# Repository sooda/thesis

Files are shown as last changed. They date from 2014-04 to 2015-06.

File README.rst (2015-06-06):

Multi-view stereo reconstruction for computer graphics content capture
======================================================================

Hello, this is my master's thesis work titled as above, and contains both the thesis text itself and some source code and electrical schematics developed during the work in Aalto University in 2014-2015.
For the occasional gibberish, consult a Finnish dictionary.
The technical "multi-view stereo reconstruction" is sometimes called "3D scanning": digitizing real-life object geometry from multiple photographs.
The practical work in this thesis was about building a rig for that purpose.
No reconstruction programs were written, unfortunately.
Try e.g. VisualSFM_ and MeshLab_ for that.

.. _VisualSFM: http://ccwu.me/vsfm/
.. _MeshLab: http://meshlab.sourceforge.net/

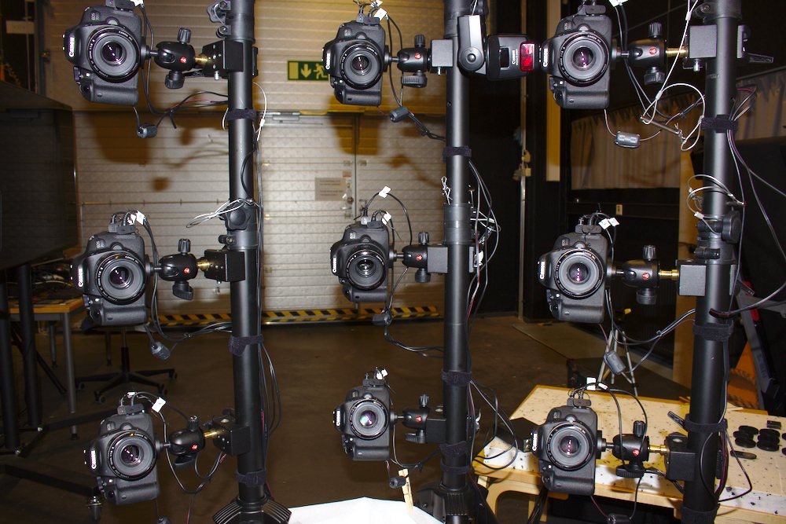
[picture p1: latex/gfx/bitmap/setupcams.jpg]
camera array


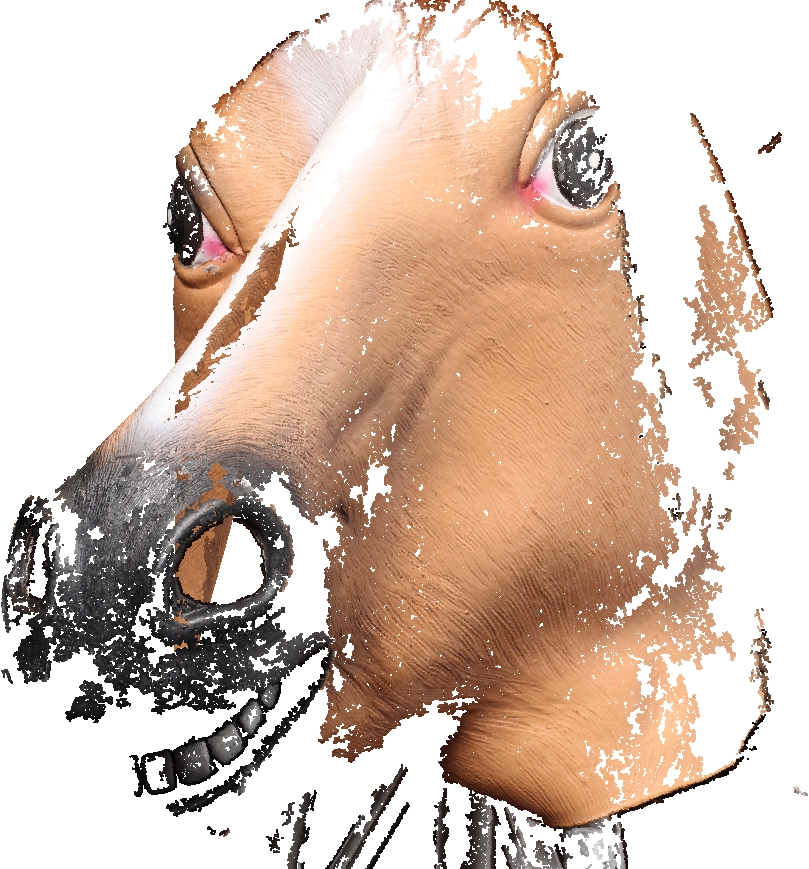
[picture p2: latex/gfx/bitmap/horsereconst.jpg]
horse mask rendering


Code
----

The thesis talks also about the background math, but the only code here is for controlling DSLRs remotely using gPhoto2_ in C++ and some shell scripts.
The tools were only tested using nine Canon EOS 700D cameras; no guarantees are given for others, but not much major changes are expected to be required.
I forgot to run valgrind on the final tool, so expect no warranty in memory leaks or any other errors.

.. _gPhoto2: http://gphoto.org/

The code here represents a prototype only, but it works for what was required, it's just not very polished.
I wrote a C++ wrapper for gphoto that is unimaginatively called *gpwrap*.
A preview tool (*gphotogrid*) downloads a live stream from each camera in parallel and allows the user to configure their parameters (aperture and such), with no significant performance optimizations or anything, as it's just a proof of concept.
The wrapper and the grid have been tested to work in recent versions of Linux and Mac OS X using the EOS 700Ds, but YMMV.
A more polished tool called `CaptureQuick`_ is developed on top of it by Daniel Thul; if you are going to use the wrapper for developing your own programs, or want the grid tool, look there too.
CaptureQuick still uses the wrapper written by me with only minor modifications (as of June 2015).
Expect it to grow further.

.. _CaptureQuick: https://github.com/dthul/capture-quick

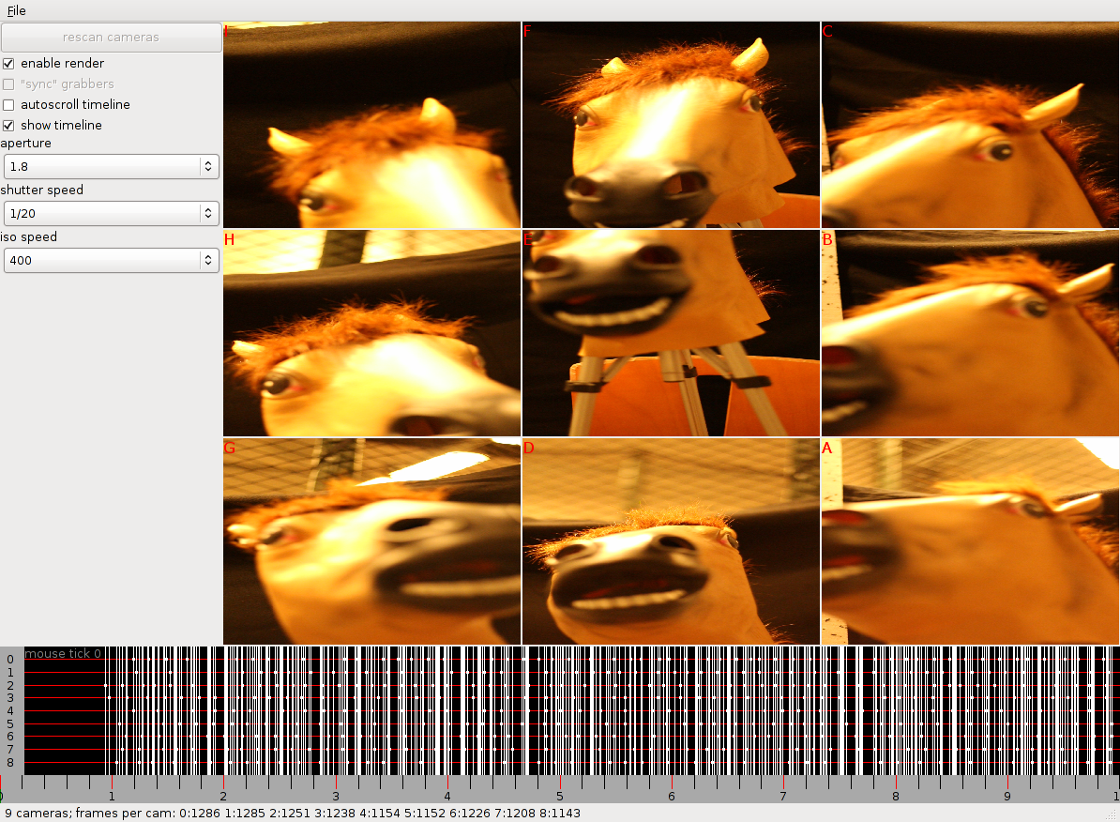
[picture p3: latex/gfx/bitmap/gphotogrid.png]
gphotogrid


Electronics
-----------

I built a simple remote tool for controlling the shutters of the nine cameras via a single usb-serial connection, in `arbitrary order`_ (typically simultaneously, though).
The control output goes directly to the 700Ds' shutter release inputs (a 2.5mm stereo jack).
The box has also a button for human interaction, and it's based on Nucleo-F401RE_, a simple STM32 board.
The schematics and the PCB are in EAGLE_ 7.0.0 format.
I named the thing *camsremote*.
No warranty.

.. _arbitrary order: https://www.youtube.com/watch?v=bDDnQzyOaFg
.. _Nucleo-F401RE: http://www.st.com/nucleoF401RE-pr
.. _EAGLE: http://www.cadsoftusa.com/eagle-pcb-design-software/

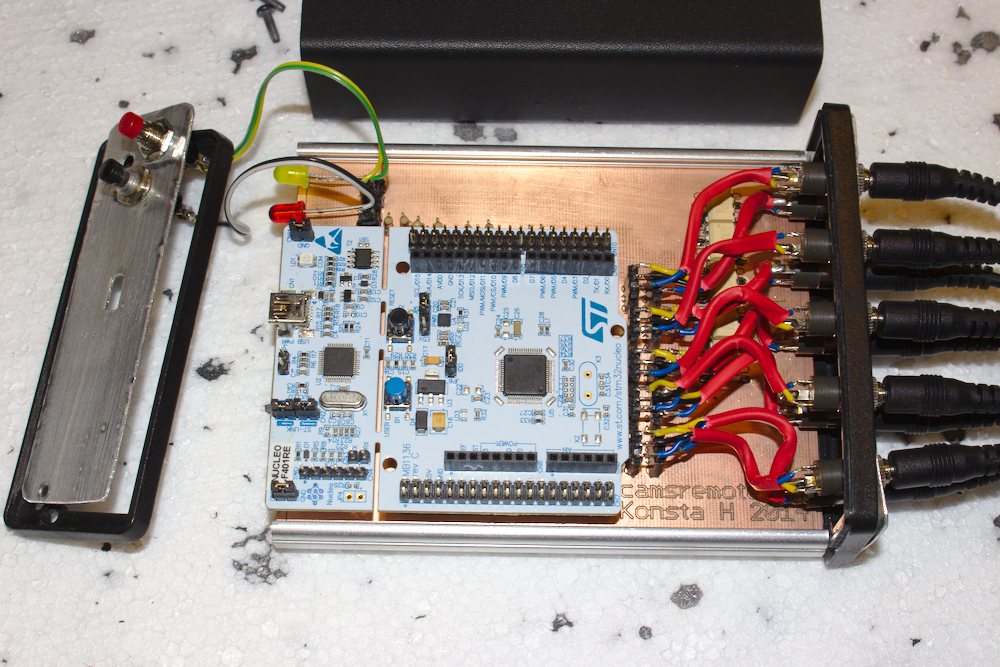
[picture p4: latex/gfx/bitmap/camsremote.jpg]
remote trigger tool


Abstract
--------

Rendering of photorealistic models is becoming increasingly feasible and important in computer graphics.
Due to the high amount of work in creating such models by hand, required by the need of high level of detail in geometry, colors, and animation, it is desirable to automate the model creation.
This task is realised by recovering content from photographs that describe the modeled subject from multiple viewpoints.
In this thesis, elementary theory on image acquisition and photograph-based reconstruction of geometry and colors is studied and recent research and software for graphics content reconstruction are reviewed.
Based on the studied background, a rig is built as a grid of nine off-the-shelf digital cameras, a custom remote shutter trigger, and supporting software.
The purpose of the rig is to capture high-quality photographs and video in a reliable and practical manner, to be processed in multi-view reconstruction programs.

The camera rig was configured to shoot small static subjects for experiments.
The resulting photos and video were then processed directly for the subject's geometry and color, with little or no image enhancements done.
Two typical reconstruction software pipelines were described and tested.
The rig was found to perform well for several subjects with little subject-specific tuning;
issues in the setup were analyzed and further improvements suggested based on the captured test models.
Image quality of the cameras was found to be excellent for the task, and most problems arose from uneven lighting and practical issues.
The developed rig was found to produce sub-millimeter scale accuracy in geometry and texture of subjects such as human faces.
Future work was suggested for lighting, video synchronization and study of state-of-the-art image processing and reconstruction algorithms.

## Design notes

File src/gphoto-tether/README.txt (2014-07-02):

Camera control scripts
======================

Some gphoto2 shell script fun. In alphabetical order:

camhook.sh:
	example for hooking captured files
camnames.sh:
	print a port-camname-mapping, or port of a single cam
cams.sh:
	list ports of all connected cameras
capture-by-camid.sh:
	capture tethered to <capname>/<camid>/<shotid>
capture-by-shotid.sh:
	capture tethered to <capname>/<shotid>/<camid>
config.sh:
	set common configuration parameters
	TODO: configuration tool for this?
	"./config.sh workaround": set only capture target to memory card,
	releases uilock if shutter is half-pressed to focus
configrepeatshot.sh:
	as above, for continuous cycle testing
forall.sh:
	run gphoto2 with given args for all connected cameras serially
forallp.sh:
	same as above, but in in parallel
interesting-settings.txt:
	settings for readconfig.sh, see below
multihax-order.py:
	interleave pictures taken from all cameras consecutively
multihax-run.sh:
	run the above in reverse cam order
	(if cams' shutter releases are connected so, needed a while ago)
post-download-by-camid.sh:
	download all previously shot files stored in the cameras to
	directories by camera name, in parallel; -DR is safe after this
rawprocess.sh:
	ufraw-batch converter to 2000x2000, run in a dir full of cr2's
readconfig.sh:
	read and copy settings from one camera to all others and dump
	the read data to a file for inspection, producing
	currentconfig.txt and calibsettings.sh
release-uilock.sh:
	run gphoto2 -L for all cams, this releases the locked buttons and
	blank screen that get stuck when fiddling with settings for some reason
shutters.sh:
	read shutter counters

delete all files recursively WITHOUT ASKING: ./forallp.sh -DR
  (appears to see only DCIM and MISC folders, ignores e.g. magic lantern)

list all files: ./forall.sh -L

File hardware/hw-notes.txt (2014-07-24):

hardware list:
	- 9x Canon EOS 700D
	- 9x Canon EF 50mm f/1.8 II lenses, no need to remove from the bodies
	- 9x Transcend 16GB memory cards, keep inside the cams
	- 9x Canon ACK-E8, power adapters because nobody wants to recharge batteries (that wire mess though...)
	- 3x D-link DUB-H4 usb hubs, remote powered but the power supplies don't seem to be needed for just the cams
	- 1x custom trigger box, connect with a mini usb
	- 9x wires for the cameras; usb to a hub, and 2,5mm stereo plug cable for the trigger
	- 4x Millenium LST-310 stand
	- 9x Manfrotto 494 ball head
	- 9x Manfrotto 035 Super Clamp, with Manfrotto 036-38 studs for attaching the ball heads to the stands
	- Lots of velcro straps

storage:
	- cases for cameras and other sensitive items
	- bags for the stands: one bag fits two
	- TODO: power cables, clamps, ballheads to stand bags or cases?

building:
	1. fix the stands where needed
	2. screw the cameras, ball heads and clamps together and to the stands
	3. connect the wires (power, usb, trigger) to the cameras; run them along the stands
	4. connect the power adapters to extension cords (can be replaced with batteries if using only for a few shots)
	5. connect the other ends of the trigger cables to the trigger box; connect a usb cable to the box
	6. use the velcro straps to fasten the dangling wires so that they stay away from the photos
	7. divide the hubs evenly for the cams, one hub per three or so; try to find different master hubs from a computer so that they would share the load well
	8. aim the cameras to the target, setup lighting and start shooting

unpacking:
	- just repeat the build steps in reverse order

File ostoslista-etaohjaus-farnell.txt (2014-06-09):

yht ~70 € (+ postit, kaikki euroopan varastoista).

10 * 3712552 (PRO SIGNAL - AV02019 - LEAD, 2.5MM STEREO PLG-PLG, 3M)
http://fi.farnell.com/pro-signal/av02019/lead-2-5mm-stereo-plg-plg-3m/dp/3712552

10 * 1200141 (LUMBERG - KLB 13 - SOCKET, 2.5MM JACK, CHASSIS)
http://fi.farnell.com/lumberg/klb-13/socket-2-5mm-jack-chassis/dp/1200141

2 * 2213347 (TWIN INDUSTRIES - TW-E41-1020 - BREADBOARD, SOLDERLESS, 830 TIE POINTS)
http://fi.farnell.com/twin-industries/tw-e41-1020/breadboard-solderless-830-tie-points/dp/2213347

1 * 2394223 (STMICROELECTRONICS - NUCLEO-F401RE - NUCLEO BOARD, STM32F401RET6 MCU)
http://fi.farnell.com/stmicroelectronics/nucleo-f401re/nucleo-board-stm32f401ret6-mcu/dp/2394223

1 * 1201477 (CIF - AJP16 - RPB PAD PROTOBOARD 100X160)
http://fi.farnell.com/cif/ajp16/rpb-pad-protoboard-100x160/dp/1201477

50 * 9339299 (MULTICOMP - MCF 0.25W 220R - RESISTOR, CARBON FILM, 220R, 0.25W, 5%)
http://fi.farnell.com/multicomp/mcf-0-25w-220r/resistor-carbon-film-220r-0-25w/dp/9339299

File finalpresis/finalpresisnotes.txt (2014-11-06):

1
first slide
- hi this is about 3d scanning

1
preintro
- cg evolves
- increasingly deeper demand for hq content
- parts of those two technologies combined

1
contents
- blah blah

2
motivation
- computer hw becoming faster and faster
- lod massive, development not going to stop
- generating content manually impossible
- static geometry is difficult enough
- and then there is computer animation
- -> just capture a subject in real life
- and reproduce that

2
imaging
- cameras are complicated.
- whole imaging process is complex
- especially to capture only surface color..
- instead of what it looks like in a naive environment
- diffuse (uniform) lighting etc
- cg, material models, imitate light reflection (pic)
- trying to produce color data for those models
- static imaging is difficult? how about video then?

4
video
- all right
- what is video anyway? frames in sequence
- assume photographed subject moving, otherwise no point
- capture N fps, integrating light fixed time
- and so we get many problems too
- motion blur: fast subject smeared as integrated
- rolling shutter: imaging sensor read slowly
- line skipping: aliasing etc: not every line used
- last but not least sync as group maybe impossible

5
simplified methods
- a camera is a projective object
- formulate properly -> divide to steps
- assume linear camera etc
- assume sth on scene
- detect distinct corners/features
- match features
- reconstruct depth for matches
- reconstruct surface

6
depth from disparity
- calculating depth not that complicated
- take two matching points, both projected linearly
- know camera baseline, poses, triangulate
- but wait, there is more
- how match in the first place?
- noise, outliers etc
- full pipeline does much more

7
stereo system
- step one. have many cameras.
- calibrate the cameras
- known geometry/autodetect matches
- system of eqs, similar projections
- depth/disparity > need poses for triangulation
- N views given -> match, triangulate, filter

8
practical reconstruction system
- now, what i built
- given knowledge, build *practical* 3d scanner
- interest in face, maybe animation
- looked in camera types, programs -> conclusions

9
rig implementation
- entry-level dslr
- controllable, cheap, hquality; cant sync video
- wired remote for still sync and shoot
- support magic lantern 3rd party fw addon
- supports, wiring
- cam ctrl utilities etc

10
remote trigger tool
- cams support wired remote
- built tool for concurrent shooting
- small cheap micro, usb conn
- commercial ones wireless, expensive, unknown
- did this for open design and testing

11
software
- sw consists of cam support, reconstruction then
- not much camera ctl libraries there
- just remote shoot, cam cfg in my work
- gphoto2, open source, image download etc

12
previewer
- graphical grid, simultaneous liveview
- individually with viewfinder

12
control
- some of params on the right
- gphoto also cli tool
- wrote small tool for concurrent fast download
- also python for remote box

13
experiments
- sync capabilities and scans
- performing full end-to-end pipeline in sw

14
source data
- 3 of 9 pics for full head scan

14
output geometry
- plain reconstructed geometry rendered
- point cloud, tex mesh
- poor quality in facial hair

15
textures
- color: different map types
- one preserves the original photographs
- othereasily modifiable image

15
hand
- this is my hand scanned
- occluded areas, not seen by all

15
legos
- missing texture is obviously not recoverable

16
rubber mask
- uniform colors bad, otherwise nice

16
level of detail
- cropped part of one photo, its reconstruction
- pore-level pixels
- note geometric detail near the eyes
- some wrinkles only in color, not geometry

16
issues
- video sync is problematic
- once started, cannot sync frames
- require no shadows, reflections
- needs manual processing to be useful
- the cameras sometimes misbehave a little

17
future work
- survey current state-art algos, high lod
- of course, use it for future study

18
conclusion
- that's it.
- my work: survey background, build 3d scanner
- quality nice and improvable from the current state
- i don't know what the future is going to offer

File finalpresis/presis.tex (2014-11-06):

\documentclass[first=purple,second=dgreen,logo=blueexc]{aaltoslides}

\usepackage[latin9]{inputenc}
\usepackage[T1]{fontenc}
\usepackage{graphicx}
\usepackage{amsfonts,amssymb,amsbsy,amsmath}
\usepackage{tikz}
\usepackage{url}
\usepackage{lastpage}
\usepackage{subfig}
\usepackage{fancyvrb}

\title{Multi-view stereo reconstruction for computer graphics content capture}

\author{Konsta Hölttä}
\institute{Master's thesis presentation\\
konsta.holtta@aalto.fi}

\aaltofootertext{MVS content capture}{Nov 7, 2014}{\arabic{page}/\pageref{LastPage}\ }

\date{Nov 7, 2014} % \today}

\graphicspath{ {gfx/} }

\newcommand{\kuva}[2]{\begin{figure}[h]
		
\end{figure}}

\newcommand{\simplefig}[4]{%
	\begin{figure}[#1]\begin{center}
		#2
		%\caption{#4}
		%\label{#3}
	\end{center}\end{figure}
}
% \simplegfx{pos-specifier}{width}{filename-and-labelname}{caption}
\newcommand{\simplegfx}[4]{%
	\simplefig{#1}{}{fig:#3}{#4}
}

\begin{document}

%%%%%%%%%%%%%%%%%%%%%%%%%%%%%%%%%%%%%%%%%%%%%%%%%%%%%%%%%%%%%%%%%%%%%%%%%%%%%%%%%%%%%%%%%%%%%

\aaltotitleframe

%%%%%%%%%%%%%%%%%%%%%%%%%%%%%%%%%%%%%%%%%%%%%%%%%%%%%%%%%%%%%%%%%%%%%%%%%%%%%%%%%%%%%%%%%%%%%

\begin{frame}{Multi-view stereo reconstruction for computer graphics content capture}
	\center 
	\begin{itemize}
		\item Interest in realistic content in computer graphics
		\item Computer graphics synthesizes images from geometric data
		\item Computer vision analyzes geometry from images
		\item This work: Scanning real life objects using several digital cameras simultaneously
	\end{itemize}
\end{frame}

%%%%%%%%%%%%%%%%%%%%%%%%%%%%%%%%%%%%%%%%%%%%%%%%%%%%%%%%%%%%%%%%%%%%%%%%%%%%%%%%%%%%%%%%%%%%%

\begin{frame}{Contents}
	\begin{columns}[c]
	\column{0.5\textwidth}
	\begin{itemize}
		\item Intro, motivation
		\item Imaging fundamentals
		\item 3D reconstruction
		\item Scanning rig implementation
		\item Results
		\item Conclusion
	\end{itemize}
	\column{0.5\textwidth}
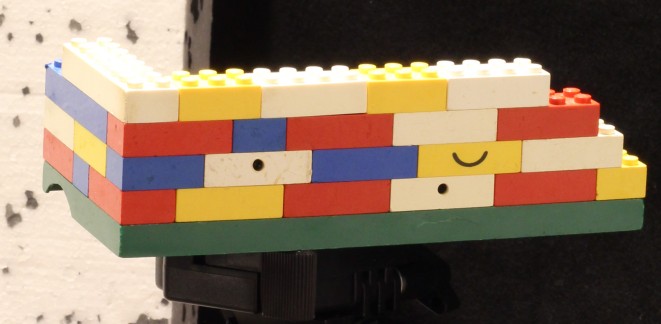
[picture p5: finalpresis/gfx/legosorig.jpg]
	\center 
	\end{columns}
\end{frame}

%%%%%%%%%%%%%%%%%%%%%%%%%%%%%%%%%%%%%%%%%%%%%%%%%%%%%%%%%%%%%%%%%%%%%%%%%%%%%%%%%%%%%%%%%%%%%

\begin{frame}{Motivation}
	\kuva{0.8}{ira-eyes}
	{ \centering { \footnotesize Digital Ira (NVIDIA), CGI} \par }
	\begin{itemize}
		\item The processing power of GPUs big and increases
		\item Able to process massive level of detail
		\item Creating content manually tedious, difficult to get right
		\item Digital cameras are really good today
		\item $\Rightarrow$ Scan the geometry and color using digital cameras
	\end{itemize}
\end{frame}

%%%%%%%%%%%%%%%%%%%%%%%%%%%%%%%%%%%%%%%%%%%%%%%%%%%%%%%%%%%%%%%%%%%%%%%%%%%%%%%%%%%%%%%%%%%%%

\begin{frame}{Imaging}
	\center 
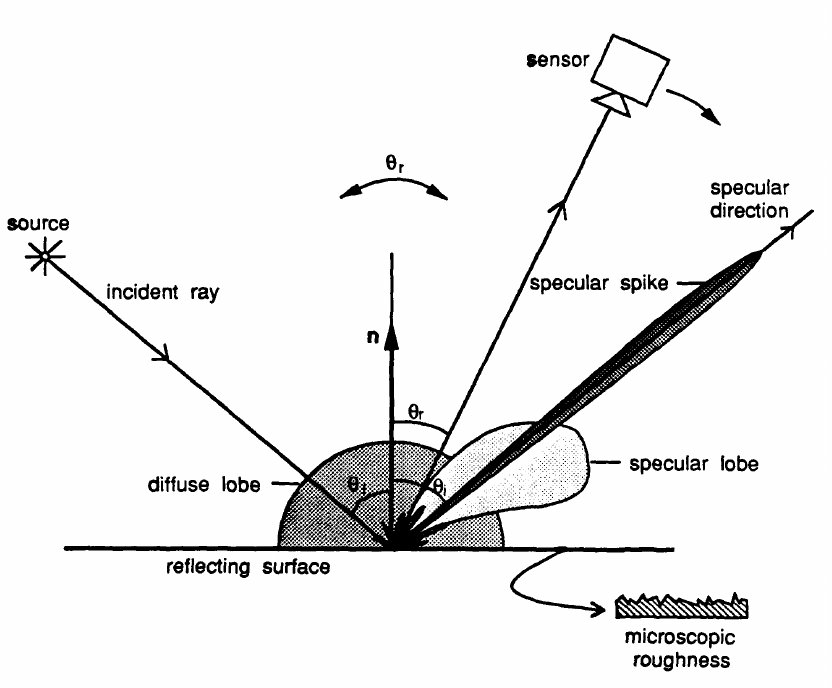
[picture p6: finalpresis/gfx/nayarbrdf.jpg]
	
	\begin{itemize}
		\item Lens systems, geometric distortion, color distortion, depth of field, image resolution, frame rate, motion blur, compression quality, ...
		\item Complete imaging pipeline is complex
		\item Light travels from subject to sensor, to digital file
		\item Assumed uniform lighting; still, non-shiny subject
		\item Video = consecutive image frames
	\end{itemize}
\end{frame}

%%%%%%%%%%%%%%%%%%%%%%%%%%%%%%%%%%%%%%%%%%%%%%%%%%%%%%%%%%%%%%%%%%%%%%%%%%%%%%%%%%%%%%%%%%%%%

\begin{frame}{Video}
	\begin{columns}[c]
	\column{0.5\textwidth}
	\begin{itemize}
		\item Frame after frame
		\item Moving subject
		\item Non-flickering lighting
		\item Motion blur
		\item Rolling shutter
		\item Line skipping
		\item Synchronization
	\end{itemize}
	\column{0.5\textwidth}
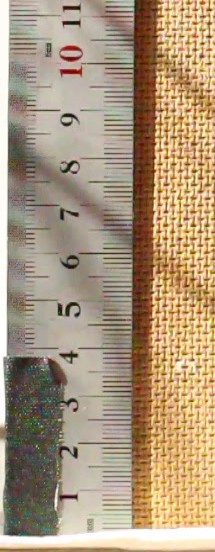
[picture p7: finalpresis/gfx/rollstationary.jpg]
	
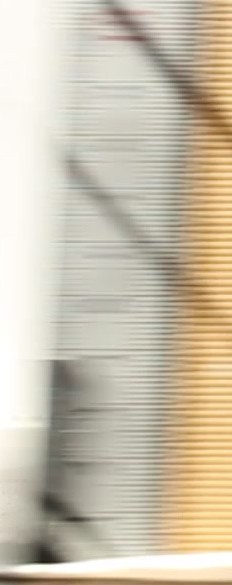
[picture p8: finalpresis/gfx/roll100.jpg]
	
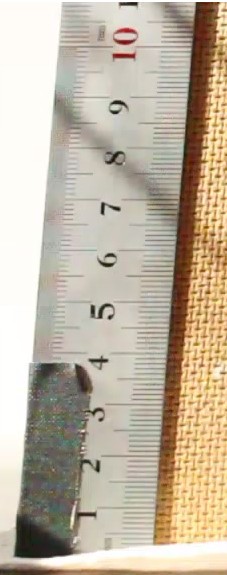
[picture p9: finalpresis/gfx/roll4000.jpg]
	
	\end{columns}
\end{frame}

%%%%%%%%%%%%%%%%%%%%%%%%%%%%%%%%%%%%%%%%%%%%%%%%%%%%%%%%%%%%%%%%%%%%%%%%%%%%%%%%%%%%%%%%%%%%%

\begin{frame}{Simplified methods}
	\center 
	\begin{itemize}
		\item Linear camera model, simple optical distortion models, orthogonal problems as separate steps
		\item Assumptions, corner detection, correspondence matching, triangulation, surface reconstruction, ...
	\end{itemize}
\end{frame}

%%%%%%%%%%%%%%%%%%%%%%%%%%%%%%%%%%%%%%%%%%%%%%%%%%%%%%%%%%%%%%%%%%%%%%%%%%%%%%%%%%%%%%%%%%%%%

\begin{frame}{2D to 3D: depth from disparity}
	\begin{columns}[c]
	\column{0.5\textwidth}
	\begin{itemize}
		\item Just simple triangulation, in principle
		\item Two views, two positions in images $\Rightarrow$ 3D position with depth
		\item In practice, many more sophisticated dense algos
		\item Complete pipeline needs to consider everything
	\end{itemize}
	\column{0.5\textwidth}
	
	\end{columns}
\end{frame}

%%%%%%%%%%%%%%%%%%%%%%%%%%%%%%%%%%%%%%%%%%%%%%%%%%%%%%%%%%%%%%%%%%%%%%%%%%%%%%%%%%%%%%%%%%%%%

\begin{frame}{(Multi-)Stereo system}
	\center 
	\begin{itemize}
		\item Manual or self-calibration for cameras
		\item Reconstruct 3D geometry $\Leftrightarrow$ apply projection in inverse
		\item Need camera poses
		\item Reconstruct 3D view
		\item Determine scene from multiple viewpoints
	\end{itemize}
\end{frame}

%%%%%%%%%%%%%%%%%%%%%%%%%%%%%%%%%%%%%%%%%%%%%%%%%%%%%%%%%%%%%%%%%%%%%%%%%%%%%%%%%%%%%%%%%%%%%

\begin{frame}{Practical reconstruction system}
	\hfill
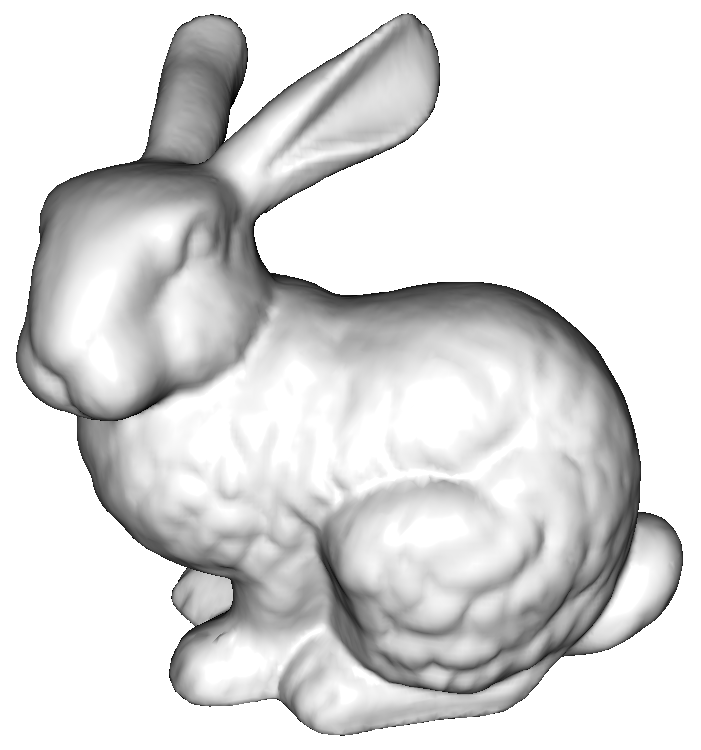
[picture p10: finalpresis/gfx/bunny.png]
	
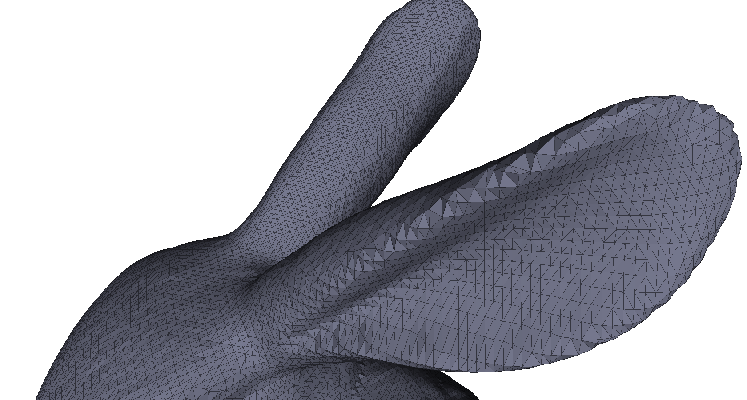
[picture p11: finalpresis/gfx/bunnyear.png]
	
	\begin{itemize}
		\item Background theory $\Rightarrow$ construct a reconstruction rig
		\item Acquire a geometric model of a subject
		\item Flexible and general purpose, easy to use
		\item Human head special interest
		\item Heavy study on available hardware and software
	\end{itemize}
\end{frame}

%%%%%%%%%%%%%%%%%%%%%%%%%%%%%%%%%%%%%%%%%%%%%%%%%%%%%%%%%%%%%%%%%%%%%%%%%%%%%%%%%%%%%%%%%%%%%

\begin{frame}{Rig implementation}
	\begin{columns}[c]
	\column{0.5\textwidth}
	\begin{itemize}
		\item 9x Canon EOS 700D DSLR, 50 mm lens
		\item Wired remote trigger tool
		\item Magic Lantern
		\item auxiliary HW, support SW
		\item Not restricted to any specific reconstruction SW
	\end{itemize}
	\column{0.5\textwidth}
	
	\end{columns}
\end{frame}

%%%%%%%%%%%%%%%%%%%%%%%%%%%%%%%%%%%%%%%%%%%%%%%%%%%%%%%%%%%%%%%%%%%%%%%%%%%%%%%%%%%%%%%%%%%%%

\begin{frame}{Remote trigger tool}
	%
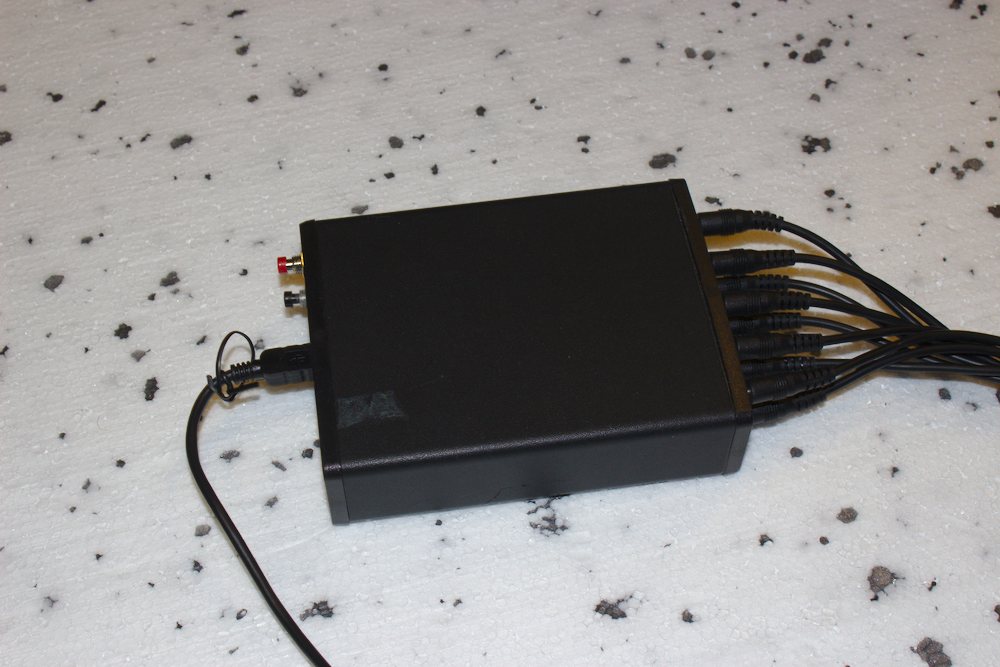
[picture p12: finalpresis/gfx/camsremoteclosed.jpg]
	
	\begin{itemize}
		\item Simultaneous or arbitrary focus/shutter release
		\item Custom built on a microcontroller using standard wired remote connections and a USB port
		\item Commercial tools mostly wireless, expensive
	\end{itemize}
\end{frame}

%%%%%%%%%%%%%%%%%%%%%%%%%%%%%%%%%%%%%%%%%%%%%%%%%%%%%%%%%%%%%%%%%%%%%%%%%%%%%%%%%%%%%%%%%%%%%

\begin{frame}{Software}
	\begin{itemize}
		\item Few options available
		\item Just camera controls, based on \emph{gphoto2}
		\item Generic open source library for cameras in C
		\item Preview tool, image download, camera configuration, remote shutter
		\item 3D reconstruction development out of scope
	\end{itemize}
\end{frame}

%%%%%%%%%%%%%%%%%%%%%%%%%%%%%%%%%%%%%%%%%%%%%%%%%%%%%%%%%%%%%%%%%%%%%%%%%%%%%%%%%%%%%%%%%%%%%

\begin{frame}{Previewer}
	\center 
	\begin{itemize}
		\item A great aid in aiming the rig as a whole
		\item Individual orientations with the viewfinders though
	\end{itemize}
\end{frame}

%%%%%%%%%%%%%%%%%%%%%%%%%%%%%%%%%%%%%%%%%%%%%%%%%%%%%%%%%%%%%%%%%%%%%%%%%%%%%%%%%%%%%%%%%%%%%

\begin{frame}[fragile]{Control}
	\begin{columns}[c]
	\column{0.5\textwidth}
	\begin{itemize}
		\item Camera exposes parameters via USB
		\item Shutter speed, aperture, ...
		\item Mostly implemented in gphoto2 CLI
		\item Image download as soon as captured
		\item USB connection to remote trigger box (Python)
	\end{itemize}
	\column{0.5\textwidth}
	\begin{Verbatim}[fontsize=\scriptsize]
./forallp.sh \
	--set-config imageformat="RAW" \
	--set-config imageformatsd="RAW" \
	--set-config shutterspeed="1/100" \
	--set-config iso="100" \
	--set-config colorspace="sRGB" \
	--set-config picturestyle="Standard" \
	--set-config focusmode="One Shot" \
	--set-config aperture="11" \
	--set-config meteringmode="Evaluative" \
	--set-config drivemode="Single" \
	--set-config capturetarget="Memory card"
	\end{Verbatim}
	\end{columns}
\end{frame}

%%%%%%%%%%%%%%%%%%%%%%%%%%%%%%%%%%%%%%%%%%%%%%%%%%%%%%%%%%%%%%%%%%%%%%%%%%%%%%%%%%%%%%%%%%%%%

\begin{frame}{Experiments}
	\begin{columns}[c]
	\column{0.5\textwidth}
	\begin{itemize}
		\item Synch tests
		\item Sample scans
		\item A few reconstruction programs tested
		\item Numerous libraries and commercial tools reviewed
		% list some of the tools?
	\end{itemize}
	\column{0.5\textwidth}
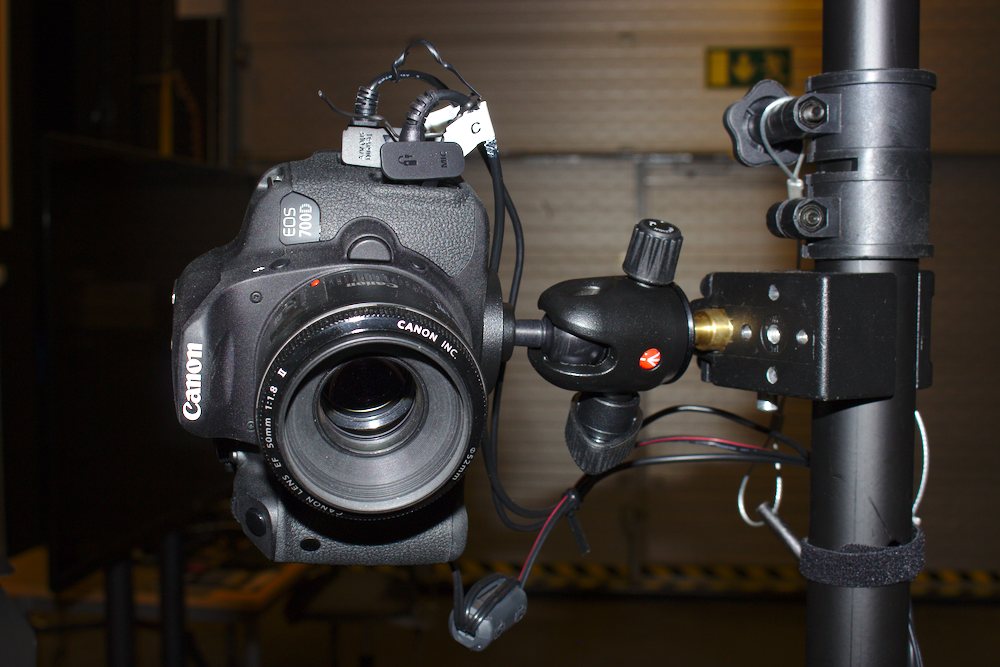
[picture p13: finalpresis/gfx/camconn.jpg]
	
	\end{columns}
\end{frame}

%%%%%%%%%%%%%%%%%%%%%%%%%%%%%%%%%%%%%%%%%%%%%%%%%%%%%%%%%%%%%%%%%%%%%%%%%%%%%%%%%%%%%%%%%%%%%

\begin{frame}{Source data}
\center
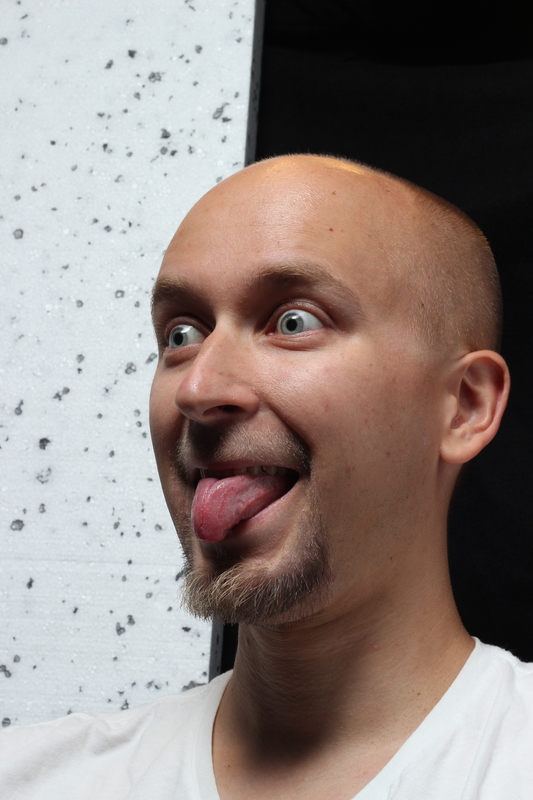
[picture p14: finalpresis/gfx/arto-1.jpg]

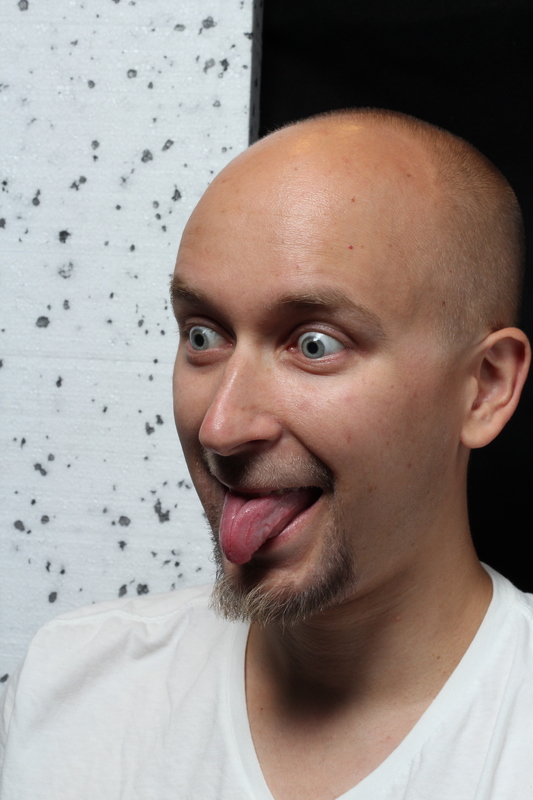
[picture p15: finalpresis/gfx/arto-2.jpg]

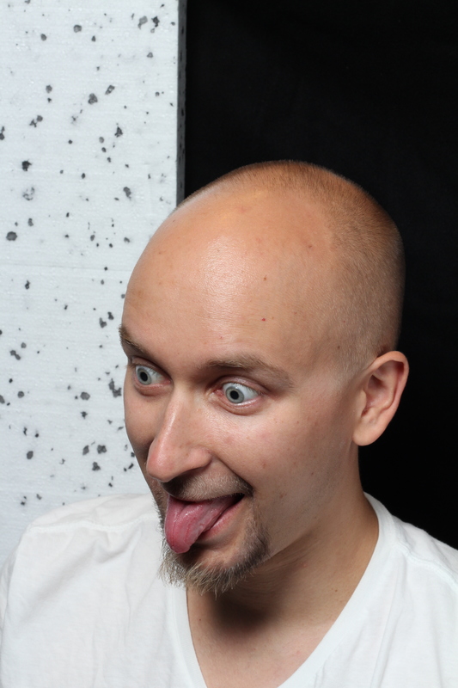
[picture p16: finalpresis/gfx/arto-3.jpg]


18 Mpix per cam
\end{frame}

%%%%%%%%%%%%%%%%%%%%%%%%%%%%%%%%%%%%%%%%%%%%%%%%%%%%%%%%%%%%%%%%%%%%%%%%%%%%%%%%%%%%%%%%%%%%%

\begin{frame}{Output geometry}
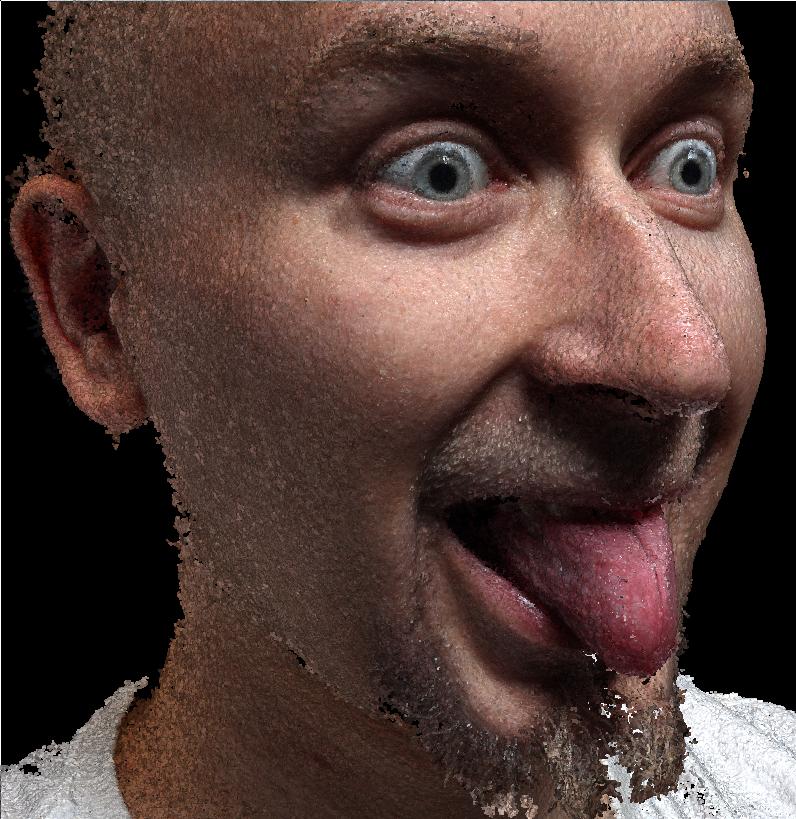
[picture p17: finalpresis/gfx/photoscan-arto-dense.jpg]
%
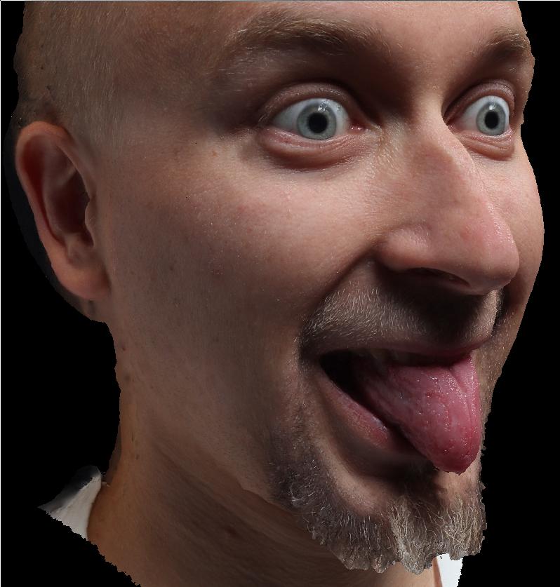
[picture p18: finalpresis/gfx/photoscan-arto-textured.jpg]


1-5M points
\end{frame}

%%%%%%%%%%%%%%%%%%%%%%%%%%%%%%%%%%%%%%%%%%%%%%%%%%%%%%%%%%%%%%%%%%%%%%%%%%%%%%%%%%%%%%%%%%%%%

\begin{frame}{Textures}
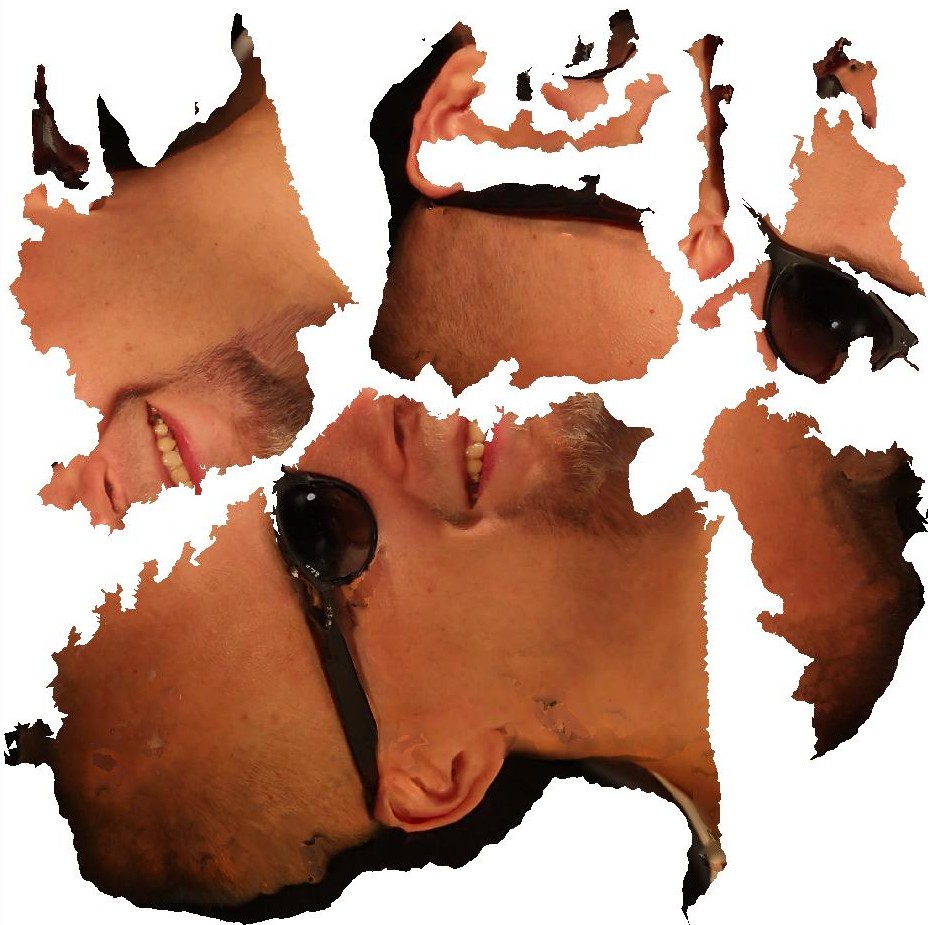
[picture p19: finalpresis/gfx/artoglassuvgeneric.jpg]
%
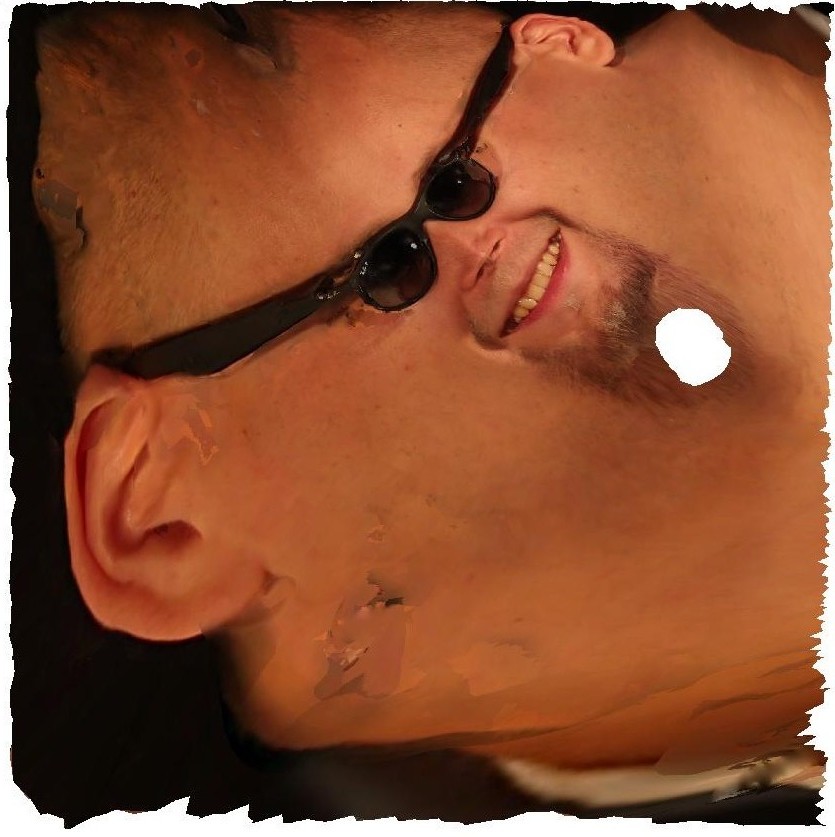
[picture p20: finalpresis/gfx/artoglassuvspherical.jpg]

\end{frame}

%%%%%%%%%%%%%%%%%%%%%%%%%%%%%%%%%%%%%%%%%%%%%%%%%%%%%%%%%%%%%%%%%%%%%%%%%%%%%%%%%%%%%%%%%%%%%

\begin{frame}{Hand}
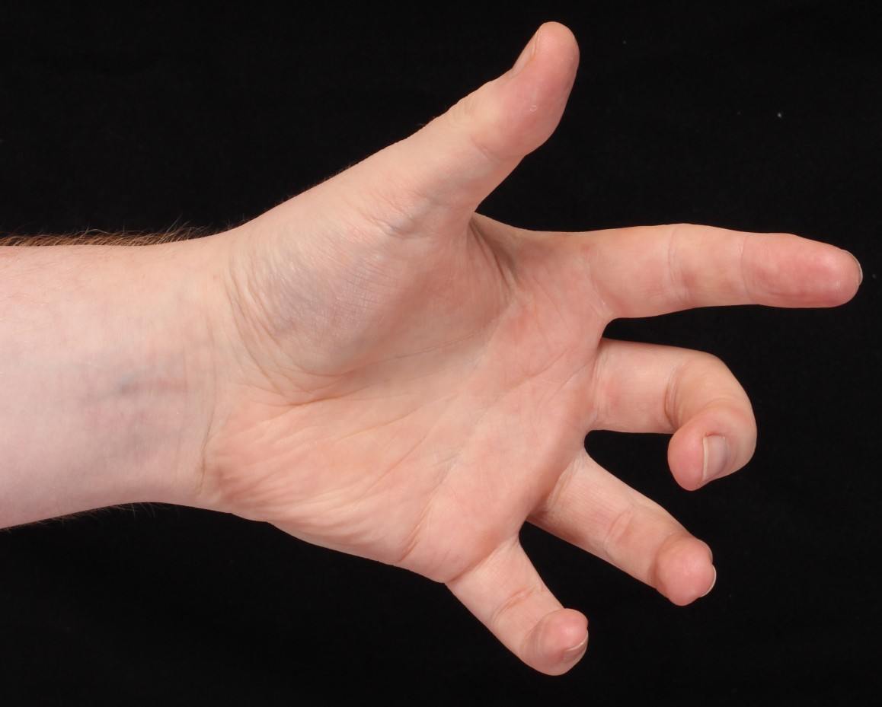
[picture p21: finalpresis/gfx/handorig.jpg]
%
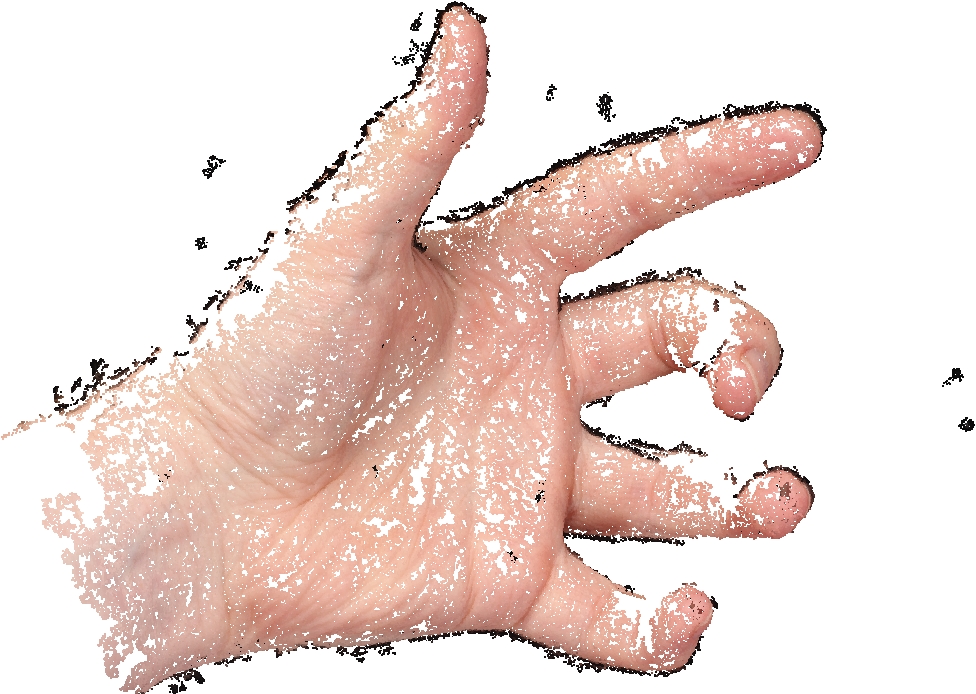
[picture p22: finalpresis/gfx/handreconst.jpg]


Occlusion issues
\end{frame}

%%%%%%%%%%%%%%%%%%%%%%%%%%%%%%%%%%%%%%%%%%%%%%%%%%%%%%%%%%%%%%%%%%%%%%%%%%%%%%%%%%%%%%%%%%%%%

\begin{frame}{Legos}
\center
\\
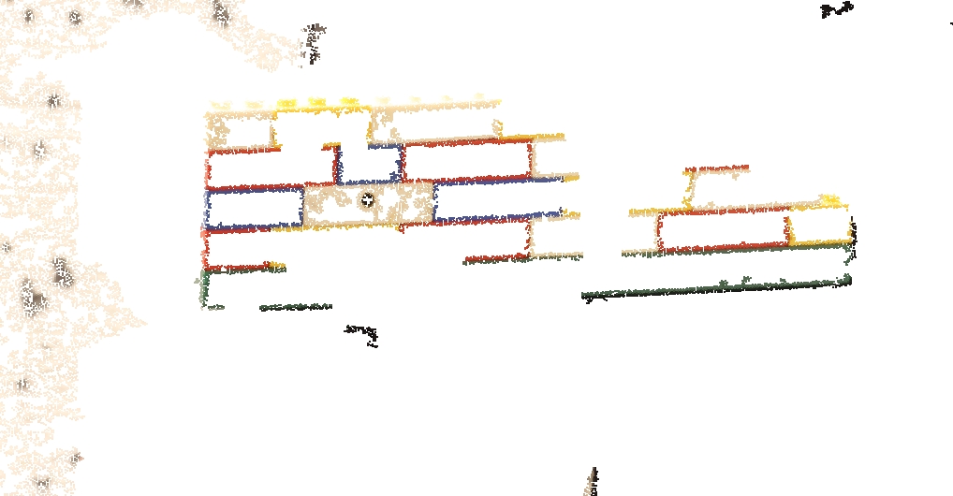
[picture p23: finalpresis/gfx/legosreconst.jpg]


No texture
\end{frame}

%%%%%%%%%%%%%%%%%%%%%%%%%%%%%%%%%%%%%%%%%%%%%%%%%%%%%%%%%%%%%%%%%%%%%%%%%%%%%%%%%%%%%%%%%%%%%

\begin{frame}{Rubber horse mask}
\center
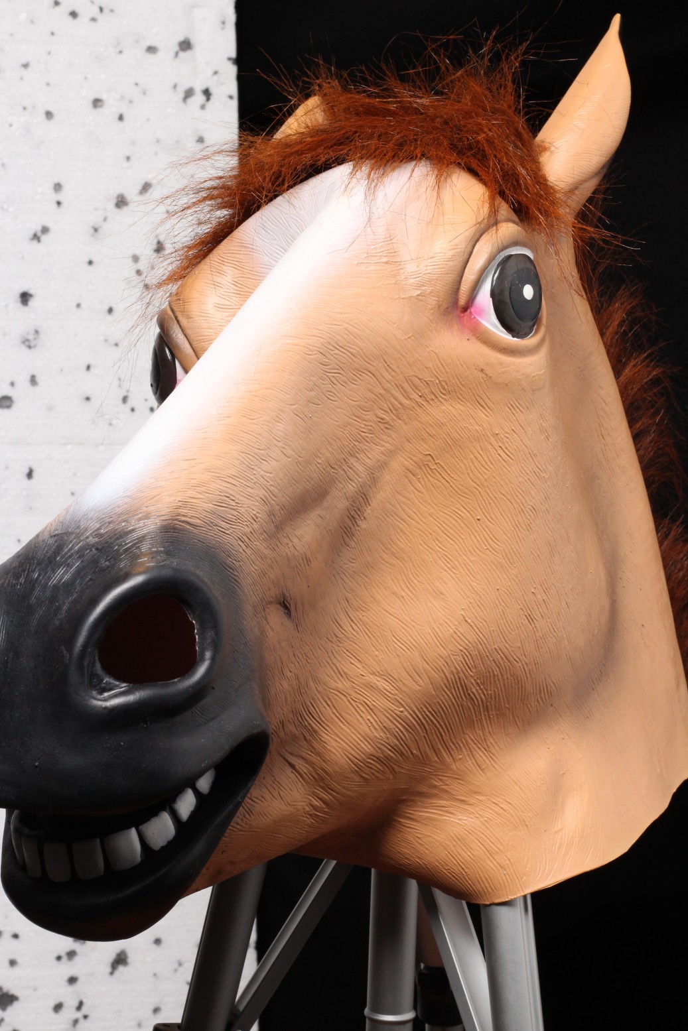
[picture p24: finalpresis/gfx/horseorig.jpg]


\center

Uniform color areas
\end{frame}

%%%%%%%%%%%%%%%%%%%%%%%%%%%%%%%%%%%%%%%%%%%%%%%%%%%%%%%%%%%%%%%%%%%%%%%%%%%%%%%%%%%%%%%%%%%%%

\begin{frame}{Level of detail}
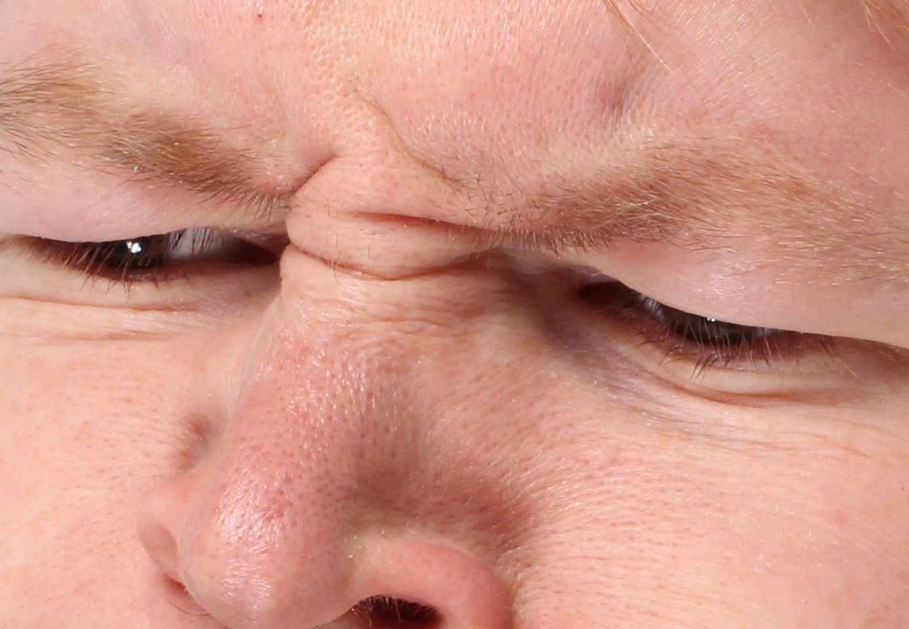
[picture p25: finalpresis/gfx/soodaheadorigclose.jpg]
\center \\

\end{frame}

%%%%%%%%%%%%%%%%%%%%%%%%%%%%%%%%%%%%%%%%%%%%%%%%%%%%%%%%%%%%%%%%%%%%%%%%%%%%%%%%%%%%%%%%%%%%%

\begin{frame}{Issues}
	\begin{columns}[c]
	\column{0.5\textwidth}
	\begin{itemize}
		\item Video synchronization
		\item Light requirements
		\item Post processing
		\item Camera quirks
	\end{itemize}
	\column{0.5\textwidth}
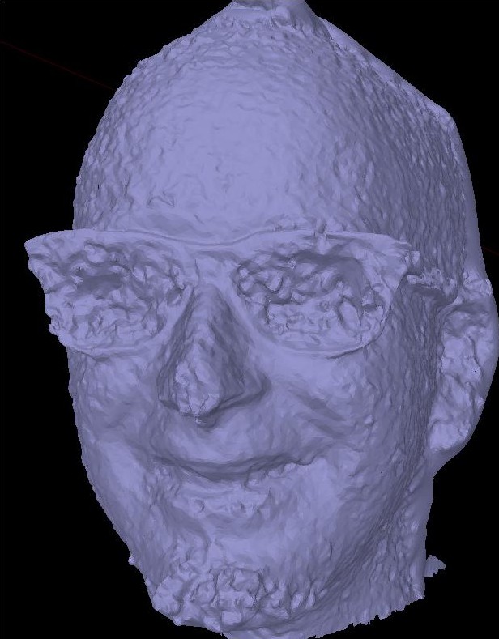
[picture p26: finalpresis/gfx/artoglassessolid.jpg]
	
	\end{columns}
\end{frame}

%%%%%%%%%%%%%%%%%%%%%%%%%%%%%%%%%%%%%%%%%%%%%%%%%%%%%%%%%%%%%%%%%%%%%%%%%%%%%%%%%%%%%%%%%%%%%

\begin{frame}{Future work}
	\begin{columns}[c]
	\column{0.5\textwidth}
	\begin{itemize}
		\item Actually use the rig
		\item Reproduce state-of-the-art
		\item Mesoscopic face geometry
		\item Research new ways
	\end{itemize}
	\column{0.5\textwidth}
	
	\end{columns}
\end{frame}

%%%%%%%%%%%%%%%%%%%%%%%%%%%%%%%%%%%%%%%%%%%%%%%%%%%%%%%%%%%%%%%%%%%%%%%%%%%%%%%%%%%%%%%%%%%%%

\begin{frame}{Conclusion}
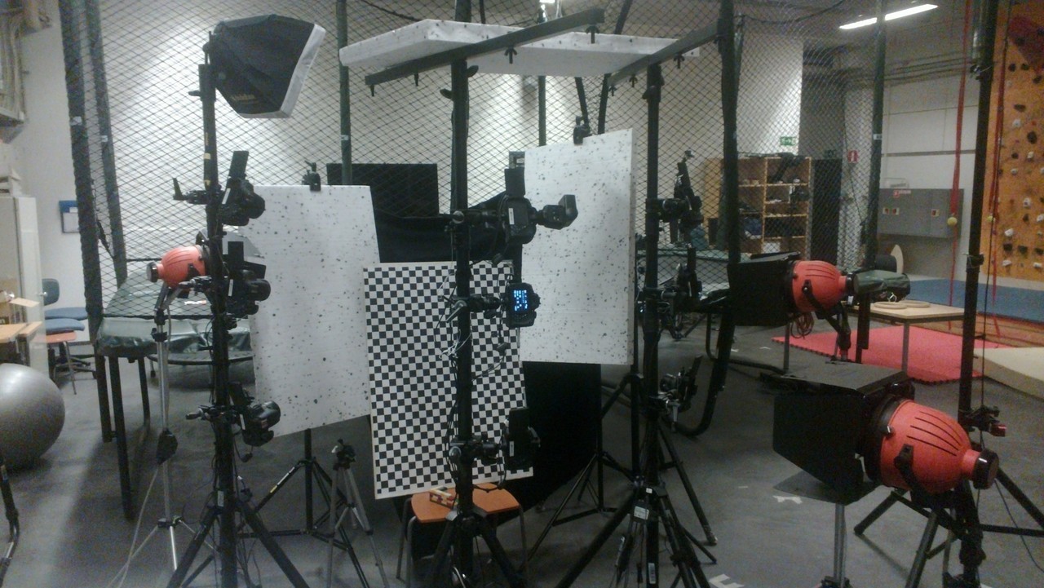
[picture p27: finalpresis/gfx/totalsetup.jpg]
	\center 
	\begin{itemize}
		\item Background and feasibility study $\Rightarrow$ built reconstruction rig
		\item Sub-millimeter-scale content
		\item Data needs post-processing
		\item Future work: actually use it
	\end{itemize}
\end{frame}

%%%%%%%%%%%%%%%%%%%%%%%%%%%%%%%%%%%%%%%%%%%%%%%%%%%%%%%%%%%%%%%%%%%%%%%%%%%%%%%%%%%%%%%%%%%%%

\end{document}

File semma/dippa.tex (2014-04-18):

\documentclass[english,12pt,a4paper,pdftex]{article}
%\documentclass[english,12pt,a4paper,dvips]{article}

\usepackage[elec,utf8]{aaltothesis}

% pdflatex, gfx in jpg/pdf
\usepackage{graphicx}
%\usepackage{url}
\usepackage[pdfpagemode=None,colorlinks=true,urlcolor=red,%
linkcolor=blue,citecolor=black,pdfstartview=FitH]{hyperref}
\usepackage[comma,sort&compress,numbers]{natbib}

\usepackage{amsfonts,amssymb,amsbsy,amsmath}
\usepackage{tikz}

%\input{gfx/bayer}
% \simplefig{pos-specifier}{contents}{labelname}{caption}
\newcommand{\simplefig}[4]{%
	\begin{figure}[#1]\begin{center}
		#2
		\caption{#4}
		\label{#3}
	\end{center}\end{figure}
}
% \simplegfx{pos-specifier}{width}{filename-and-labelname}{caption}
\newcommand{\simplegfx}[4]{%
	\simplefig{#1}{}{fig:#3}{#4}
}

\setlength{\hoffset}{-1in}
\setlength{\oddsidemargin}{35mm}
\setlength{\evensidemargin}{25mm}
\setlength{\textwidth}{15cm}

\setlength{\voffset}{-1in}
\setlength{\headsep}{7mm}
\setlength{\headheight}{1em}
\setlength{\topmargin}{25mm-\headheight-\headsep}
\setlength{\textheight}{23cm}

\begin{document}

\department{Department of Automation and systems technology}%
{Automaatio- ja systeemitekniikan laitos}
\professorship{automagic}{automagia}
\code{AS-1337}

\univdegree{MSc}

\author{Konsta Hölttä}

% a rig for multi-view stereo reconstruction of facial movement
\thesistitle{Non-static Object Capture Using Multi-view Stereo Video}{Dippa}

\place{Espoo}
\date{18.4.2014}

\supervisor{Prof.\ Ville Kyrki}{Prof.\ Ville Kyrki}
\instructor{Prof.\ Jaakko Lehtinen}{Prof. Jaakko Lehtinen}

\uselogo{aaltoPurple}{!}

\makecoverpage
%\newpage

\thesistableofcontents

%\include{tex/syms-opers-abbrs}

\cleardoublepage
\storeinipagenumber
\pagenumbering{arabic}
\setcounter{page}{1}

% Two cam Stereo
% Multi-view Stereo
\include{tex/introduction}
%\include{tex/background}
\include{tex/imaging}
%\include{tex/camera-calibration}
\include{tex/stereo-vision}
\include{tex/object-tracking}
\include{tex/software-tools}
\include{tex/applications}
\include{tex/summary}

\phantomsection
\addcontentsline{toc}{section}{References}
\bibliographystyle{unsrt}
\bibliography{dippa}

\appendix
\clearpage
% liitteet
%\phantomsection
%\addtocontents{toc}{\protect\contentsline{section}{Appendices}{}{appendix}}

%\include{tex/appendix}

\end{document}

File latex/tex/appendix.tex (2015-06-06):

\section{List of hardware} \label{app:hardwareused}

The hardware listed below is a comprehensive minimal list that is required for the system.
Additionally, light sources should be used as necessary.

\begin{itemize}
	\item 9 x Canon EOS 700D DSLR camera body
	\item 9 x Canon EF 50mm f/1.8 II lens
	\item 9 x Canon ACK-E8 Power adapter
	\item 9 x Transcend SDHC class 10 UHS-I 16GB memory card
	\item 9 x Manfrotto 494 ball head
	\item 9 x Manfrotto 035 Super Clamp, with Manfrotto 036-38 studs
	\item 3 x D-link DUB-H4 USB hub
	\item 4 x Millenium LST-310, a three-legged lighting stand
	\item Custom built remote trigger board using ST Nucleo-F401RE, see Section \ref{app:remotetrigger}
	\item Canon RC-6 wireless remote control for testing
	\item Auxiliary extension cords
	\item 2 x bags for the stands
	\item 2 x hard equipment cases with cut holes for all fragile parts of the rig
\end{itemize}

%\clearpage

\section{Remote trigger} \label{app:remotetrigger}

The designed remote trigger consists of a Nucleo-F401RE microcontroller platform by ST microelectronics \cite{stnucleo}, and supporting hardware for connecting the cameras.
The microcontroller was programmed using the Mbed library \cite{mbednucleo}.
Each camera connects to the trigger via a 2.5mm stereo plug, as the cameras have a standard 2.5mm jack for remote trigger.
To drive the cameras individually, the remote wires are connected with opto-isolators (TLP621-2).

The ground signals of the isolators in the built circuit are connected together by mistake, so the cameras are not completely isolated; only their signal wires are.
However, common grounding is generally not an issue.
Furthermore, the USB connections of all cameras also connect to each other and to the trigger box via the computer they are connected to, which cannot be easily circumvented.
The git repository contains the project files in a format for the Cadsoft EAGLE pcb design software \cite{eaglepcb}.
The diagrams for schematic and PCB layout are given here for illustration only.

\subsection{Schematic} \label{app:fullschematic}

\simplefig{p}{%
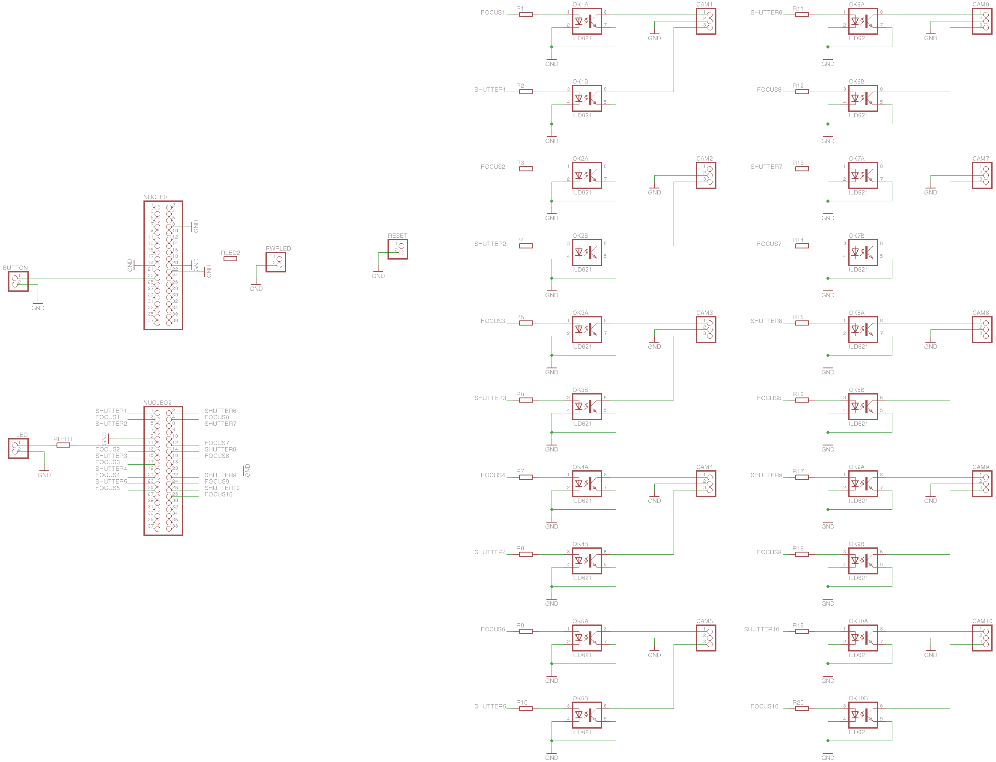
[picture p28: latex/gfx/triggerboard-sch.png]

}{fig:triggerboard-sch-big}
{Remote trigger schematic}

See Figure \ref{fig:triggerboard-sch-big} for a complete schematic.
The two pin headers are those of the Nucleo board, and the order of the opto-isolators and connectors matches with the physical order of the connectors on the PCB.
Additionally, the LEDs and buttons were routed to the side of the board to be accessible when installed in the enclosure.

\subsection{Printed circuit board layout}

\simplefig{p}{%

}{fig:triggerboard-brd-big}
{Remote trigger circuit board (PCB) layout}

The circuit board dimensions are 5 x 3.9 inches (approximately 127 x 99 mm) designed to fit in the given enclosure.
All electrical connections can be realized with just one layer;
another layer was used as a ground plane, but the ground signals are routed also along with the signals.
The circuit is also simple enough to implement on a prototyping board with jumper wires.
Figure \ref{fig:triggerboard-brd-big} shows the board layout without a ground plane drawn.

\subsection{Complete device}

% just enough width to fit both in a single page
\simplefig{p}{%

}{fig:camsremote-closed}
{The remote tool enclosure with the lid closed and wires connected}
\simplefig{p}{%

}{fig:camsremote-full}
{Components installed to the board and fitted in the enclosure}

The PCB was engraved with a milling machine produced by LPKF Laser \& Electronics AG.
A recycled enclosure was used with custom drilled end caps for the 2.5 mm jacks for the camera connections in one end, and Nucleo board's micro-USB, LEDs and buttons on other end.
For replicating the device identically, a similar box with inside dimensions of at least 127 by 99 mm for the PCB and 35 mm of height can be used.
Of the two buttons, the red one is the user button, and black one is the reset button.
The red LED shows that the power is on, and the yellow LED is on when the focus command has been received.

The completed device is shown in Figure \ref{fig:camsremote-closed}, and Figure \ref{fig:camsremote-full} shows the same with the case opened, exposing the circuit board, soldered parts and the connectors mounted on the end.

%\clearpage

\subsection{Parts list}

\begin{itemize}
	\item ST Microelectronics Nucleo-F401RE microcontroller platform
	\item Mini USB cable
	\item 10 x stereo 2.5 mm jack
	\item 10 x stereo 2.5 mm plug-plug 3 meter cable
	\item 10 x TLP621-2 opto-isolator; interchangeable with any with identical pinout
	\item 20 x 220 ohm resistor
	\item With an enclosure, two LEDs with current limiting resistors and two pushbuttons should be used
\end{itemize}

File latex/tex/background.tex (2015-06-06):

\section{Image acquisition} \label{sec:image-acquisition}

% TODO: image of a scene, a camera with optics and sensor, and a computer, all connected

% in addition too hollsten's number of points, note also the actual accuracy of the model?
This section describes the background theory for basic image acquisition steps in a camera and for main concerns that affect reconstruction quality.
The major steps in an image acquisition pipeline inside a single camera are depicted in Figure \ref{fig:camerapipeline} and are studied in this section at the necessary level of detail for the application.
Quality of the outcome in a reconstruction pipeline depends on many factors of the used stereo imaging rig, such as camera positioning, lens imperfections, lens focusing, sensor noise, image compression, and algorithmic accuracy \cite{hollsten2013imagequality,kyto2011method,rieke2009evaluation}.

% NOTE: not 1.0 to fit paragraphs
\simplegfx{b}{0.95\textwidth}{camerapipeline}{
	Image processing pipeline in a typical modern camera consists of several optical and digital steps with additional post-processing.
	Image from \cite[p.~74]{szeliski10vision}.
}

\subsection{Computer images} \label{sec:computer-images}

In the digital world, with nearly no exceptions, images are stored and represented as \emph{arrays of numbers}, i.e., in discrete form as opposed to the continuous data in the real world.
The way of encoding images as discrete two-dimensional arrays is used throughout this thesis.
A rectangular \emph{raster image} consists of a regular grid of picture elements, or \emph{pixels}.
Each number describes the intensity value for the particular pixel, as depicted in Figure \ref{fig:tinyflowergrid}.
\cite[ch.~2.2]{trucco1998introductory}

Color images are described as several \emph{color channels}: the intensities for different colors are given separately.
The most common model is the \emph{RGB} or \emph{red-green-blue} model, where the primary colors are the same as in human eye; each pixel color is given as a triplet of these three colors.
The intensity range may be arbitrary, but is typically a floating-point value or a small integer with zero indicating black and the maximum value indicating full color intensity.
\cite{pitas2000digital}

\simplegfx{t}{\textwidth}{tinyflowergrid}{
	A small raster color image of a flower, with individual pixels depicted as squares.
	The size of this image is 23 by 34 pixels.
	Each pixel has a specific color shown as a red-green-blue triplet; thus, the image is completely defined by $23 \times 34 \times 3 = 2346$ numbers.
}

\subsection{Imaging} \label{sec:imaging} % {{{

From the perspective of this thesis, images are taken with digital cameras that project a three-dimensional view from a single viewpoint to an image plane and store the resulting data in digital form.
This section describes the process of capturing a still photograph.
A digital camera has the same optical working principles as an analog film camera;
the main differences are in image storage as a discrete image, as opposed to a photosensitive film.

Reconstruction algorithms assume a \emph{pinhole camera} model on the camera optics, and the images must be captured such that the model is accurate.
However, as will be described in this section, cameras in reality seldom match the simplified model thoroughly, and care must be taken when configuring the cameras and post-processing the images later.

% }}} imaging

\subsubsection{Pinhole camera} \label{sec:pinhole} % {{{

%near objects look bigger than distant objects

% What's a pinhole camera, what projection means.

\simplegfx{t}{0.6\textwidth}{pinhole-camera}{
	Pinhole camera principle.
	The box represents a camera.
	Image projected through the small hole is formed to the plane on the back of the box, rotated 180 degrees, as rays of light travel from the subject through the hole.
}

A physical camera is in its simplest form modeled as a \emph{pinhole camera}; an ideal device that \emph{projects} an image on its film through an infinitesimal aperture, rotated 180 degrees around the \emph{optical axis}, i.e., the line that runs through the pinhole and is perpendicular to the image plane \cite{greenleaf1950photographic,kingslake1989history}.
Illustration of the process is given in Figure \ref{fig:pinhole-camera}; for example, light rays from the top right of the subject travel through the pinhole to the bottom left on the film.

The term \emph{projection} means the reduction of three-dimensional objects onto a flat surface, seen from a single view such as the human eye or a camera lens.
The \emph{perspective projection} effect makes objects further away from the observer look smaller in the projected image.
A cube projected on a plane is shown in Figure \ref{fig:perspproj}.

In the scope of this thesis, the only actual camera type considered is one with a \emph{rectilinear lens}, i.e., an optic system that preserves straight lines, as a perspective projection does in a pinhole camera \cite{greenleaf1950photographic}.
More exotic lenses that have a completely different projection are not considered, such as ``fisheye'' lenses, although their projections can be corrected in software.

\simplegfx{t}{0.7\textwidth}{perspproj}{
	Perspective projection: a cube seen from a camera at origin $\vec O$.
	The 3D point $\vec P$ projects on to $\vec p$ on the green plane.
	In a camera, the rays of light travel through a common point to the film that is behind the origin; a virtual projection film between the origin and the object is often used for simplicity.
	Parallel lines in 3D connect in \emph{vanishing points}, two drawn in the left and right.
}

% http://en.wikipedia.org/wiki/Perspective_projection rays of light etc.

% Cartesian coordinates.

Mathematically, a point in a three-dimensional world can be encoded in any coordinate system;
in this work, a standard 3D cartesian coordinate system is used.
In cartesian coordinates, a point is described as a location relative to a selected origin reference, as a triplet of distances along three perpendicular X, Y and Z axes.
In a traditional right-handed system, X increases right, Y upwards and Z towards the viewer.

% }}} pinhole

\subsubsection{Optics} % {{{

In practice, no actual camera works ideally; a pinhole-resembling camera with a tiny hole could be built, but it would have poor light gathering power and low resolution limited by diffraction effects \cite[p.~29]{greenleaf1950photographic}.
Light sensitivity is increased by using a larger hole, and the light rays are directed using carefully manufactured lens systems.
Refraction properties of light rays and manufacturing defects introduce additional distortions that must be taken into account.

Construction of optical systems is well studied \cite{kingslake1989history,greenleaf1950photographic}.
Actual camera ``lenses'' (\emph{camera objectives}) consist of not only a single glass element (optical lens) but many, especially in the case of zoom lenses.
As an example, a mechanically simple fixed focal length Canon lens diagram is shown in Figure \ref{fig:canonef50mm}.
There are several lenses, aligned so that their centers lie on the the optical axis parallel to it.
Most objectives can be reduced to a \emph{thin lens} model (depicted in Figure \ref{fig:thinlens}), an ideal optical model of a single infinitesimally thin glass element \cite[p.~21]{greenleaf1950photographic} \cite[p.~61]{szeliski10vision}.

\simplefig{t}{%
%

}{fig:canonef50mm}{
	A fixed focal length Canon EF 50mm f/1.8 II camera objective.
	Left: the device, not attached to a camera.
	Right: block diagram of the lens construction, showing the six optical elements.
	Diagram by Canon Camera Museum \cite{canonmuseum50mm}.
}

\simplefig{t}{}{fig:thinlens}{
	thin lens sample: $a=6$, $b=3$, $f=2$.
	Actual subjects would be usually much further away; image depicts a macro setup for clarity.
	A subject at a distance $a$ is \emph{focused} on a film at a distance $b$ on the other side, as light rays (red) travel via the lens.
}

\paragraph{Focusing}
A point on a subject is said to be \emph{in focus} when the light rays originating from it converge at the same point on the camera's film.
When the camera objective is adjusted for the object to be in focus, its parameters are changed slightly and a different thin lens is formed.
\emph{Focal length} is a fundamental property of a lens and determines its amount of magnification \cite[p.~61]{szeliski10vision} \cite[p.~13]{greenleaf1950photographic}.
Illustrated in Figure \ref{fig:thinlens}, the thin lens model and its focal length $f$ encode a relation between an object at a distance $a$ and its \emph{focused} image at a distance $b$ on the other side, as shown in Equation \ref{eq:thinlens}.
A camera system typically has a \emph{magnification} of much less than one, i.e., the image on its film is rendered smaller than the imaged subject, as $a \gg b$.
For objects at distances approaching infinity ($a = \infty$), $b$ becomes equal to $f$, and the thin lens resembles a pinhole with film distance $f$.
\begin{equation} \label{eq:thinlens}
	\frac{1}{a} + \frac{1}{b} = \frac{1}{f}
\end{equation}

% Aperture, its effects (light, dof...)

\paragraph{Aperture}
The size of the hole where light effectively goes through is called \emph{aperture}; the hole itself is called \emph{aperture stop} and it is located inside the the objective in between its lenses.
The diameter of a thin lens corresponds to the aperture diameter and to the stop's \emph{entrance pupil}, the aperture stop seen from the front of the objective.
Size of the aperture also directly determines the amount of light entering the image plane, and thus the relative exposure time for a required amount of light energy: doubling the aperture area halves the required exposure time.
\cite[ch.~13]{greenleaf1950photographic}

% TODO: dof graph: varying distance, N lines for different f/#
As in any practical case, the aperture is not infinitesimally small, and there will be some area of the scene that is imaged as sharp and others in front and behind of this area will be blurred.
This effect is called \emph{depth of field (DOF)} and is illustrated in Figure \ref{fig:irldof}.
In artistic photos, a \emph{shallow} depth of field can be preferred, having the subject in focus to separate it from the background by blurring.
In 3D reconstruction, exactly the opposite is preferred: deep focus, i.e., objects at every depth from the camera should be sharp.
The aperture size is presented as relative to the focal length and is commonly called the \emph{F number, $N$} \cite[p.~23]{greenleaf1950photographic}, specified via the aperture diameter $d$:
\begin{equation} \label{eq:fnumber}
	N = \frac{f}{d}
\end{equation}

\simplefig{t}{%


}{fig:irldof}{
	Deep and shallow depth of field in close-up photography using a 50 mm lens.
	Left: f/16 aperture, 15 second exposure, showing only slight blur in the nearest keys.
	Right: f/1.8, 0.2 s exposure, with only a small sharp area.
	The image blurs and the distinctively brighter small lamps on the keys show as increasingly larger bright spots as the circle of confusion increases.
}
Clearly, doubling the area of the aperture equals to an increase of the diameter $d$ by a factor of $\sqrt 2 \approx 1.4$.
The aperture size is typically denoted literally as $f/N$, such as $f/1$ or $f/1.4$.
This makes the light energy reaching the film universal among all focal lengths.
Full multiples of $\sqrt 2$ are called \emph{stops}, and the perceived f number changes as a function of subject distance \cite[p.~23]{greenleaf1950photographic}, which is left out here for simplicity.

\paragraph{Circle of confusion}
As the blur happens gradually, the ``level of sharpness'' at each point is often defined via a \emph{circle of confusion} (CoC) \cite[p.~25]{greenleaf1950photographic}.
The distance from the lens along the optical axis where perfect focus is attained is called the \emph{focal plane}.
Every point nearer or further away shows up on the film as a circle (for circular apertures), instead of a point; when this circle is significantly larger than the resolving power of the observer, the image of this point is perceived as blurred as the image is the integral of all of these circles.

Depth of field is defined as difference between the shortest and farthest object distances that still generate an acceptable CoC, found geometrically.
When $f$ is the focal length, $N$ the aperture f number, $s$ the distance to the subject, and $c$ the maximum acceptable CoC, the depth of field $D$ is (Greenleaf \cite[p.~25]{greenleaf1950photographic}):
\begin{equation} \label{eq:dof}
	D = \frac{2 s f^2 N c (s - f)} {f^4 - N^2 c^2 (s - f)^2}
\end{equation}

\simplegfx{t}{\textwidth}{dofcoc}{
	Depth of field and circle of confusion with a thin lens, seen from the side (not drawn to scale).
	Subjects at distance $s$ project perfectly at the film.
	Distances between $Z$ and $Z'$ project to a circle smaller or equal to $c$.
	It is easily seen that for subjects at longer distances, the depth of field increases.
}

In Figure \ref{fig:dofcoc} that depicts the formation of the circle of confusion, $Z'$ and $Z$ are the maximum and minimum acceptable distances near the subject, and $Z' - Z = D$.
Sufficient depth of field is important in near-field 3D scans, which translates to a small aperture, and consequently, relatively bright lights in order to maintain a short exposure time.
The subject should fill whole image frame to use the pixel density effectively.
Increasing the distance to the subject would increase depth of field, but enlarging the subject in the frame again would need a higher focal length, which decreases depth of field.

Acceptable size of the CoC depends on the resolving power of the viewer; when a photograph is looked at, the print size and distance of the viewer determines the circle \cite[p.~26]{greenleaf1950photographic}.
A standard-considered formula in photography determines the maximum acceptable CoC by dividing the image size by 1500, originating from human vision performance \cite[p.~88,~92]{kingslake1992optics}.
As an example, for the standard ``full-frame'' 35 mm film size with an image size of 36 x 24 mm (approx.\ 43 mm diagonal), the CoC yields $c = 43 \text{ mm} / 1500 \approx 0.03 \text{ mm}$.
For a normal 50 mm lens with the subject at a distance of 1 m, a small aperture of f/11 and using a circle of confusion of 0.03 mm, Equation \ref{eq:dof} gives depth of field of $D \approx 25 \text{cm}$.

In a computer vision system, this purely perceptual guideline is typically ignored and the circle of confusion is determined by the sensor resolution or pixel size.
The disk should not span too many pixels, so that accurate detail would be resolvable from the digital image.
The pixel size is typically in the order of micrometers, with which a much smaller CoC is required.
The sensor of Canon EOS 1D X, for example, has a pixel size of approximately $7 \times 7$ micrometers \cite{eos1dx} which is considered large.
When properties such as type of the subject texture and the quality of the optical path to the sensor influence the resolving power, the circle of confusion is typically used as a guideline instead of a strict rule.

% diffraction

\paragraph{Diffraction}
The required amount of light is not the only factor that limits the minimum aperture size.
\emph{Diffraction} is an effect which reduces image sharpness with small apertures.
When a light ray diverges on a small aperture due to the wavelike nature of light, the different distances traveled make the rays interfere each other and produce a two-dimensional diffraction pattern, called an \emph{airy disk} \cite[ch.~4]{greenleaf1950photographic}.
The disk blurs the image in a similar fashion as an object that is out of focus, as each light ray produces its own particular disk.
Size of the airy disk is relative to the size of the aperture and the light wavelength.
Thus, the aperture size must be chosen as a compromise between the unwanted effects of DOF and diffraction.
The disk size can be approximated \cite[p.~29]{greenleaf1950photographic} by
\begin{equation} \label{eq:airydisk}
	c = 1.22 \frac{\lambda f}{d} = 1.22 \lambda N
\end{equation}
which, for example, for red light having a wavelength $\lambda$ of 700 nanometers, with an aperture of f/11, results in $\approx$ 0.01 mm (compare to above CoC of 0.03 mm).
Again, this should be compared to the image sensor's pixel size, and already an aperture of f/11 would approach the diffraction limit.

\paragraph{Geometric distortion}
While most rectilinear lenses are close to a perspective projection, practical optical systems introduce some non-linear \emph{radial} and \emph{tangential distortion} that affect the accuracy of the ideal pinhole model as light rays travel through the pieces of glass \cite{brown1966decentering,brown1971close}.
Common distortions are the purely radial so-called \emph{barrel} and \emph{pincushion} distortions, where the lens magnification is a nonlinear function of image ray distance from the center of the lens, caused by the shape of the lenses \cite{brown1966decentering,brown1971close}.
In addition to radial, tangential distortion is less significant, and it is often ignored.
Its cause is small misalignments in separate elements in a single optical system, lenses being offset from each other and not being parallel to the image plane \cite{brown1966decentering,kingslake1989history}.

\simplefig{t}{%



}{fig:distortions}{
	Simulated pincushion (left) and barrel (right) distortions by applying undistortion on an undistorted image (center) using OpenCV.
}

Because stereo vision assumes that the images are free of nonlinearities, i.e., straight lines in the world should remain straight in 2D images after the projective transformation, it is important to correct the geometric distortions beforehand \cite{szeliski10vision}.
The radially symmetric radial error model and correction proposed first by Brown \cite{brown1971close,brown1966decentering} and used directly or with slight alternations in programming libraries, e.g., OpenCV \cite{opencv}, is
\begin{align} \label{eq:radialdist} \begin{split}
	x_{corr} &= x(1 + \kappa_1 r^2 + \kappa_2 r^4 + \kappa_3 r^6)\\
	y_{corr} &= y(1 + \rho_1 r^2 + \kappa_2 r^4 + \kappa_3 r^6).
\end{split} \end{align}
where $x$ and $y$ are the original coordinates in the distorted image on the film or image sensor, $x_{corr}$ and $y_{corr}$ are the corrected ones, $\kappa_1$, $\kappa_2$, $\kappa_3$ are coefficients specific to the radial distortion and $r$ equals to the distance to optical origin, located at $(x_c,~y_c)$:
\begin{equation}
r = \sqrt{(x - x_c)^2 + (y - y_c)^2}
\end{equation}

Trucco and Verri \cite{trucco1998introductory} present only the two first coefficients, and it is not rare to use only the first $\kappa_1$; for lenses with low distortion, this is often enough.
A complete derivation of the model involves detailed trigonometric analysis of thin prism models on lens elements \cite{brown1966decentering,brown1971close}, which results simply in Equation \ref{eq:radialdist}, a simple polynomial.
For tangential-only distortion, the corresponding correction has the following form:
\begin{align} \label{eq:tangdist} \begin{split}
x_{corr} &= x + 2 \rho_1 x y + \rho_2 (r^2 + 2 x^2)\\
y_{corr} &= y + 2 \rho_2 x y + \rho_1 (r^2 + 2 y^2)
\end{split} \end{align}
where $x$, $y$, $x_{corr}$, $y_{corr}$ and $r$ are as in Equation \ref{eq:radialdist} and $\rho_1$ and $\rho_2$ are new coefficients specific to tangential distortion.

The two independent types of distortion are combined by summing them both to the original coordinate, combining Equations \ref{eq:radialdist} and \ref{eq:tangdist}:
\begin{align} \label{eq:bothdist} \begin{split}
	x_{corr} &= x (1 + \kappa_1 r^2 + \kappa_2 r^4 + \kappa_3 r^6) + 2 \rho_1 x y + \rho_2 (r^2 + 2 x^2)\\
	y_{corr} &= y (1 + \kappa_1 r^2 + \kappa_2 r^4 + \kappa_3 r^6) + 2 \rho_2 x y + \rho_1 (r^2 + 2 y^2)
\end{split} \end{align}
The effects of different parameters are depicted in Figure \ref{fig:raddist}.
The image dimensions are usually normalized such that the origin lies at the image center, and the distance $r$ from the center has a maximum value of $1$, making the distortion parameters universal for all image resolutions.
A typical image sensor is not a square but a rectangle, and clips the distortion circle accordingly, such that the maximum coordinates along the different axes are different.

\simplegfx{t}{\textwidth}{raddist}{
		Purely radial distortion correction with different values of two parameters.
	The arrows point from original coordinates $(x, y)$ to corrected ones $(x_{corr}, y_{corr})$.
	From left to right: $\kappa_1 = 0.16$, $\kappa_1 = -0.16$, $\kappa_2 = -0.08$, $\kappa_1 = -0.04, \kappa_2 = -0.04$.
	The different shapes of second and fourth order polynomials are easily visible: the higher-order terms are visible have most effect in the farthest sides of the image.
	The leftmost correction is for a barrel distortion, and the others are for pincushion distortion.
}

The Brown's model describes the distortion characteristics for a lens system on an otherwise perfect image, but typically the inverse transform is required, because a distorted image is given as noted by e.g.\ Villiers et~al.~\cite{villiers2008centi}.
For each pixel in the undistorted destination image, the pixel value is necessary to find from the distorted source, but the mapping described by the model works to the other way.
However, Villiers et~al.\ note that as plain barrel and pincushion distortion can be considered as inverse transforms to each other, the same model can actually be used for the inverse direction if the more complex tangential part is left out \cite{villiers2008centi}.

Because digital images consist of a discrete pixel array, the pixel coordinates given by the undistortion do not necessarily lie on exact pixel positions; the sampling should then interpolate between neighboring pixels, considering the image as a continuous but discretely sampled 2D function \cite{wolberg1990digital}.
Throughout this thesis, interpolation is assumed to be performed as necessary when sampling an image.

%Normal TV is usually watched at the distance of twice the screen diagonal.
%At this location, the scene looks normal when taken with a normal lens.
%A wide-angle scene then looks normal when viewed at a nearer distance. \cite{wilson2004anton}
% 14:01:55 <naavis> Kai sillä yritetään emuloida sitä, että katsojan paikalta se leffan kuvakenttä vastais sitä että valkokankaan tilalla on ikkuna.

% }}} optics

\subsubsection{Shutter} % {{{

% shutter, why needed

A static scene is imaged by exposing the photosensitive film (or digital sensor) to the light passing through the optics for a short time, keeping the camera and subject steady.
A \emph{mechanical shutter} blocks the light before and after the exposure \cite[ch.~13]{greenleaf1950photographic}.
In recent digital image sensors, the sensor itself can be made inactive to light or cleared quickly from the accumulated charge; this is called \emph{electronic shutter} \cite{caspeelectronic,kodakshutter}.

% mechanical stuff

\simplegfx{p}{0.99\textwidth}{focalplaneshutter}{
	Focal plane shutter has two moving curtains to cover the film, opening it momentarily so that each part of the film receives light for the same amount of time.
	From left to right: initially, the film (grey) is blocked.
	Once the first curtain (shown in red) moves away, the film is exposed to light.
	A second curtain (shown in blue) stops the light from entering again.
	The shutter resets by moving back to the initial position.
}

\simplegfx{p}{0.99\textwidth}{focalplanerolling}{
	Rolling shutter effect in a focal plane shutter happens when the exposure time is short relative to the curtain speed.
	The curtains have to move at the same time, exposing only a part of the film at a time.
	Fast subject movement during the exposure leads to artifacts and a rapid flash light would illuminate only a part of the film.
}

\paragraph{Shutter types}
All shutters serve the same purpose: to restrict light from entering the image plane before and after the exposure.
There are several types of constructions for shutters, depending on the application.
Some cheaper compact cameras have a small \emph{diaphragm shutter}, or \emph{leaf shutter} in the lens center near the aperture stop.
A leaf shutter moves quickly away from the light path and back, either as a single opaque piece or as several \emph{leaves}, analogously to the aperture stop whose size can be changed \cite[p.~117]{greenleaf1950photographic}.

A \emph{focal plane shutter} \cite[p.~123]{greenleaf1950photographic}, used in most system cameras, is installed in front of the film plane.
Leaf shutters would be expensive to install in each interchangeable lens, and a focal plane shutter can operate at higher speeds.
Focal plane shutter consists of two curtains that move to the same direction; one moves out of the way of the film to let light pass to it, and another moves to cover it back again when the exposure time has elapsed.
Figure \ref{fig:focalplaneshutter} illustrates the working principle of a planar shutter.
In film cameras, the focal plane shutter was originally two fabric ``curtains'';
today, they are constructed from small, interleaved metal or plastic sheets.

Some cameras have only an \emph{electronic shutter} instead of moving parts.
Electronic image sensors can only be cleared and read out at a restricted rate, and their operation is similar to a focal plane shutter.
\cite{caspeelectronic,kodakshutter}

Video film cameras that capture each frame to a separate part of film used a spinning wheel with a transparent window, called rotary disc shutter \cite{wilson2004anton}.
This rotates at a precise speed synchronized to the frame rate, exposing the film to light for a consistent duration for each frame.
The size of the window constitutes to the amount of light and motion blur.
Video is more discussed in Section \ref{sec:video}.

\paragraph{Artifacts}
If the camera or the imaged subject moves while exposing the frame, the subject gets smeared along the movement on the image, an effect known as \emph{motion blur}.
A related \emph{rolling shutter} effect is produced using a focal plane shutter with very high speeds, where the limit of curtain speed prohibits fully opened shutter.
The closing curtain starts to move before the first has stopped, exposing only a narrow band of the film at a time.
Fast mechanical shutter movement is depicted in Figure \ref{fig:focalplanerolling}.
When an object is moving to the same direction as the narrow shutter slit, i.e., vertically, it appears smeared;
when the movement is horizontal, the subject appears to bend.
An electronic flash light that outputs a very brief pulse of high-intensity light also cannot be used with high focal plane shutter speeds, as it would illuminate only a narrow slit of the sensor.
Electronic shutters also suffer from a similar effect; this is more discussed in Section \ref{sec:sensors}.
Since a leaf shutter opens radially near the aperture stop, it does not have this effect, and it can be used at higher speeds with flash lights.
Leaf shutters suffer from another artifact:
at higher speeds, the longer time spent covering the far sides of the image leads to uneven brightness.
Result of shooting a moving object with rolling shutter is depicted in Figure \ref{fig:rollingeffect}.
A ruler was attached to a rectangular plate, and moved left by hand aligned to a table, with different shutter speed and sensitivity settings.
Skew induced by rolling shutter is visible always, whereas motion blur is reduced with a faster shutter speed.

\simplefig{t}{%



}{fig:rollingeffect}{
	Motion blur and rolling shutter in a ruler, moving left.
	The ruler does not actually skew or tilt physically; it is vertical and rectangular at all times, but appears skewed.
	Left: a stationary ruler.
	Middle: 1/100 s shutter speed. % , ISO 100.
	Right: 1/4000 s shutter speed. %, ISO 6400.
	Camera aperture was set to f/8; the pictures are cropped from 720p video recorded with a Canon EOS 700D.
	(Color filter and low sampling rate artifacts are visible as color errors in the high-contrast lines of the ruler.)
}

% FIXME z left handed?

% other

\paragraph{Lag}
When taking a picture by pressing a button, the camera does not instantly start to expose the image.
Each camera has a specific \emph{shutter lag} that is the time that elapses between when the shutter button is pressed and when the actual exposure starts to happen.
Some sources include in this term also the time for the camera to perform autofocus and measure sensitivity settings which can take a significantly longer and unpredictable time.
Shutter speed has also small variations over time when the camera ages and mechanical parts wear out.

Some difference also exists among same camera model from mechanical variations and software processing.
Shutter lag of consumer devices typically varies between tens to hundreds of milliseconds \cite{hasshutterlag}.
% }}} shutter

\subsubsection{Image sensors} \label{sec:sensors} % {{{

% intro: film vs sensor, what is a camera

Historically, photographs were saved on a photosensitive film.
With digital cameras, a rectangular electrical \emph{sensor} replaces the film.
The sensor consists of a uniformly spaced grid of small sites that convert the visible optical image to electrical signals, built as an integrated circuit package.
In conjunction with the digital signal processing in the camera, the sensor produces a digital image file.

% pixels, colors

As introduced in the beginning of this section, digital images are represented as arrays of colored pixels.
In order to obtain an appropriate image, the sensor must capture the light it sees also as a discrete array.
The separate red, green and blue color bands are captured in color cameras with separate parts of the sensor, as will be explained.

\paragraph{Photosites}
A sensor consists of individual photosensitive semiconductor sites that each accumulate charge and ultimately encode a single numerical value, relative to the amount of light received \cite[ch.~3]{nakamura2005image}.
Physical pixels cover less than the full area of a sensor, as there are gaps between them;
microlenses between the sites direct the light hitting the gaps to the neighboring pixels in modern sensors, with varying color performance \cite[p.~64]{nakamura2005image} \cite{el2005cmos}.
%Because of the discrete nature of the pixel array, some cameras use an analog low-pass filter in front of the sensor to hide high-frequency information that would show up as aliasing.

A single pixel sensor acquires all light hitting it, independent of the wavelength.
The most common method to capture the three primary colors is to interleave red, green and blue colors in a single sensor by filtering the wavelength that can enter each pixel with a colored film over the sensor, with a special repeating pattern called \emph{color filter array}.
The missing values for other colors bands are interpolated from surrounding pixels.
The most popular interleaving pattern is the Bayer filter \cite[p.~76]{szeliski10vision}, illustrated in Figure \ref{fig:bayerpattern}.
Other arrangements than red, green and blue are also used; e.g., red, green, blue and emerald or cyan, yellow, green, and magenta \cite{park2003implementing}.
Alternatives have slightly better color accuracy at the expense of spatial resolution.

\simplefig{t}{\bayer{0.6}}{fig:bayerpattern}{
	A small partly drawn subset of the repeating $2 x 2$ Bayer pattern.
	Each square represents a single pixel; the colored pattern on top filters the light per each pixel on the sensor array.
}

\paragraph{Sensor technologies}
Near the raw pixel sensors is analog and digital logic for converting and reading out the data and passing it to an image processor.
Quality and type of this conversion affects some properties, most important of which are analog-digital converter noise and dynamic range, and speed at which the image is read out from the sensor.

Two major sensor types exist: CCD (Charge-coupled Device) and CMOS (Complementary Metal-Oxide Semiconductor).
The types vary by their manufacturing techniques and photosite internals \cite{nakamura2005image,taylor1998ccd,el2005cmos}.

Both CCD and CMOS have their applications, but it suffices to say that CMOS is the one used in most still cameras because of its lower price and power consumption, and higher speed.
A CMOS sensor converts light immediately to voltage, and has additional transfer circuitry at each pixel, reducing the \emph{fill factor}, the sensitive parts of the photosites \cite[p.~62]{nakamura2005image}.
In a CCD, the charge is first stored as electrons as in a capacitor, and a row is transferred serially from pixel to pixel to a separate voltage converter and amplifier.
Still, both are typically read out ultimately in a serial fashion, requiring longer reading time for larger amounts of pixels.
A CCD typically uses additional photosites permanently blocked from the light for storing the accumulated charge temporarily.
A CMOS sensor, on the other hand, cannot easily employ additional storage pixels, and is read sequentially, making the reading process resemble the rolling shutter effect.
Rolling shutter is especially noticeable in videos shot with a CMOS camera, because a mechanical shutter is not used for video and the readout process is relatively slow \cite{taylor1998ccd,caspeelectronic}.

\paragraph{Error sources}
Various steps of the image processing contribute to image noise; the major sources are shot noise and several electrical noises \cite{szeliski10vision,litwiller2001ccd}.
\emph{Shot noise} exists due to the particle-nature of light; each photon adds a constant electrical charge to the photosite it hits, and if the overall number of photons is small, statistical Poisson-distributed noise will be present \cite[p.~74]{nakamura2005image}.
This type of noise is visible in less bright areas.
Clearly, no electronically better sensor can improve the visibility of shot noise.
The only way to reduce it is by exposing the sensor to more light: for this reason, sensors with a larger surface area are preferred in applications where noise is unwanted.

The Gaussian-distributed \emph{electrical noise} has various sources in sampling, transfer and conversion.
Each pixel receives an additional random signal level that shows up as additive brightness, also noticed usually only in poorly illuminated conditions or dark areas.
Noise increases with sensor's signal gain, or \emph{exposure sensitivity}, described using the ISO system (``film speed'').
Sensor \emph{responsivity} usually refers to the raw signal the photosite sensor produces per unit of optical energy \cite[p.~78]{nakamura2005image}.
The resulting digital value depends on this and many other terms on the signal path.

A more sensitive ISO setting on a sensor requires less light for a bright-looking image, because the signal is amplified more before digitization.
This amplification also amplifies the original signal noise.
Additionally, the reduced exposure time allows the shot noise to be more visible.
Due to these reasons, the gain level should be kept as small as possible and the amount of light entering the sensor as large as possible.
This leads to requiring bright lighting in the imaged scene or a longer exposure time.
Higher ISO should be used only if shorter exposures are desired due to a moving subject.
Better sensors advertised as more responsive to light typically have larger sensors or less noise-sensitive circuitry, resulting in higher signal to noise ratio \cite{el2005cmos}.

Photosites may also accumulate leaking charge on their own even though no light is entering the site because of \emph{dark current} \cite{el2005cmos,litwiller2001ccd}.
Additionally, the analog-digital converter introduces \emph{quantization error} where an analog signal is not perfectly represented by a discrete number; with the high bit depth of modern sensors, this is practically not an issue.
A high bit depth also presents larger \emph{dynamic range}, i.e., the difference between the brightest and darkest possible representations \cite{el2005cmos,litwiller2001ccd}.

% }}} image sensors

\subsubsection{Lighting} \label{sec:bg-lighting} % {{{

In addition to multiple cameras at different locations and poses to encode a subject's geometry, uniform and soft lighting is also required for consistent color reproduction.
A large variety of different studio lights are available in the market for different lighting situations, emitting either continuous light or bright flashes.

\simplegfx{t}{0.7\textwidth}{nayarbrdf}{
	Polar plots of three reflection components as functions of the viewing angle, as suggested by Nayar \cite{nayar1991surface}, showing the brightness seen from different angles from the surface normal.
	In a reconstruction subject, the bright specular spike and lobe reflections should be minimized, and only the diffuse color is desired.
}

\paragraph{Surface color}
The \emph{perceived} color of a point on a surface is the light exiting it and reaching the viewer.
Therefore, the light sources should be uniformly white and cast no shadows.
Surfaces reflecting light can be modeled as a combination of \emph{diffuse} and \emph{specular} components that are functions of light direction, viewing direction and sometimes additionally location on the surface.
Surface reflection models are described with a \emph{bidirectional reflectance distribution function, or BRDF} \cite{nicodemus1965directional}.
Such distribution model of the surface's global or local microgeometry specifies how much light reflects in different directions \cite{nayar1991surface}.
\emph{Diffuse} means a material that reflects light uniformly to all directions, depending only on the angle between the surface normal and light location, whereas more \emph{specular} surfaces are composed of a different microstructure that reflects light in a mirror-like way; the surface brightness depends on where it is looked from.
In Figure \ref{fig:nayarbrdf}, different types of reflections seen by the camera are visualized as a function of the camera viewpoint.

% XXX pic of brightness constancy: same object from two views, patch windows

\paragraph{Color capture}
Ideally, the camera would only record the diffuse reflection that represents the surface color (\emph{albedo});
any shadows and the specular components are unwanted artifacts from the standpoint of simple color reconstruction.
\emph{Specular highlight} or \emph{specular reflection} refer to a mirror reflection of the lamp on the imaged surface.
Because most reconstruction methods fundamentally assume uniform lighting conditions, a property called \emph{brightness constancy} (i.e., the brightness and color of a surface looks the same, regardless of viewing direction or time moment), they perform poorly when a light shines off a surface differently in different views \cite[ch.~8.3]{trucco1998introductory}.
As images describe the color via the brightness that reflects off of a surface, the perceived brightness must be held constant.
The same restriction provides a basis to other algorithms, such as object tracking \cite{horn1974determining,horn1981determining}.
Examples of complex surfaces containing much specularity are glossy textures and sweaty human skin.

On the contrary, in photographs and image synthesis, shadows and reflections are natural, and images without them would look odd to the eye; capturing only albedo of surfaces -- the color reflectivity of a surface -- is particular to texture capture in reconstruction.
In practice, polarizing filters may be used in front of the lights and in the camera lenses, to filter out most of the specular lighting.
Advanced capture and rendering methods may take advantage of also the specular component \cite{ghosh2011multiview}; however, capturing material properties is easily done separately from the geometry capture \cite{aittala2013practical}.

\paragraph{Light sources}
As the surface should be illuminated as evenly as possible to minimize specular highlights and shadows, it is important to pay attention to light sources.
The often used photography terms \emph{soft} and \emph{hard lighting} refer to the size and power of light sources: bright spotlights are hard, and larger and relatively less bright lamps are soft.
Softness can be added by increasing the light's area while holding its power constant using a ``diffuser'', such as a large surface where light is reflected off or a white cloth between the lamp and the imaged subject.
\cite[p.~108]{langford2000basic}
% TODO Effects of a soft versus hard light are illustrated in Figure \ref{fig:lighthardness}.

Powerful electronic flash units use usually a gas-filled tube that is excited with high voltage to produce a short, bright burst of light for some milliseconds;
since this tube is small, a diffuser should be used for uniform lighting.
Flashes are especially suitable for human subjects, because the subject sees the bright light only for a brief moment; thus, the light does not annoy the subject as continously bright lamps would.
Short bursts of light in an otherwise dark environment are also suitable for stopping motion and synchronizing multiple cameras, as only a short time is effectively exposed to light \cite{langford2000basic}.

% }}} light sources

\subsubsection{Data capture path} % {{{

The image information travels from the subject through the optics to the image sensor's surface, via an analog/digital converter, the camera's processor(s) and finally to mass storage \cite{szeliski10vision}.
The final mass storage is typically on the camera in consumer devices, or on a computer reached by a wired connection for more sophisticated machine vision cameras \cite{hornberg2007handbook,ni2013choosing}.
Many parts in this path contribute to the quality of images and the rate at which the images can be taken, usually measured in frames per second (FPS).

% fps, performance sample

For example, for the high-end Canon DSLR camera EOS-1D X, a continuous shooting speed of 14 frames per second is advertised \cite{eos1dx}.
With its resolution of 5184 by 3456 pixels and 14-bit processing, an estimate for the bit rate from the sensor is
\begin{equation} \label{eq:eos1dspeed}
5184 \times 3456 \times 14 \times 14 \approx 3.5\text{ Gb/s}
\end{equation}
by average, or 0.4 gigabytes per second, requiring also high speed from the processor and mass storage.
Due to the cost of transferring and processing large amount of data, video is typically recorded in lower resolution for faster FPS.

% files

A ``raw'' image file can be saved with more advanced cameras, containing the plain sensor data with very little processing done.
The raw files saved by DSLR cameras are packed in a proprietary lossless format and contain also metadata about certain camera settings.
When a raw file is not used, the camera processes the image with device-specific correction filters and applies image enhancements, e.g., white balance correction and sharpening, and finally saves the image as a standard image file such as JPEG \cite[p.~412]{szeliski10vision}.
For such automatic in-camera processing, all cameras should be identical for consistent reconstruction results.

%Lossless compression maintains image quality and reduces file size depending on the complexity of the frame.
%Some manufacturers encode the brightness values through a lookup table, and it's common to use a compression scheme known from standard file compressions, or a specific lossless image compression.

Video files are almost always saved in a lossy video format by consumer devices, the H.264 format being common for modern cameras.
Compression introduces loss of detail and artifacts typical to the particular algorithm, often visible as blocks or blurring \cite{richardson2004h264}.
Reconstruction quality from frames extracted from such a compressed video may not be as high as from separately saved stills that encode more spatial information.
Machine vision cameras and some professional video cameras can record raw uncompressed video, and some others can be unofficially enhanced;
Canon DSLRs can be tricked using a third-party software modification \cite{magiclantern} to capture the raw stream to a mass storage card, but only some models support the cards necessary for the high recording speed.

% }}} image download

\subsection{Video} \label{sec:video} % {{{

% NOTE ALL-I (intra) / IPB (intra-predict-bidirpredict)

% intro, connection to reconstruction

\emph{Video} is ordered electronic pictures displayed one after another.
Humans perceive \emph{motion} when a previously seen object is seen again in a nearby location.
Current digital video technology encodes motion pictures as in films, in a sequence of still images, recorded and displayed at a constant rate.
Three-dimensional motion is generally no different: it is encoded as discrete poses in sequence.
In order to do motion capture in stereo vision, video material from two or more of cameras is used to initially capture a sequence of still photos.

To reconstruct the frames in 3D, each set of frames encoded by the cameras should be \emph{synchronized}, i.e., shot at the same time, to fulfill the reconstruction assumption of a static subject.

% }}}

\subsubsection{Sequence of frames} % {{{ or: video is frames

% how/when frames are captured
When scanning a scene continuously, a camera shoots frames using the same principles as in photos, but does it in sequence, at a speed that is called \emph{frame rate} \cite{poynton1996technical}.
For each frame, the shutter is open for a duration of \emph{exposure time} or interchangeably \emph{shutter speed}.
In \emph{interlaced video}, two frames make up a whole picture that covers all pixels.
Interlacing alternates between odd and even lines to increase update rate, and was invented for cathode ray tube displays to reduce apparent flicker \cite{poynton1996technical}.
The alternation results in tearing artifacts when imaging horizontally moving subjects (shown in Figure \ref{fig:interlace}).
Many CCD video cameras still produce interlaced stream.
Video that contains full frames only is called \emph{progressive}.

\simplegfx{t}{0.7\textwidth}{interlace}{
	A cropped area of interlaced scanning.
	From left to right: even lines only, odd lines only and full picture combined.
	Top: stationary square.
	Bottom: a moving square, showing tearing if the frames would be combined.
}

% on fps

Consumer video cameras, video-capable pocket cameras and DSLRs typically offer a few choices of frame rate.
Traditionally, the movie industry has used 24 FPS; 25 and 30 are common alternatives used in TV broadcast, some cameras being capable to twice the speed at a lower resolution.
Actual FPS is slowed down from the advertised by a factor of 1.001 because of historical reasons.
30 and 24 FPS refer to approximately 29.970 and 23.976 FPS, respectively.
\cite{musburger2010single}

Externally triggered cameras can clearly be configured to record at any arbitrary rate and exposure, as long as it is in the limits of the camera speed capabilities.
Synchronized machine vision cameras do not record video on their own, but instead monitor a clock signal and output frames at the clock rate.
The frames are then recoded to a computer using \emph{frame grabbers} for interfacing with the cameras.
\cite{hornberg2007handbook}

% dslr sucks

DSLR video modes use almost the sensor's full size but skip some of its lines when recording video, resulting in the same field of view as still images but suffering from significant aliasing patterns with certain subjects with high frequency information.
An alternative would be to crop a smaller part of the sensor for the frames.
Additionally, pixels in the video frames do not represent physical pixels anymore, posing awkwardness in camera calibration.
Line skipping is depicted in Figure \ref{fig:lineskipping2}.
The color filter array makes the problem even worse for small-detailed features of high color detail.

\simplegfx{t}{\textwidth}{lineskipping2}{
	Line skipping in a DSLR camera in video mode.
	Left shows a part of the full sensor and its bayer pattern; on the right, only every third line is captured.
}

% }}}

\subsubsection{Frame rate and shutter speed} % {{{

% no particular reason to be inline instead of pdf, just legacy
\simplefig{t}{
\begin{tikzpicture}[scale=1.5]
	\def\nframes{5}
	\def\w{1.5}
	\draw (0,0) rectangle ++(\nframes*\w+\w,-1.5);
	\draw (0,-0.5) -- ++(\nframes*\w+\w,0);
	\draw (0,-1) -- ++(\nframes*\w+\w,0);
	\foreach \x in {0,...,\nframes} {
		% time ticks
		\node at (\x*1.5, -1.7) {{\x}t};

		% exposure blocks
		\draw [fill=red] (\x*\w, 0) rectangle ++(1.0*\w, -0.5);
		\draw [fill=red] (\x*\w, -0.5) rectangle ++(0.5*\w, -0.5);
		\draw [fill=red] (\x*\w, -1) rectangle ++(0.25*\w, -0.5);
	}
	\node at (-0.3, -0.25) {1/1};
	\node at (-0.3, -0.75) {1/2};
	\node at (-0.3, -1.25) {1/4};
\end{tikzpicture}
}{fig:shutterspeed}{
	Varying shutter speed compared to constant frame rate $1 / t$.
	Red rectangles illustrate exposure time, i.e., open shutter.
	For an always open shutter, the sensor would record continuously.
	A ratio of 1/2 is a ``normal'' rate most used in film.
	1/4 would result in slightly less motion blur and less captured light intensity.
}

A higher frame rate results in more accurate representation of motion as a whole, and a faster shutter speed helps to reduce motion blur in individual frames.
For reconstruction, ideal exposure time would be infinitesimally short; practically, the amount of available light restricts the time, even though a camera would be faster.
Similarly, what happens when the shutter is closed is not recorded; ideal frame rate would be faster than any period of motion in the scene.
For motion tracking based on frame differences, a long enough time should be passed for reliable motion direction detection, though.
%Normally, if playback happens at a different rate from the recording, motion is interpolated between different frames or the last appeared frame is used.

In contrast, in motion picture industry the shutter is kept open deliberately so long that fast motion is blurred, because it is considered aesthetically pleasing to human eye \cite{wilson2004anton};
even though the motion is blurred, it appears less jerky and more temporal information about the scene movement is encoded per frame than when exposing infinitesimally short frames, at the expense of spatial resolution.
A typical shutter speed relates to frame rate such that a frame is exposed half of the time between frames \cite{wilson2004anton}.
%Good cameras allow to change the frame rate and shutter speed independently.

Film cameras and some professional video cameras use a rotary disc shutter that has an opaque 180 degree sector.
Having half the exposure time of frame rate is sometimes called ``180 degree shutter'' due to this historical reason \cite[p.~37]{wilson2004anton}.
While the light is blocked, film is mechanically advanced to the next frame.
Digital video analogously downloads data from the image sensor and clears it during this time.

% }}}

\subsubsection{Multi-camera synchronization} % {{{

%Time offset / drift / jitter / lockstep

Concurrent recording of multiple view video is more complicated than shooting still photos simultaneously.
The cameras should be synchronized together to hold their shutters open at the same time during each frame.
An assumption of stereo vision is that the images encode a static scene, i.e., geometrically same objects, which would not hold otherwise.
Lack of proper synchronization can be compensated to some degree with stroboscopic lighting or morphing between recorded frames if hard syncing is not possible \cite{bradley2009synchronization}.

Within the scope of this thesis, synchronization issues can be divided roughly in three sources of error, assuming N cameras each having its own video file with same frame rate: \emph{offset}, \emph{drift} and \emph{jitter}.
With the same frame rate, the frames can be indexed with numbers starting from 0.
Times when the frames taken relative to a global clock is noted as $t_{Ci}$, where $C$ is a camera identifier and $i$ is the increasing frame index.

\emph{Offset} is the time difference of two streams: for an ideal camera $A$ at each frame $t_{Ai}$ for $i$, and an offset camera $B$ at $t_{Bi}$, a constant error $e$ is added:
\begin{equation} \label{eq:timeoffset}
	t_{Bi} = t_{Ai} + e
\end{equation}

Drift is a property of one a camera that advertises to record at some speed and actually works at some other speed.
Similarly for cameras $A$ and $B$, a constant $d$ is added for each frame index $i$:
\begin{equation} \label{eq:timedrift}
	t_{Bi} = t_{Ai} + d i
\end{equation}

Jitter is the random offset $j(i)$ between frames of an ideal camera A and a camera B:
\begin{equation} \label{eq:timejitter}
	t_{Bi} = t_{Ai} + j(i)
\end{equation}

For an actual video camera, drift and jitter are negligible; offset originates from starting the recording at a different time and from camera's internal processing before the recording actually starts.
If the cameras take pictures only when instructed, such as machine vision cameras, a common clock generator becomes another source of error.
Many consumer cameras support a live preview feed when connected to a computer; the feeds can be useful for previewing but jitter would be too significant.
If the offset between two cameras is not an exact multiple of the frame speed, they effectively cannot have any frames that would display exactly the same scene.

Frame accurate offset sync with clapperboards works by matching the clap sound to visual cues in the video, a method well known in film production.
Cameras that record audio to the same video file do not need visual cues and can be synced together by matching the sound streams.
%This is the method used in making movies when editing a final version with multiple cameras used.
Unsynchronized shooting still leaves an offset of at most half a frame between the camera sequences; this most significant sync issue is illustrated in Figure \ref{fig:syncproblems}.

Professional video cameras can be synced to a single clock generator, so that they all operate on the same frequency (i.e., no drift) and phase (i.e., no offset), called \emph{genlocking} or \emph{generator locking}.
Similar method is used when shooting with machine vision cameras that have external trigger input \cite{poynton1996technical}.
Synchronizable camcorders are expensive, and consumer-grade hardware usually lacks all possibilities for proper sync.

\simplefig{t}{
\begin{tikzpicture}[scale=1.5]
	\def\w{1.5}
	\draw (0,0) rectangle ++(5*\w+\w,-0.5);
	\draw (0,-0.5) rectangle ++(5*\w+\w,-0.5);
	\foreach \x in {0,...,5} {
		\draw (\x*\w, 0) -- (\x*\w, -1.5);
		\node at (\x*\w, -1.6) {${\x}t$};

		\draw [fill=red] (\x*\w, 0) rectangle ++(0.4, -0.5);
		\draw [fill=green] (\x*\w+0.3, -0.5) rectangle ++(0.4, -0.5);
	}
	\draw (0.3, 0) -- (0.3, -1.5);
	\node at (0.3, -1.6) {$e$};
	\node at (-0.3, -0.25) {$A$};
	\node at (-0.3, -0.75) {$B$};
	% P, Z
\end{tikzpicture}
}{fig:syncproblems}
{Video phase difference, i.e., offset, illustrated as a timeline.
Red rectangles illustrate exposure times of camera $A$, green rectangles the same for camera $B$.
Frame period is $t$, and the cameras have a constant exposure time offset of an arbitrary $e$.}

% }}}

\subsection{Digital camera types} \label{sec:cameratypes} % {{{

% intro on camera types, wanted options left in implementation

This section quickly reviews the most common types of digital cameras available.
More in-depth survey on properties important in reconstruction are given in Section \ref{sec:cameracomparison}.
%
% camera types introduced

\paragraph{Camera category overview}
\emph{Consumer cameras} have good availability, but they are targeted for artistic photography and basic users.
They are divided roughly in two categories: \emph{compact (pocket, or point-and-shoot) cameras} and \emph{system cameras}.
The presence of a mirror divides system cameras in two: \emph{digital single-lens reflex cameras (DSLR)} and \emph{mirrorless interchangeable-lens cameras (MILC)}.
A MILC lacks a separate viewfinder and the reflex mirror, resulting in smaller size.
System cameras typically support an interchangeable lens and a number of auxiliary hardware, such as electronic flash units, remote shutter releases and power adapters to replace batteries.

\emph{Industrial cameras} for \emph{machine vision}, targeted for engineering applications with high repeatability, are more controllable and contain no unnecessary bulky parts, but are more expensive and inconvenient to set up, and may need proprietary control tools.
Their product cycle is typically longer and thus more reliable than in consumer electronics.
In industrial cameras, the different parts of the system are typically defined more accurately in terms of, e.g., lens quality, sensor and pixel size, sensor noise, processing speed and communication protocol.

\emph{Camcorders}, video cameras with recording capabilities, also vary from consumer to professional grade devices.
Camcorders are not quite considered in this work because of their lower resolution relative to still cameras; many of their benefits lie in user interfaces designed for different purposes in video.
Many still cameras support acceptable video recording.

% some properties

\paragraph{Pixels}
Camera sensor resolution is declared in millions of pixels, or megapixels (MP).
Sensor resolution and image size are related via \emph{pixel size} that is the physical size of one photosite on the sensor.
Pixel size is described as the physical length of one side of a photosite; virtually all sensors today employ square pixels.
System cameras have largest sensors and pixels, and pixel size typically decreases as the sensor size decreases, as manufacturers pursue for high resolution despite of sensor size.
The physical size of the image sensor varies according to use, and ultimately determines resolution, pixel size and light sensitivity.
Currently, typical sensor sizes for different camera categories are as follows:

\begin{itemize}
	\item System cameras use a ``full-frame'' (36 x 24 mm) or APS-C (1.5-1.6x crop of full frame: 22 x 15 mm), resolution usually over 15 MP with pixel size at about 5 micrometres
	\item Compact cameras use a small sensor; sizes vary but are approximately 1/2.3 inch (6.2 x 4.6 mm), resolution about 10 MP or more
	\item Smartphones use sizes between 1/3-1/4 inch (less than 4.8 x 3.6 mm), resolution between 3 to 8 MP
	\item Sizes used by industrial machine vision cameras vary by application, in 5 to 10 mm range having resolutions from 0.5 to over 10 MP.
\end{itemize}

%sensor vibration to remove dust -> sensor position not very fixed \cite{rieke2009}.
%no image stabilizer in sensor or lens \cite{photogrammetry.doc}
%ring flash bending the lens assembly if attached to it \cite{rieke2009}.

% lenses, shutters

\paragraph{Lens quality}
To benefit from the sensor resolution, the camera objective should have an equivalent or better \emph{resolving power}, provided as a chart of \emph{modulation transfer function} (MTF), which is a function of frequency, or number of black-and-white \emph{line pairs} per millimetre.
A lens attenuates the frequencies of the optical patterns, such that at some point, dense line pairs are not resolved from each other but show up as gray.
\cite[p.~71]{kingslake1992optics}

Machine vision cameras and system cameras use interchangeable lenses with often well specified MTFs provided by the manufacturer, while cheaper compact cameras, phones and webcams are designed for a single lens that cannot be removed and has poorer MTF that usually is not provided \cite{sick2006machine}.
Compacts also accompany a \emph{zoom lens} for versatility; zooms are more complex systems and therefore more expensive to reach an image quality comparable to others.
Calibration is also an issue with moving zoom elements that may not align to precisely the same setting.
Interchangeable lenses have a large selection of fixed focal length (``prime'') lenses with less moving parts and typically better optical quality.
The lack of zoom of a prime lens is acceptable in a controlled environment, where the distance to the subject can be adjusted as necessary.
With DSLRs that have a moving mirror and a shutter, the mechanical vibration could move the zoom lens each time a little, changing the focal length.
%Rieke-Zapp et~al.\ \cite{rieke2009evaluation} address several problems in camera calibration and imaging quality.

% storage

\paragraph{Data storage}
Storage size and speed and camera processing power in general follows camera price.
High-quality motion capture of short performances is aided by continuous burst mode that can achieve anything between 2 and over 10 frames per second, depending on camera model.
Professional-level DSLRs and many MILCs can handle over 10 continuous raw full frames per second, while entry-level DSLRs handle around five;
compact cameras are generally slower.
Machine vision cameras with resolutions comparable to DSLRs also exist, but at a significantly higher price.
Overall storage speed is determined by several factors between the sensor, the camera's processor and mass storage.
Reading the pictures to a computer can be done via USB bus or a memory card reader; the latter method is not practical, since the card must be removed from each camera and placed to a reader manually.
Industrial cameras typically have temporary memory for only one frame that is read out immediately via a bus or transfer the read frame from the sensor directly with no buffering.
For video recording, this needs relatively large amounts of auxiliary hardware to save the raw frame feed.
Additionally, either fast hard disks or large amounts of RAM for live data storage would be required.

% software support

\paragraph{Software support}
For a number of cameras requiring identical parameters and control, setting the parameters and downloading pictures manually is not acceptable.
Major consumer manufacturers provide a software development kit (SDK) for controlling their cameras remotely to some degree, and some support a common standard for file access.
For machine vision cameras, manufacturers provide their own software packages, in addition to sometimes specifying that the camera complies to a standard.
The standards specify data formats and buses, image streaming, and control methods.
Key standards \cite{hornberg2007handbook,ni2013choosing} for industrial cameras are:

\begin{itemize}
	\item Camera Link, partly proprietary serial transfer protocol with special cable and connector types
	\item GigE vision, standard interface for video data over gigabit Ethernet connection; licensed so that writing open source software directly based on the standard is not officially possible
	\item IIDC/DCAM, Instrumentation \& Industrial Digital Camera or 1394-based Digital Camera Specification, data format standard used in IEEE 1394 (Fire-Wire) cameras; an open specification
	\item USB3 Vision, a computer vision standard for the USB 3 bus
\end{itemize}

A standard-compliant industrial camera enables to use readily available software, reducing the need for in-house software and protecting from vendor lock-in.
Some of the largest manufacturers that offer standards-compliant cameras are Point Grey, Basler, Allied Vision, and Imaging Source.

% http://www.edmundoptics.com/imaging/cameras/
% store http://machinevisionstore.com/Catalog/ByCategory?category=1&group=1
% http://www.dpreview.com/products/search/cameras

%Coriander \cite{coriander} is a free user interface for controlling IIDC cameras.

% triggering
\paragraph{Remote trigger}
For a multi-camera setup, reliable remote trigger is important.
It must be possible to signal the shutter release remotely for still pictures and video recording.
Industrial cameras are designed to be remotely controllable, and system cameras have input sockets for remote trigger signals.
Others have limited offer, mainly supporting infrared remote if anything.

% camera comparison

\paragraph{Conclusion}
Summarizing for the general feasibility of the most popular camera types in the market:

\begin{itemize}
	\item System cameras with bigger sensors have high light responsivity, excellent configurability with auxiliary hardware available, such as flash units and remote shutter releases, and decent software support.
	\item Industrial machine vision cameras have both small and medium sensors, support interchangeable lenses and need significant amount of additional signal processing hardware, and custom or expensive software to control.
		Video synchronization is usually not an issue, and parameter control has more freedom at the expense of more work.
	\item Compact cameras, designed for the general public for all-purpose point-and-shooting are cheap, have non-changeable zoom lenses and are in general slower.
		Raw images and external utilities are usually lacking.
		Sensor resolution may be less than in system cameras, and high-resolution compact cameras perform worse in low light because of smaller pixel size.
	\item Others (smartphone cameras, webcams) have poorly documented features, cheaper optics and are not configurable properly in general.
\end{itemize}

% }}} camera selection

\clearpage
\section{Static 3D reconstruction} \label{sec:static3d} % {{{

Multi-view stereo reconstruction is one way to recover the structure of a static three-dimensional scene.
In this thesis, a multi-view setup with ordinary digital photo cameras is assumed;
fundamentally different methods, such as laser rangers or light field imaging, are not considered.

A complete reconstruction pipeline consists of many parts of hardware and software.
This section concentrates on the steps of the software pipeline, which is illustrated in Figure \ref{fig:reconstpipeline}.
The subject is broad and this section aims to only describe the main ideas in a nutshell.
For detailed descriptions and analysis, refer to textbooks, e.g., \cite{hartley03multiview,heyden2005multiple,szeliski10vision}.

Images taken with digital cameras are first scanned for distinct features and matched.
To uniquely detect the 3D position of a point in a scene, its image location is required in multiple views.
Initially, matching points are required also for calibrating the structure of the scene and the cameras.
Then, optical distortions are corrected.
The correction requires matching points of different views, and as the feature scan can be performed on original, distorted images, this step often follows the first or is done simultaneously.
Distortion correction can also be done as the first step if the distortion parameters are measured separately; this is not always the case for instant reconstruction.

Using the matched features, the cameras are calibrated together, resulting in information about how each camera views the scene, and how the cameras are positioned.
This calibration is required for mapping the image points uniquely back to 3D.
Once the coarse structure of the matched points and the camera system is acquired, it is further refined for best accuracy.
Using the obtained camera parameters, a dense reconstruction of subject geometry is calculated, which is often the most time-consuming calculation and the biggest goal of reconstruction.
The camera parameters are jointly used to map each pixel seen by the cameras to the 3D scene.
Finally, a surface is fitted on the resulting dense point set, and color images are projected on the surface.
A surface is more natural than the point-based output of the dense reconstruction, as the points are only a discontinuous model of the scene.

\simplegfx{b}{\textwidth}{reconstpipeline}{
	Typical steps in a full structure-from-motion type reconstruction pipeline with no prior calibration information.
}
%[1] Shape and motion from image streams under orthography: A factorization approach
%- every Nth frame free of patterns for texture extraction (zhang snavely curless 2004)
% project noise for geometry if low-featured texture, grab texture/color separately with flashes

% }}}

\subsection{Coordinate systems and transforms} \label{sec:coord} % {{{

% intro, now using pinhole

The previous image acquisition section described how to record a view of a scene with a camera.
From now on, \emph{camera} refers to a particular \emph{configuration} for the camera, or \emph{view}, which can even be a single physical camera moved to different locations.
The camera is reduced to the pinhole model; distortions caused by the optical system are assumed to be corrected.

% what is a camera now, parameters

The camera is a projective object located somewhere in the imaged scene.
Its \emph{intrinsic parameters} model the properties of the projection, but do not take into account the camera location in any global coordinate frame.
The \emph{extrinsic parameters} contain the camera location and rotation in another global coordinate frame, often structured as a matrix \cite[p.~41]{hartley03multiview}.
This section reviews basic transforms whose results are needed in the later reconstruction steps.

\simplefig{t}{%

}{fig:pinhole3d}{
	Pinhole camera geometry.
	Camera coordinate system origin and the physical pinhole at $O$, axis Z is parallel to the optical axis, U and V specify the image plane axes and the optical axis intersects the image plane at the principal point, the image center.
	The point $P = (P_x, P_y, P_z)$ projects to $p$, as well as everything else on the line joining them.
	The image plane is f units away from camera origin.
}

\paragraph{Projection}
Light rays travel through the pinhole camera's aperture to the image plane that is $f$ units behind the aperture, while the camera origin is set to the aperture \cite{hartley03multiview}.
This configuration is depicted in Figure \ref{fig:pinhole3d}.
The pinhole model (or, \emph{perspective projection}) states that the world point $(P_x, P_y, P_z)$ is projected via direct light rays to the 2D image plane at $(p_u, p_v)$:
\begin{equation}
\begin{pmatrix}
p_u \\ p_v
\end{pmatrix}
=
-\frac{f}{P_z} \begin{pmatrix}
P_x \\ P_y
\end{pmatrix}
\end{equation}
The result can be derived from similar triangles with a common vertex at the aperture.
Sometimes the sign is inverted, which results in a plane on the other side of the origin where the actual point lies, where the image is not rotated; this can be more convenient to analyse, since the image does not flip.
Physically, the projected point in a camera is behind the aperture, on the film or sensor.

% Matrices, homogeneous coordinates.
% projective element, "~" up to scale equality definition

\paragraph{Homogeneous coordinates}
In computer graphics and vision, points are usually described in \emph{homogeneous coordinates} \cite{dubrofsky2009homography,hartley03multiview,heyden2005multiple}.
An extra dimension is added to the interpretation of coordinates, and each point becomes a line that crosses the origin in a dimension one higher than the original.
Several vector operations become more convenient to manipulate: for example, 3D translation is embedded in 4D matrices with homogeneous coordinates.
The space is scale-invariant; all points $(xw, yw, zw, w)$ ($w \neq 0$) map to the same 3D point $(x, y, z)$.
This freedom of scaling makes many camera matrices defined only up to scale, as will follow.

%Homography definition (mapping of points and lines in $P^2$)

\paragraph{Camera parameters}
The imaging process essentially captures a projection to a flat two-dimensional plane of the camera's view.
When comparing points between different cameras that view the same scene, the cameras' relative positions and rotations must be known.
One of the cameras is often conveniently chosen as the origin of a global coordinate frame, so that its extrinsic parameters become unity transforms (many programming libraries may assume this, e.g., OpenCV \cite{opencv}).
%Each three-dimensional point in the world is transformed to the small sensor inside the camera, which is then digitized to a discrete two-dimensional grid of pixels, with different coordinate units.
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

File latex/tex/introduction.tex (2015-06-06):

\section{Introduction}

% no page numbers and stuff
\thispagestyle{empty}

\subsection{Background and motivation}

% introintro

The real world where we live in consists of visually three-dimensional (3D) objects.
Photographs and drawings of it, on the other hand, are flat, only two-dimensional (2D) \emph{projections}.
Specifically, a camera takes a projection of a scene by capturing the light traveling around in the scene, originated from light sources, ending up to the flat film or digital image sensor.
The result is a distorted view of the 3D dimensions and colors, depending on illumination and camera pose.

% introduce computer graphics and the need for content
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

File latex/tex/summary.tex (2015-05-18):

%Yhteenveto
% "further work remains to .."
\section{Conclusions and future work} \label{sec:conclusion}

The purpose of this thesis was to build a rig for turning real life subjects into three-dimensional digital models, using a technique called \emph{multi-view stereo reconstruction}.
Modern reconstruction rigs are increasingly necessary for both content production and reconstruction research, as computing power increases and reconstruction methods advance.
While the same methods are applicable for any number of digital cameras of any quality, the aim in this work was ease of use and high photographic quality.
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

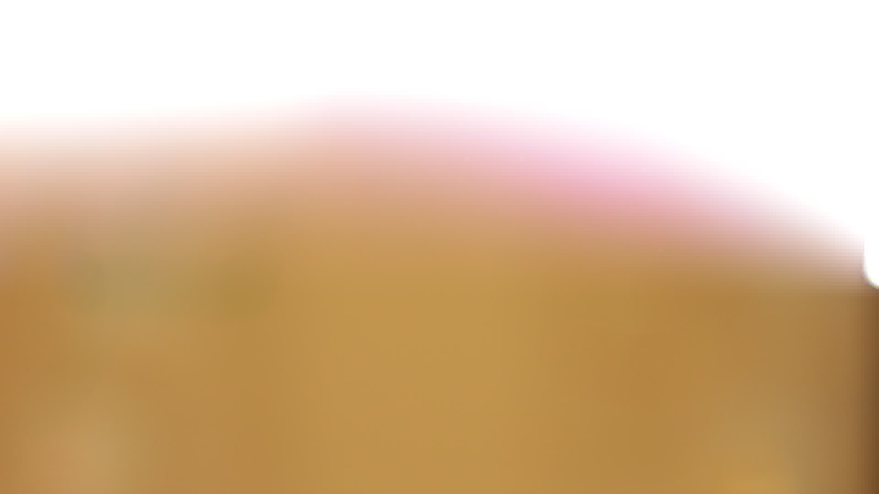
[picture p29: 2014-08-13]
latex/gfx/bitmap/flashtiming-a.jpg

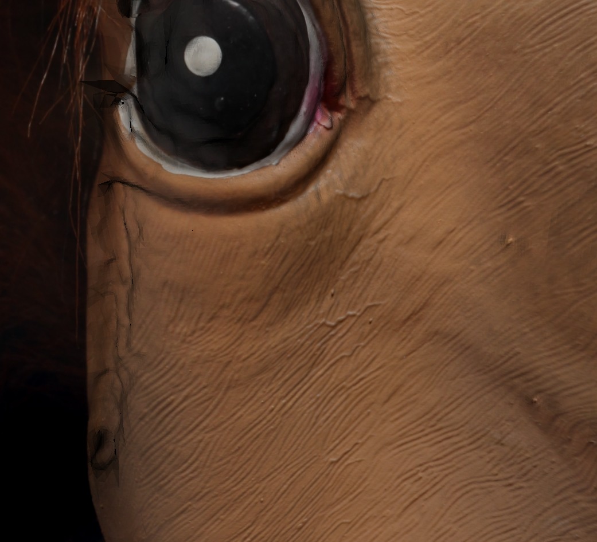
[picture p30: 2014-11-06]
finalpresis/gfx/horseclose-tex.jpg

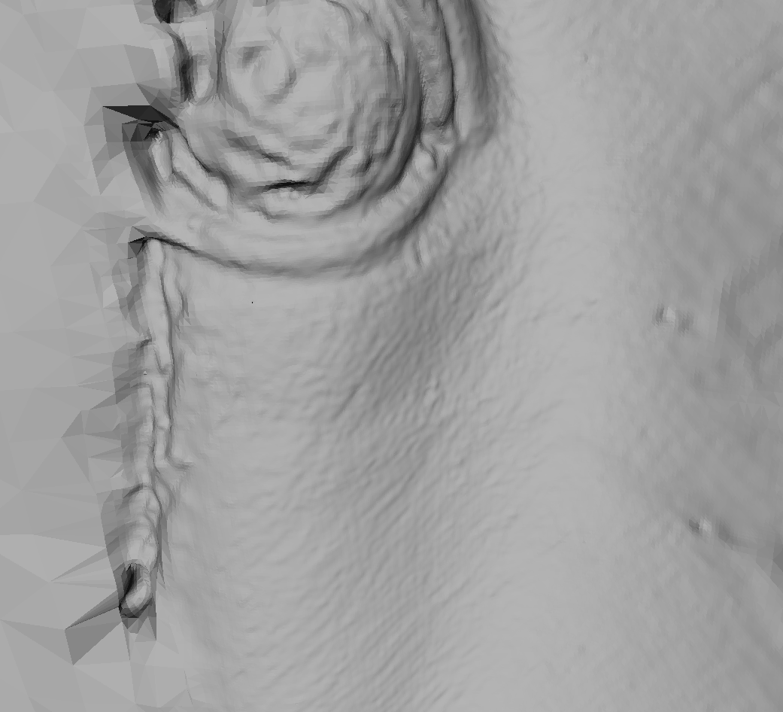
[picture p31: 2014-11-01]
finalpresis/gfx/horseclose-solid.png

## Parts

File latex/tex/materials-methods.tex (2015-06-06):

\section{3D scanning rig implementation} \label{sec:implementation}

Now that the background has been introduced, the practical part of this thesis follows.
Specifications for a 3D scanning rig are given and different off-the-shelf camera types are compared more in depth.
Suitable cameras for the task are then selected and described, along with the decisions on mechanical support construction.
Control software for the rig is developed, and a survey is given on the readily available offering of reconstruction software.

\subsection{Functional specification} % {{{

Constraints on the rig were specified in loose terms, leaving detailed work on the background study.
Furthermore, not all features of a general-purpose reconstruction rig can be addressed by the mathematical background only.
Desirable properties of the system were given as:

\begin{itemize}
	\item Ease of use and practicality: the user should not need to know the implementation details (hardware internals or algorithms) or to have programming skills to calibrate the system and acquire a 3D scan; scanning should be as simple as pressing a button
	\item Flexibility: for research purposes, the rig should be applicable to different types of subjects
	\item Mobility: the system should not pose requirements on the environment it is set up in
	\item Detail: high image resolution should be used for achieving data for state-of-the-art algorithms
	\item 3D and 4D: possibility for both static surface reconstruction and variations in geometry over time are preferred
	\item Open design: by documenting the rig well and selecting readily available generic components, a similar system could be built if there was such a need, and the already built system could be easily extended
	\item Reasonable price: the total budget of all hardware and software combined should not exceed 10~000 EUR.
\end{itemize}

Flexibility for arbitrary subjects is achieved by using adjustable connections for each camera, such that their poses can be changed individually.
Distance to the photographed target should not be too short in order to not disturb human subjects, but on the other hand, a large setup may be difficult to build and would consume space unnecessarily.
When capturing video, the frames should be synchronized among cameras as described in Section \ref{sec:video}, which might not be perfectly possible with consumer hardware.
A mobile rig should be light enough to carry, set up, and reconfigure for new subjects, but it should be rigid enough to give proper quality pictures and hold its calibrated configuration during use.
Cameras are chosen among pocket cameras, system cameras, and industrial machine vision systems currently in the market.

% }}}

\subsection{Camera comparison} \label{sec:cameracomparison} % {{{

Section \ref{sec:cameratypes} presented the typical properties of different camera categories in general, and compared them to technical requirements.
In this section, focus is more on the feasibility of the properties on reconstruction, and on selecting a collection of feasible cameras fitting in the budget.

\paragraph{General requirements}
Small close-up subjects in the range of a metre or less introduce concerns in shallow depth of field, forcing the lens aperture small using a large image sensor, and consequently, requiring bright lights or slow shutter speeds.
For automatic capture using multiple cameras simultaneously, reliability in configurations and controls is important.
Due to the large number of cameras required, practical features are also necessary to take into account, such as availability of external power supply instead of batteries.
For static photography, an external shutter release tool is required for the cameras for simultaneous shooting.
Furthermore, it must be possible to download the imagery from the cameras directly to a computer.

With a fixed budget, maximizing the scanned surface coverage of the subject requires to strongly consider the camera price, as long as the minimum required features are covered: with more cameras, a larger subset of the subject surface can be photographed, resulting in a more complete model.
Cheaper compact cameras typically lack in lens robustness, raw image formats, remote configuration and manual modes.
More expensive models have comparable features, and their prices rise into the same range as with DSLRs that are more understood in the field.
In the other end of the spectrum, machine vision cameras have the best flexibility but may require customized, vendor-specific tools and are expensive.
All the properties should be looked as a whole; e.g., large pixel count does not necessarily imply better pictures if the MTF of the optical system is poor.

\paragraph{Previous work}
DSLRs have been popular in commercial static capture setups \cite{ir-ltd,ten24,capturelab,agisoftforum,winder2008technical} probably due to their price compared to specialized hardware, and software availability.
Commercial video capture setups may use specialized machine vision devices and hardware-accompanying or customized software for image capture and reconstruction \cite{al2013new}.
Also standard commercial video cameras have been used \cite{bradley2010high}, but their resolution is limited compared to still cameras.
As an example, Borshukov et~al.\ used professional Sony/Panavision HDW-F900 video cameras for the movie The Matrix Reloaded \cite{borshukov05universal} producing uncompressed video, with a list price exceeding \$80000 \cite{sonyhdwf900r}.
Machine vision cameras have also been used where synchronization was especially important \cite{carceroni2002multi,bickel2007multi}; such cameras have also limited resolution.

\paragraph{Specialized hardware}
Self-contained consumer devices contain the image processing pipeline from sensor to mass storage by themselves.
In contrast, machine vision devices need several high performance computers for reliable multi-camera capture because of the lack of local storage and image processing pipelines.
A machine vision camera contains typically only the imaging sensor and a processor for a control interface, and outputs easily 1 Gbit/s worth of raw data or more.
A common desktop computer and one additional hard disk per camera would be necessary if the capture is long enough and would not fit in a computer's RAM, increasing the system cost and complexity.
Best mechanical hard disks currently have sequential write speed up to 1-1.4 Gbit/s as measured by Tom's Hardware \cite{tomshw-hddwrite};
newer solid-state drives (SSD) generally are two to four times faster \cite{tomshw-ssdwrite}.
For covering all the bandwidth, expansion cards would be needed per camera, count depending on the camera protocol.
Most PC motherboards can accommodate only a few cards, requiring several PCs.

Transfer speeds given by specifications and theoretical maximum frame rates for typical 12-bit raw full-HD frames are listed in Table \ref{tab:busspeeds} ordered by speed; achievable rates would be less depending on bus protocol overhead \cite{hornberg2007handbook,ni2013choosing}.
Benchmarked \cite{tomshw-sdwrite,tomshw-cfwrite} write speeds for Compact Flash (CF) and Secure Digital (SD) cards used in consumer cameras are also given for comparison.
The write speed of the cameras themselves must also be taken into account.

\begin{table}[t]
	\centering
	\begin{tabular}{l l l}
		Bus type & max.~theoretical speed & full-HD FPS\\
		\hline \\
		Camera Link \cite{ni2013choosing} & 5.44 Gb/s & 218 Hz\\
		USB 3.0 \cite{ni2013choosing} & 3.2 Gb/s & 128 Hz\\
		CF card \cite{tomshw-cfwrite} & 1030 Mb/s & 41 Hz\\
		GigE \cite{ni2013choosing} & 1.0 Gb/s & 40 Hz\\
		IEEE 1394 \cite{ni2013choosing} & 800 Mb/s & 32 Hz\\
		SD card \cite{tomshw-sdwrite} & 490 Mb/s & 19 Hz\\
		USB 2.0 \cite{ni2013choosing} & 480 Mb/s & 19 Hz\\
	\end{tabular}
	\caption{Bus speeds and corresponding naive maximum frame rates per second for 1920 x 1080 pixels x 12 bits; actual speeds would be lower}
	\label{tab:busspeeds}
\end{table}

\paragraph{Preferred properties}
A camera is required to have several properties, and the system as a whole must be taken as a global optimization problem, since some properties conflict each other.
In detail, the technical camera features that should be considered are described in Section \ref{sec:image-acquisition} and features that vary among different cameras are listed below.
Main properties affecting image quality directly are as follows:

\begin{itemize}
	\item CMOS/CCD sensor..
		CMOS suffers from rolling shutter in video mode, while global-shutter CCD is more expensive and rare in larger formats but also more responsive to light.

	\item Sensor resolution and physical size.
		Higher resolution covers more detail, until the optical limits of the system are reached.
		A larger sensor has larger pixels, and is thus more responsive to light and results in lower noise and lower required exposure time.
		On the other hand, at an equivalent subject distance, a deeper DOF is achieved with a smaller sensor.

	\item Low noise.
		Sensor noise degrades image quality in general, adds error to subpixel position estimation and complicates correspondence search, etc.

	\item Dynamic range, i.e., bit depth of the processing pipeline.
		Whereas JPEG pictures in some cameras have only 8 bits per color channel, the typically higher bit depth of the sensor is available in raw image formats.

	\item Lens quality.
		High sensor resolution is only useful if the lens is sharp enough, and color aberrations degrade image quality in general.
		Fixed focal length lenses have less moving parts and hold their calibration better.
		The performance of good lenses is usually given as an MTF, modulation transfer function, describing the contrast.
\end{itemize}

On practical matters affecting image quality:

\begin{itemize}
	\item Optical stabilization works by moving a glass element inside the lens or the sensor itself, effectively moving the image on the sensor, having also a negative effect on calibration.
		Such feature would be turned off as harmful and unnecessary, since the cameras would be mounted rigidly.

	\item Dust reduction.
		If enabled for some consumer cameras, it is typically implemented as high-frequency vibration of the sensor on camera startup.
		Moving the sensor might result in small calibration problems.

	\item Shutter lag.
		Lag measured between ordering the camera to take the picture to the actual moment where exposure starts should be consistent, and preferably small.

	\item Video frame rate, resolution, and compression.
		Consumer cameras that support a raw format only use raw for still pictures and compress the video.
		Raw video is seen often unnecessary in the consumer market and poses high requirements on memory space and processing speed.
		For image processing, each frame should be compressed as little as possible.
		Some system cameras support writing only full keyframes instead of predicted frames, resulting in higher quality and file size.

\end{itemize}

On practical matters affecting usability:

\begin{itemize}
	\item Lens features.
		While photography lenses typically support electronic and even automatic focusing, machine vision lenses typically have mechanically adjustable focus and aperture.
		Of photography devices, compact cameras feature an integrated zoom lens, while system cameras feature interchangeable lenses.

	\item Continuous shooting rate, i.e., the speed at which full-size pictures can be taken.
		Controlled by many factors, on consumer cameras, image processing speed and memory card write speed have most effect, and on MV cameras, the bus speed typically limits the rate, and sensor speed is selected based on the bus speed.

	\item Configurability.
		Aperture, shutter speed and others should be manually controllable remotely, and repeatable without automatic features.

	\item Remote trigger.
		Practically all DSLRs support wired or wireless remote shutter releases; some machine vision cameras have optionally an external logic-level trigger input in addition to one that is set by the protocol in the data bus.

	\item For consumer cameras, USB read speed supported by the camera.
		Retrieving saved image or video data takes less time on faster interfaces.

	\item External flashes.
		Practically all system cameras can be wired to an external flash unit; only some compact cameras support this.

	\item External power supply.
		Not needing to charge batteries adds value to the ease of use.

	\item Weight and size.
		A smaller and lighter camera requires less bulky support structures.

	\item Price.
		With a fixed budget, cheaper cameras can cover a larger area of the subject at a time.

	\item Availability.
		For an easily replicable system, it should be straightforward to acquire the hardware.
\end{itemize}

% }}}

\subsection{Selected cameras} % {{{

A number of compacts, system cameras, and machine vision cameras were reviewed.
In this section, the selected key parts are described in detail.
Precise information on all hardware used can be found in Appendix \ref{app:hardwareused}.

In general, machine vision cameras were considered overly expensive, although they perform best in synchronized video and output the frames in lossless raw format.
Compact cameras do not have significant advantages over DSLRs, when comparing models where both have comparable required features, such as external shutter release options and options for external flash units.
The biggest advantage of DSLRs over compacts is the proven compatibility with other parts of the system (hence the name \emph{system camera}) and mature support for remote controls.

A DSLR is a good choice for still photos because of moderate price compared to image quality, and availability of usable software and best range of accessories.
Video recording is notably worse than with machine vision cameras that can produce raw data, synchronized output, and (typically) higher resolution.
Because of a price difference of almost an order of magnitude for cameras having a comparable resolution, it was decided to leave high-performance video tracking as a minor feature, and concentrate on static subjects.
Canon was chosen over other brands because of firmware customizability \cite{magiclantern}, previously acquired personal knowledge of the manufacturer, well specified and mature remote control abilities compared to alternatives (see Section \ref{sec:cameracontrollib}), and previously proven work using the same brand \cite{ir-ltd,ten24,capturelab,agisoftforum,ghosh2011multiview}.

\subsubsection{Canon EOS 700D DSLR}

\simplefig{t}{%

}{fig:eos700d}
{Canon EOS 700D DSLR camera body}

Canon EOS 700D body, also known as the Rebel T5i, introduced in 2013, is the newest of Canon's consumer range DSLRs at the time of writing, with a price at about 600-700 EUR.
More expensive models would not add considerable value to the rig, as their advantages are mostly in durability for practical photography.
Key features are shown in Table \ref{tab:eos700dfeatures} and the front and back view of the camera are depicted in Figure \ref{fig:eos700d}.
The built rig consists of nine cameras arranged as a $3 \times 3$ grid.

\begin{table}[t]
	\centering
	\begin{tabular}{l l}
		Sensor type & CMOS\\
		Sensor size & APS-C 22.3 x 14.9 mm\\
		Pixel size & 4.3 x 4.3 $\text{\si\micro m}$\\
		Image resolution & 5184 x 3456 pixels (17.9 million) \\
		Processor & Canon Digital Imaging Core (DIGIC) 5\\
		Bits per pixel & 14\\
		Burst shooting speed & 5 FPS\\
		Video mode & 1080p in 30 FPS or 720p in 60 FPS\\
		Max write speed & $\approx$ 40 MB/s
	\end{tabular}
	\caption{Canon EOS 700D key features}
	\label{tab:eos700dfeatures}
\end{table}

\paragraph{Properties}
Relatively large pixel count combined to a good lens captures high-resolution detail.
The sensor's pixel size is not unnecessarily small but not as large as in full frame DSLR cameras.
% raw images useful for manual image enhancement
The 5 FPS continuous speed for full-size images can be used for testing high resolution motion, but the video abilities are also reasonable.
Ghosh et~al.\ \cite{ghosh2011multiview} use DSLRs operating in burst mode for special illumination capture, which presents one augmentation for the rig in future work.
The quality can be tweaked with firmware modifications and raw video recording is also possible, at a reduced resolution limited by storage speed \cite{magiclantern}.
The sensor is labeled ``Hybrid CMOS'', a new Canon's technology that embeds phase-detection autofocus pixels in the sensor for fast continuous autofocusing in video mode.
A number of pixels are missing color sparsely around the middle of the sensor and are interpolated; they only introduce artifacts in raw video.

The recent Canon EOS M MILC shares many features and internal elements with EOS 700D and was strongly considered, but it is missing support for remote shooting from USB or wired remote release.

Resolution of the sensor has stayed same since the EOS 550D, introduced in 2010.
At the same time, also cheaper new models are available, such as the EOS 1200D; at a reduced price, less processing power is provided, resulting in slower operation but otherwise the cameras share mostly same features.

\paragraph{Storage}
The camera uses Secure Digital (SD) memory cards for mass storage, supporting the UHS-I standard (Ultra High Speed) \cite{sdcardspeed}.
Maximum write speed has been found experimentally to be approximately 40 MB/s \cite{magiclanternforum}.
A class 10 UHS-I memory card was selected; manufacturer claims 45 MB/s write speed.

\paragraph{Conveniences}
The camera also features a tilting LCD screen that has provided to be useful when looking the camera from the front.
Additionally, AC power adapters were chosen to operate the cameras without the need for charging batteries.
The adapters plug in the camera's battery holder, providing continuous power at the expense of an additional cable per camera.
For wireless remote shutter, the camera natively supports an infrared remote controller that must be pointed towards the camera from the front.

% flashguns

\subsubsection{Canon EF 50mm f/1.8 II}

Canon's EF 50mm f/1.8 II lens (priced at about 110 EUR), shown in Figure \ref{fig:canonef50mmlens} is well known for its excellent image quality at a low price.
The lens was introduced in 1990.
The 50 mm focal length with the crop factor of 1.6 of the camera body provides a good shooting distance for the purposes of this work.
Like most lenses at this focal length, the lens is nearly distortion free.
Despite the poor plastic build quality, its optical characteristics are well known to be of very high quality for the price.
The lens changes between autofocus and manual focus modes with a mechanical switch, and the focus ring in manual focus mode is loose enough that it might need to be locked with tape if left on for a long time shooting to hold its position for a calibrated setup.

At a distance of one metre $d = 1$ m, the sensor size of $s_x \times s_y$ = $22.3 \times 14.9$ mm and $f = 50$ mm focal length, the area that fits in the frame is $a_x \times a_y$
\begin{align} \label{eq:areasize} \begin{split}
	a_x &= s_x \times \frac{d}{f} = 22.3 \text{mm} \times \frac{1 \text{m}}{50 \text{mm}} = 446 \text{mm}\\
	a_y &= s_y \times \frac{d}{f} = 14.9 \text{mm} \times \frac{1 \text{m}}{50 \text{mm}} = 298 \text{mm}
\end{split} \end{align}
which is easily seen from similar triangles with a common corner.
From Equation \ref{eq:dof}, the depth of field (using the d/1500 rule) at this setting is about 16 cm for a f-number of f/11, or 20 cm for f/14, at circle of confusion of 0.019 mm, a reasonable depth for the given area size.
This circle of confusion would span $0.019 \text{mm} / 22.3 \text{mm} \times 5184 \text{px} \approx 4.4$ pixels.

\simplefig{t}{%
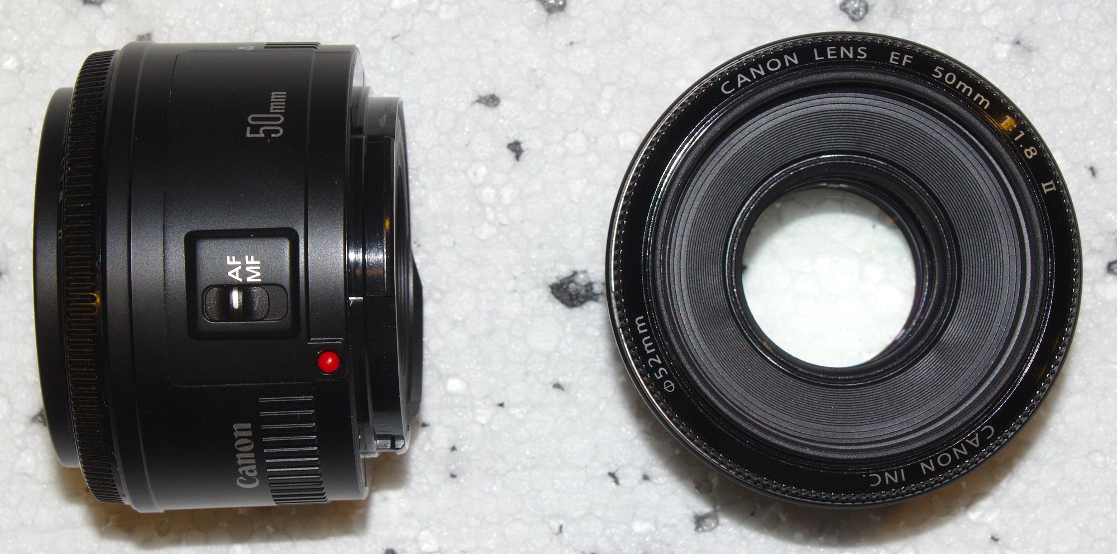
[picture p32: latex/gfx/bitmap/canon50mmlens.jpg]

}{fig:canonef50mmlens}
{Canon EF 50mm f/1.8 II, a fixed focal length lens with manual focus and autofocus}

\subsubsection{Magic Lantern}

An important consideration was the ability to use the third-party Magic Lantern (ML) firmware add-on \cite{magiclantern};
it was originally developed for improved user interfaces in video recording, but has been extended for numerous other features.
It was installed on each camera in the rig.
Firstly, it provides experimental support for raw video recording, easier remote triggering for video, and other hacks;
additionally, being open source, it can be modified for any custom purposes, such as multi-camera synchronization aids, if necessary.
It is a separate native program for the ARM-based DIGIC processor, and runs in the camera alongside the original firmware, loaded from the memory card, using the same operating system and configuration menus \cite{magiclantern}.
A screenshot of a menu grid displaying some of the additional functions is shown in Figure \ref{fig:ml-menu}.

The add-on is installed on a memory card, and it does not make permanent changes to the camera's original firmware.
Still, being third-party software based on reverse-engineering efforts, there is a small risk of unexpected instability.
Magic Lantern has an active user forum \cite{magiclanternforum}, a wiki, and an automatic software build system for releasing nightly testing versions.
As an open source project developed in a distributed fashion, it suffers from inconsistent documentation and coding style, and is occasionally best examined by reading source code, written in the C programming language.
No ``stable'' release is offered for EOS 700D yet, but the unofficial testing version has been long in use.

\simplegfx{t}{0.9\textwidth}{ml-menu}{
	Magic Lantern grid menu in movie mode, showing a subset of its features.
}

% }}}

\subsection{Hardware construction} % {{{

The cameras need additional support structures for mounting.
A trivial solution would be a tripod for each camera, which would not allow stacking the cameras vertically, though.
Two main methods were considered and are described below.

\subsubsection{Mechanical options}

With flexibility and mobility as requirements, the system should be built of removable parts that need no modifications to the environment, such as attachments to walls.
The separate parts should be small enough for transportation, but large enough for rigidity and build simplicity.
Each camera should be able to turn at least in landscape and portrait mode to fully utilize the picture frame for portrait subjects, such as human faces.

Two different major designs were considered: a hinged frame consisting of industrial aluminium profile system, or individual tripod stands available in most photography stores meant for supporting audiovisual equipment.
For connecting the cameras, a custom profile could make use of also custom built parts; also, photography stores sell screws and clamps meant for connecting cameras, lights and other hardware.

Aluminium profiles such as those by MiniTec, Item or Bosch Rexroth consist of rectangular tube with a T-shaped slot running along each side for screws.
%The profile systems are commonly used in assembly lines and other automation installations in factories, but also in smaller assemblies
Mechanical dimensions vary by manufacturer but most supply a large catalog of connection brackets, hinges, screws etc.\ that allow much flexibility in the frame design.
A hobbyist-purposed manufacturer OpenBuilds targets open source projects, such as 3D printers and CNC routers.
The cost of such profile is around 10-20 EUR/m, with varying prices for connection pieces; availability varies by supplier.

Ready-made light or speaker stands come in a variety of sizes and share a common design with an extendable center rod and three legs.
Typical light stands have a universal mount in top end of the rod for fastening a lamp.
Speaker stands typically share a similar standard; in general, they are also heavier and thicker to support a larger mass.
Most photography and audio/video studio stores offer a variety of light and speaker stands.

A custom aluminium profile system would have its benefits in rigidity and positional flexibility, because it could be built in any shape.
On the other hand, one rigid shape would be more difficult to modify when any change were needed.
Standard light or speaker stands are attractive because of their availability in normal stores.
They also can be moved around, which also means more work in configuring the camera poses again.
A stand consisting of mostly round rods lacks flat surfaces and slots that could be used for fastening parts together.
For that purpose, special clamps and ball heads are sold separately.
Machine vision cameras do not generally use the same tripod screws aimed for consumer market, but are screwed on the frame with custom bases.

\subsubsection{Selected design}

The method of choice was to use ready-made, heavy duty lighting stands.
Millenium LST-310 (a brand by the Thomann music equipment store \cite{thomann}) is a sturdy three-legged lighting stand with a pole that can be extended several meters high.
Additionally, it has a rotating horizontal bar at the top.
Similar tripods were used in other projects in the same laboratory and they were found useful and rigid.
The relatively heavy weight (approximately 10 kg per stand) makes the support structures steady.
Four of these stands were bought, which should allow a moderate coverage around a subject in pairs of cameras.

For flexibility, each camera should be able to rotate in at least to horizontal or vertical pose, with arbitrary aiming position.
Manfrotto 494 ball heads \cite{manfrotto494} were used for this purpose, connected to the tripod rod with Manfrotto 035 Super Clamps \cite{manfrotto035}.
Figure \ref{fig:camconnection} shows a complete connection from a stand pole to a camera.

The total structure of all nine cameras divided in three supports (Figure \ref{fig:totalsetup}) takes up relatively little space, and is flexible to set up around any human-size subject or smaller.
The stands can be carried in bags and the more fragile parts are fitted in two cases shown in Figure \ref{fig:cases}.

Wires and power adapters are fastened to the stand legs in long-term use to reduce wires running on the floor.

\simplefig{t}{%
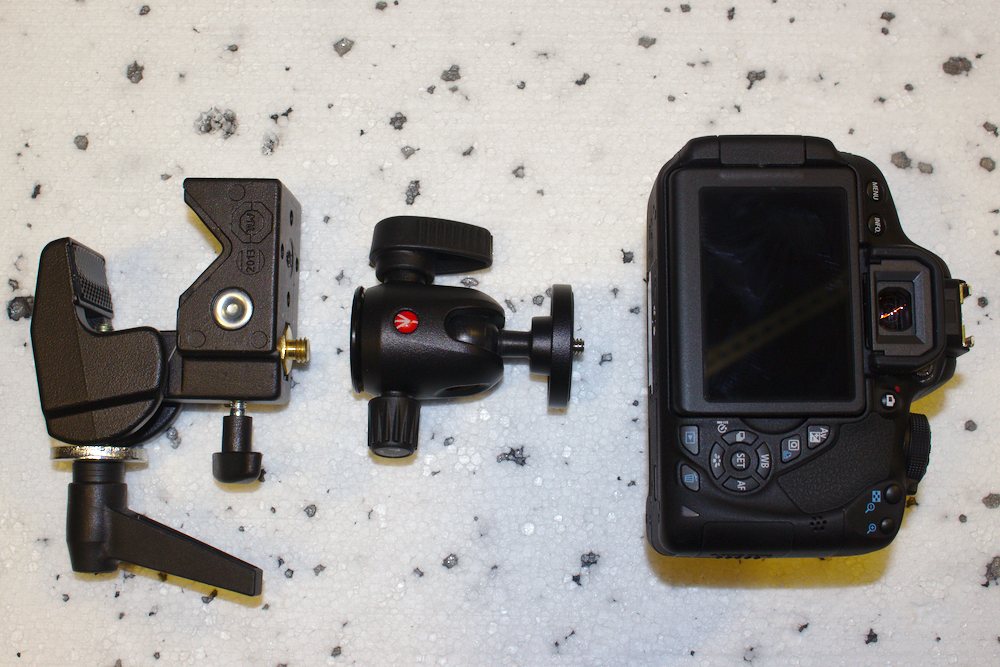
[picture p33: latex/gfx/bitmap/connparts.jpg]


}{fig:camconnection}{
	Left: the Super Clamp, ball head, and a camera separately.
	Right: one camera connected to the pole and its wires.
}

\simplegfx{t}{\textwidth}{totalsetup}{
	Complete setup with cameras and spot lights for video recording.
	In typical scans, the cameras would be slightly closer to each other.
}

\simplegfx{t}{\textwidth}{cases}{
	The fragile parts of the system fit in two equipment cases padded with soft foam rubber.
}

\subsubsection{Lighting}

An even lighting is necessary to capture the subject properly, as described in Section \ref{sec:bg-lighting}.
Unwanted lighting artifacts include harsh shadows and sharp reflections.
Most shadows affect the scanned colors in an unwanted way, since the subject is to be relighted in a digital environment where shadows are formed artificially by calculating the brightness in every illuminated pixel separately.
Sharp reflections make reconstruction harder, since the position of the reflection depends on the viewing direction, making the appearance of the surface different in different views.

In still photographs, flash units ``bounced'' from white objects are a practical way to achieve a good lighting.
Typical flash units are either bounced away from white umbrellas sold for this particular purpose, or shot through a large and semitransparent cloth.
For video recording, either a continuous light source or a high-frequency stroboscope synchronized to the video frame rate would be needed.
Since the selected cameras do not support frame synchronization, a continuous light is necessary.

In the scope of this work, no lights were purchased, as readily available flash units and spot lights in the workplace could be used temporarily to evaluate the amount of light needed.
Two standard flash guns attached to the cameras were used for still photograph samples, and three studio spot lights were tested for video recording.
Detailed description on the lights is given in Section \ref{sec:samplesubjects}.

% }}}

\subsection{Universally synchronized multi-trigger hub} % {{{

To fully automate the system, it is desirable to trigger the cameras remotely from a computer that also downloads the photos.
Additionally, for a rig with possibly non-static subjects but an intended result of a still subject, the cameras have to be synchronized to record the subject at the same instant in time.
This section describes the remote shutter mechanism and a custom tool that was built for the task.
The cameras are enabled to shoot in arbitrary order, while the most common order would be to shoot all cameras synchronously.
An alternative method in synchronization could have been one third-party wireless remote trigger per camera;
however, they are expensive, may be not as consistent as a wired solution, and would require modifications to work connected to a computer.
Similarly, custom and undocumented solutions previously used for hard synchronization for machine vision cameras cameras, e.g., by Bickel et~al.\ \cite{bickel2007multi} include ready-made USB I/O boards such as those provided by Data Translation \cite{datatranslation}.

\subsubsection{Remote shutter synchronization} % {{{
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

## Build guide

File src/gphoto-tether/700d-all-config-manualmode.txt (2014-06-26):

/main/actions/uilock
Label: UI Lock
Type: TOGGLE
Current: 2
/main/actions/syncdatetime
Label: Synchronize camera date and time with PC
Type: TOGGLE
Current: 0
/main/actions/autofocusdrive
Label: Drive Canon DSLR Autofocus
Type: TOGGLE
Current: 0
/main/actions/manualfocusdrive
Label: Drive Canon DSLR Manual focus
Type: RADIO
Current: None
Choice: 0 Near 1
Choice: 1 Near 2
Choice: 2 Near 3
Choice: 3 None
Choice: 4 Far 1
Choice: 5 Far 2
Choice: 6 Far 3
/main/actions/eoszoom
Label: Canon EOS Zoom
Type: TEXT
Current: 0
/main/actions/eoszoomposition
Label: Canon EOS Zoom Position
Type: TEXT
Current: 0,0
/main/actions/eosviewfinder
Label: Canon EOS Viewfinder
Type: TOGGLE
Current: 2
/main/actions/eosremoterelease
Label: Canon EOS Remote Release
Type: RADIO
Current: None
Choice: 0 None
Choice: 1 Press Half
Choice: 2 Press Full
Choice: 3 Release Half
Choice: 4 Release Full
Choice: 5 Immediate
Choice: 6 Press 1
Choice: 7 Press 2
Choice: 8 Press 3
Choice: 9 Release 1
Choice: 10 Release 2
Choice: 11 Release 3
/main/settings/datetime
Label: Camera Date and Time
Type: DATE
Current: 1403798178
Printable: Thu 26 Jun 2014 18:56:18 EEST
/main/settings/reviewtime
Label: Quick Review Time
Type: RADIO
Current: 2 seconds
Choice: 0 None
Choice: 1 2 seconds
Choice: 2 4 seconds
Choice: 3 8 seconds
Choice: 4 Hold
/main/settings/output
Label: Camera Output
Type: RADIO
Current: Off
Choice: 0 Off
Choice: 1 TFT
Choice: 2 PC
Choice: 3 TFT + PC
Choice: 4 Setting 4
Choice: 5 Setting 5
Choice: 6 Setting 6
Choice: 7 Setting 7
/main/settings/movierecordtarget
Label: Recording Destination
Type: RADIO
Current: Disabled
Choice: 0 Disabled
/main/settings/evfmode
Label: EVF Mode
Type: RADIO
Current: 1
Choice: 0 1
Choice: 1 0
/main/settings/ownername
Label: Owner Name
Type: TEXT
Current: 
/main/settings/artist
Label: Artist
Type: TEXT
Current: D
/main/settings/copyright
Label: Copyright
Type: TEXT
Current: 
/main/settings/customfuncex
Label: Custom Functions Ex
Type: TEXT
Current: 10,c189,d105,3,
/main/settings/autopoweroff
Label: Auto Power Off
Type: TEXT
Current: 240
/main/settings/capturetarget
Label: Capture Target
Type: RADIO
Current: Internal RAM
Choice: 0 Internal RAM
Choice: 1 Memory card
/main/settings/capture
Label: Capture
Type: TOGGLE
Current: 0
/main/status/serialnumber
Label: Serial Number
Type: TEXT
Current: 2aceea40e61e44478c7460ec35881e61
/main/status/manufacturer
Label: Camera Manufacturer
Type: TEXT
Current: Canon Inc.
/main/status/cameramodel
Label: Camera Model
Type: TEXT
Current: Canon EOS 700D
/main/status/deviceversion
Label: Device Version
Type: TEXT
Current: 3-1.1.1
/main/status/vendorextension
Label: Vendor Extension
Type: TEXT
Current: None
/main/status/model
Label: Camera Model
Type: TEXT
Current: 2147484454
/main/status/ptpversion
Label: PTP Version
Type: TEXT
Current: 256
/main/status/batterylevel
Label: Battery Level
Type: TEXT
Current: 100%
/main/status/lensname
Label: Lens Name
Type: TEXT
Current: EF50mm f/1.8 II
/main/status/eosserialnumber
Label: Serial Number
Type: TEXT
Current: 083031014965
/main/status/shuttercounter
Label: Shutter Counter
Type: TEXT
Current: 499
/main/status/availableshots
Label: Available Shots
Type: TEXT
Current: 238310
/main/imgsettings/imageformat
Label: Image Format
Type: RADIO
Current: Smaller JPEG (S2)
Choice: 0 Large Fine JPEG
Choice: 1 Large Normal JPEG
Choice: 2 Medium Fine JPEG
Choice: 3 Medium Normal JPEG
Choice: 4 Small Fine JPEG  (S1 Fine)
Choice: 5 Small Normal JPEG (S1 Normal)
Choice: 6 Smaller JPEG (S2)
Choice: 7 Tiny JPEG (S3)
Choice: 8 RAW + Large Fine JPEG
Choice: 9 RAW
/main/imgsettings/imageformatsd
Label: Image Format SD
Type: RADIO
Current: Smaller JPEG (S2)
Choice: 0 Large Fine JPEG
Choice: 1 Large Normal JPEG
Choice: 2 Medium Fine JPEG
Choice: 3 Medium Normal JPEG
Choice: 4 Small Fine JPEG  (S1 Fine)
Choice: 5 Small Normal JPEG (S1 Normal)
Choice: 6 Smaller JPEG (S2)
Choice: 7 Tiny JPEG (S3)
Choice: 8 RAW + Large Fine JPEG
Choice: 9 RAW
/main/imgsettings/iso
Label: ISO Speed
Type: RADIO
Current: 1600
Choice: 0 Auto
Choice: 1 100
Choice: 2 200
Choice: 3 400
Choice: 4 800
Choice: 5 1600
Choice: 6 3200
Choice: 7 6400
Choice: 8 12800
/main/imgsettings/whitebalance
Label: WhiteBalance
Type: RADIO
Current: Auto
Choice: 0 Auto
Choice: 1 Daylight
Choice: 2 Shadow
Choice: 3 Cloudy
Choice: 4 Tungsten
Choice: 5 Fluorescent
Choice: 6 Flash
Choice: 7 Manual
/main/imgsettings/colortemperature
Label: Color Temperature
Type: TEXT
Current: 5200
/main/imgsettings/whitebalanceadjusta
Label: WhiteBalance Adjust A
Type: RADIO
Current: 0
Choice: 0 -9
Choice: 1 -8
Choice: 2 -7
Choice: 3 -6
Choice: 4 -5
Choice: 5 -4
Choice: 6 -3
Choice: 7 -2
Choice: 8 -1
Choice: 9 0
Choice: 10 1
Choice: 11 2
Choice: 12 3
Choice: 13 4
Choice: 14 5
Choice: 15 6
Choice: 16 7
Choice: 17 8
Choice: 18 9
/main/imgsettings/whitebalanceadjustb
Label: WhiteBalance Adjust B
Type: RADIO
Current: 0
Choice: 0 -9
Choice: 1 -8
Choice: 2 -7
Choice: 3 -6
Choice: 4 -5
Choice: 5 -4
Choice: 6 -3
Choice: 7 -2
Choice: 8 -1
Choice: 9 0
Choice: 10 1
Choice: 11 2
Choice: 12 3
Choice: 13 4
Choice: 14 5
Choice: 15 6
Choice: 16 7
Choice: 17 8
Choice: 18 9
/main/imgsettings/whitebalancexa
Label: WhiteBalance X A
Type: TEXT
Current: 0
/main/imgsettings/whitebalancexb
Label: WhiteBalance X B
Type: TEXT
Current: 0
/main/imgsettings/colorspace
Label: Color Space
Type: RADIO
Current: sRGB
Choice: 0 sRGB
Choice: 1 AdobeRGB
/main/capturesettings/focusmode
Label: Focus Mode
Type: RADIO
Current: Unknown value 0003
Choice: 0 One Shot
Choice: 1 AI Focus
Choice: 2 AI Servo
Choice: 3 Unknown value 0003
/main/capturesettings/autoexposuremode
Label: Canon Auto Exposure Mode
Type: RADIO
Current: Manual
Choice: 0 P
Choice: 1 TV
Choice: 2 AV
Choice: 3 Manual
Choice: 4 Bulb
Choice: 5 A_DEP
Choice: 6 DEP
Choice: 7 Custom
Choice: 8 Lock
Choice: 9 Green
Choice: 10 Night Portrait
Choice: 11 Sports
Choice: 12 Portrait
Choice: 13 Landscape
Choice: 14 Closeup
Choice: 15 Flash Off
/main/capturesettings/drivemode
Label: Drive Mode
Type: RADIO
Current: Continuous
Choice: 0 Single
Choice: 1 Continuous
Choice: 2 Timer 10 sec
Choice: 3 Timer 2 sec
Choice: 4 Unknown value 0007
/main/capturesettings/picturestyle
Label: Picture Style
Type: RADIO
Current: Standard
Choice: 0 Auto
Choice: 1 Standard
Choice: 2 Portrait
Choice: 3 Landscape
Choice: 4 Neutral
Choice: 5 Faithful
Choice: 6 Monochrome
Choice: 7 User defined 1
Choice: 8 User defined 2
Choice: 9 User defined 3
/main/capturesettings/aperture
Label: Aperture
Type: RADIO
Current: 5
Choice: 0 1.8
Choice: 1 2
Choice: 2 2.2
Choice: 3 2.5
Choice: 4 2.8
Choice: 5 3.2
Choice: 6 3.5
Choice: 7 4
Choice: 8 4.5
Choice: 9 5
Choice: 10 5.6
Choice: 11 6.3
Choice: 12 7.1
Choice: 13 8
Choice: 14 9
Choice: 15 10
Choice: 16 11
Choice: 17 13
Choice: 18 14
Choice: 19 16
Choice: 20 18
Choice: 21 20
Choice: 22 22
/main/capturesettings/shutterspeed
Label: Shutter Speed
Type: RADIO
Current: 1/100
Choice: 0 bulb
Choice: 1 30
Choice: 2 25
Choice: 3 20
Choice: 4 15
Choice: 5 13
Choice: 6 10
Choice: 7 8
Choice: 8 6
Choice: 9 5
Choice: 10 4
Choice: 11 3.2
Choice: 12 2.5
Choice: 13 2
Choice: 14 1.6
Choice: 15 1.3
Choice: 16 1
Choice: 17 0.8
Choice: 18 0.6
Choice: 19 0.5
Choice: 20 0.4
Choice: 21 0.3
Choice: 22 1/4
Choice: 23 1/5
Choice: 24 1/6
Choice: 25 1/8
Choice: 26 1/10
Choice: 27 1/13
Choice: 28 1/15
Choice: 29 1/20
Choice: 30 1/25
Choice: 31 1/30
Choice: 32 1/40
Choice: 33 1/50
Choice: 34 1/60
Choice: 35 1/80
Choice: 36 1/100
Choice: 37 1/125
Choice: 38 1/160
Choice: 39 1/200
Choice: 40 1/250
Choice: 41 1/320
Choice: 42 1/400
Choice: 43 1/500
Choice: 44 1/640
Choice: 45 1/800
Choice: 46 1/1000
Choice: 47 1/1250
Choice: 48 1/1600
Choice: 49 1/2000
Choice: 50 1/2500
Choice: 51 1/3200
Choice: 52 1/4000
/main/capturesettings/meteringmode
Label: Metering Mode
Type: RADIO
Current: Evaluative
Choice: 0 Evaluative
Choice: 1 Partial
Choice: 2 Spot
Choice: 3 Center-weighted average
/main/capturesettings/bracketmode
Label: Bracket Mode
Type: TEXT
Current: 0
/main/capturesettings/aeb
Label: Auto Exposure Bracketing
Type: RADIO
Current: off
Choice: 0 off
Choice: 1 +/- 1/3
Choice: 2 +/- 2/3
Choice: 3 +/- 1
Choice: 4 +/- 1 1/3
Choice: 5 +/- 1 2/3
Choice: 6 +/- 2
/main/other/d402
Label: PTP Property 0xd402
Type: TEXT
Current: Canon EOS 700D
/main/other/d407
Label: PTP Property 0xd407
Type: TEXT
Current: 1
/main/other/d406
Label: PTP Property 0xd406
Type: TEXT
Current: Unknown Initiator
/main/other/d303
Label: PTP Property 0xd303
Type: TEXT
Current: 1
/main/other/5001
Label: Battery Level
Type: MENU
Current: 100
Choice: 0 100
Choice: 1 0
Choice: 2 75
Choice: 3 0
Choice: 4 50

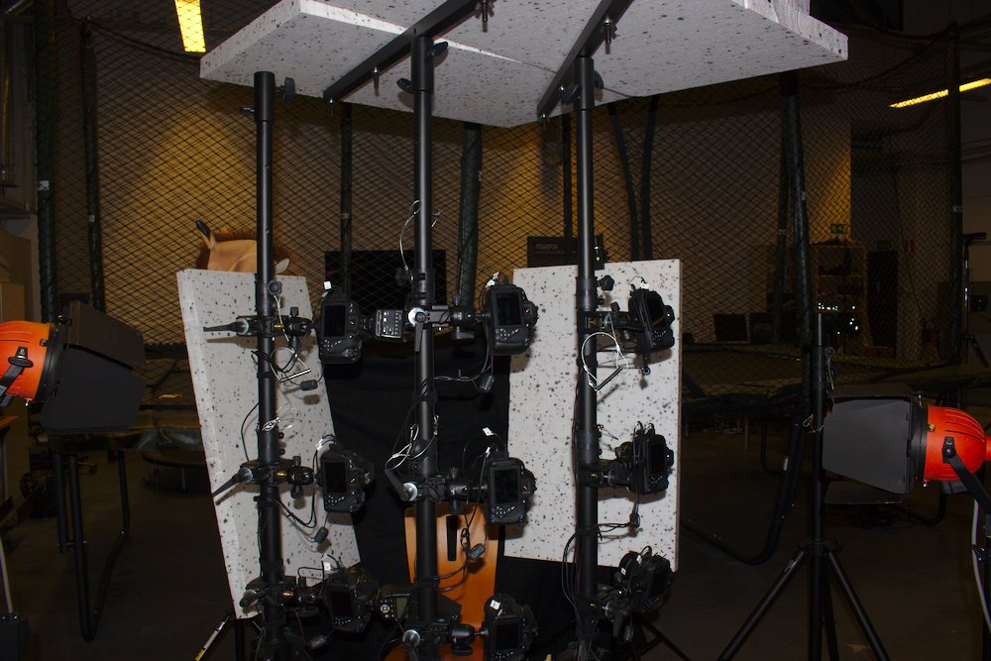
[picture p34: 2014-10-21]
latex/gfx/bitmap/wholesetup.jpg

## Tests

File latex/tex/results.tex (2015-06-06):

\section{Experiments and results} \label{sec:experiments}

The feasibility of the rig was evaluated based on custom techniques on syncronization and on several scans of different subjects.
The purpose of the experiments was to see how suitable the rig is for the task.
Synchronization was considered important from the beginning, and it was unknown how well the system would perform.
Measurements were done in static and video modes.
Photographing test subjects and running reconstruction using popular programs was considered a good way to evaluate the system as a whole, as the system was planned to be used for such methods.
Subjects with different surface materials were chosen to test if the material types would perform as expected.

\subsection{Synchronization}

Synchronizing the image sources temporally is important for reconstruction algorithms to work correctly.
A synchronized system captures images from all cameras with a reasonably small time difference between them, so that subject movement does not introduce unnecessary errors.
Nonrigid movement would introduce inconsistent noise to the reconstructed depth, as disparity would be computed from mutually inconsistent matches.

\subsubsection{Shutter delay and sync} \label{sec:shutterdelaymeas}

\emph{Shutter delay} consistency among cameras describes how well the cameras respond to the shutter release signals, and consequently, what exposure times can be used and how fast moving subjects would work.
A repeated test was conducted using the microcontroller board to accurately measure the shutter delay and its variations on several cameras.

An input pin of the Nucleo-F401RE MCU was connected to the hot shoe flash present in the camera body.
Assuming a negligible delay between the flash trigger signal and the actual photo exposure, the time between shutter signal and signal from the flash connector is the shutter delay.
The camera was set up to all manual settings and manual focus, and the focus signal was given before each measurement.
Measurements matched consistently a 75 millisecond delay, repeated shots varying less than 0.5 \%.
This level of repeatability suggests that moderately moving subjects can be captured properly.
If a synchronized light was connected to the remote trigger instead of the cameras' flash contacts, this delay would be needed to be taken into account.
The used test program for the Nucleo board can be found in the microcontroller programs directory in the github repository by the name \emph{measure.cpp}.
The different signals to all ten outputs in the remote trigger were measured with an oscilloscope to happen within 1.6 microseconds.

A special flash synchronization method was considered using the hot shoe signals of all cameras.
When the camera orders the flash to fire, its shutter is expected to be fully open.
The same controller that drives the shutter signals would then monitor the hot shoe signals, and trigger the flashes when all the shutters have opened.
The method was not deployed because the cameras are synced well enough; with shutter speeds of as high as 1/100 s, no dark frames were encountered during testing.
Maximum shutter speed using a flash for the Canon EOS 700D is 1/200 s.

\subsubsection{Still capture sync using a moving object}

In addition to the flash shoe measurement, synchronization between all nine cameras in a real setup was analyzed using a moving object.

A standard 120 mm PC fan was rotated in the view of all cameras, with markings drawn around the fan and in the moving blades with a bright-colored pen.
The cameras were set to maximum aperture (f/1.8) and shortest possible shutter speed (1/4000 s) to minimize motion blur.
This particular fan's speed had to be reduced by using 4.5 volts instead of the nominal 12 volts to clearly distinguish the blades without motion blur.

Without any actual measurements done but only with careful manual observation, no significant sync mismatches were found by comparing the position of the rotating measurements in all nine different images.
Two such images are depicted in Figure \ref{fig:fansynctest}.

\simplefig{t}{%
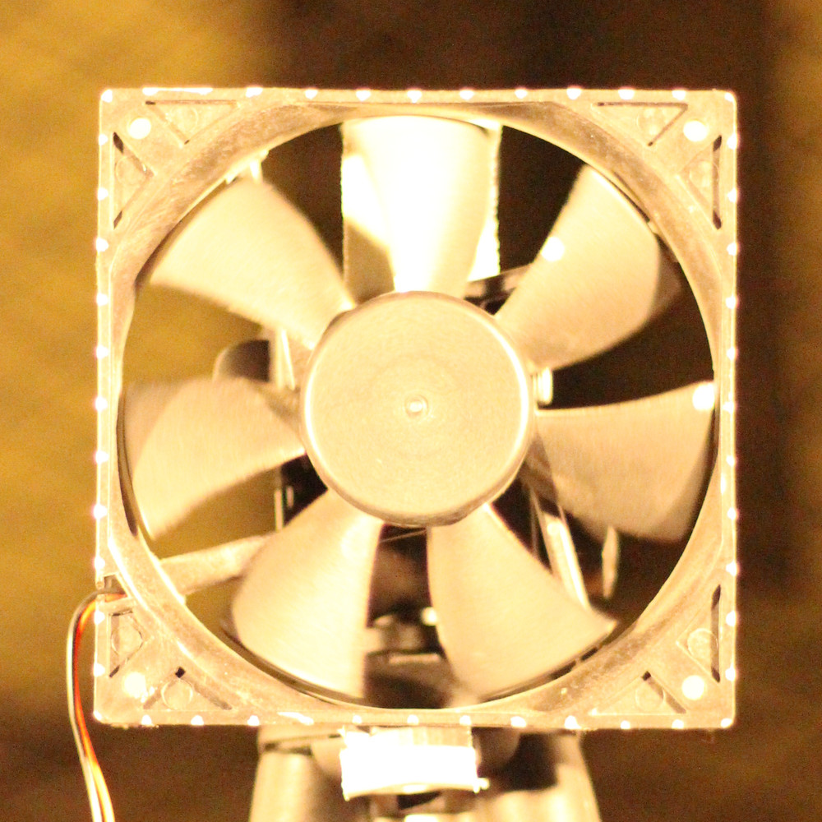
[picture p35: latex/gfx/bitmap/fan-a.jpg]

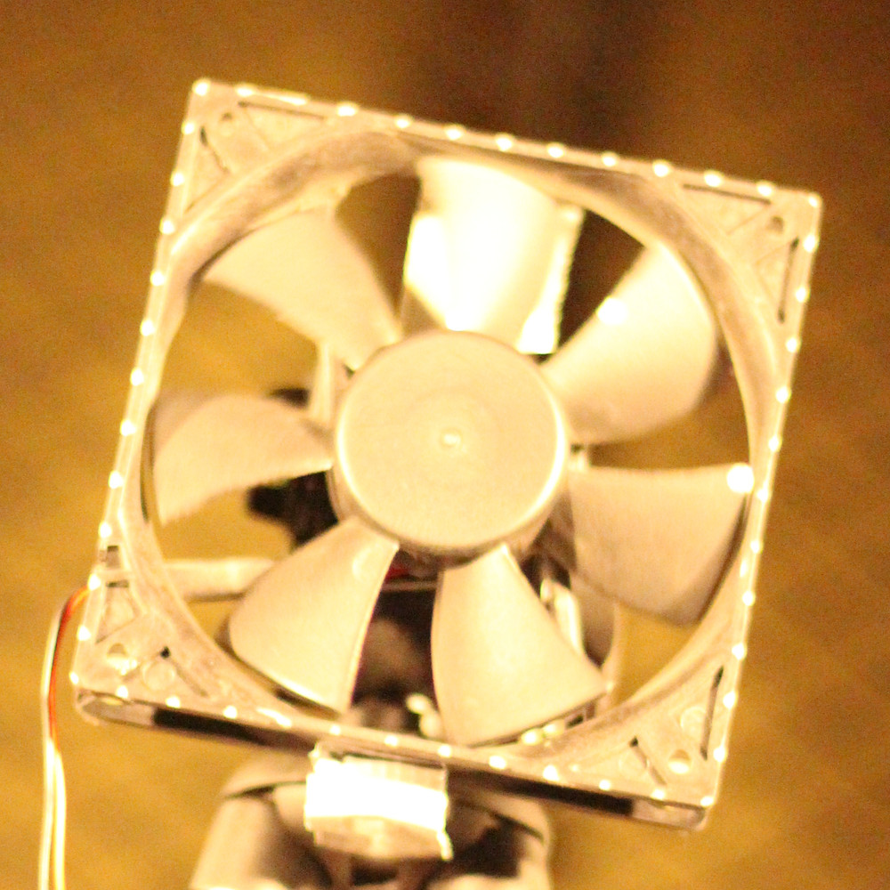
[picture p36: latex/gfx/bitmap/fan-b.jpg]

}{fig:fansynctest}{
	Frames from two cameras in a synchronization test with a PC fan.
	A marking on the end of a fan blade can be seen in the right side.
	The position of the marking does not differ distinctively in the pictures.
}

\subsubsection{Video capture}

% intro

The EOS 700D does not support an external clock signal for timing the frames in video recording, but relies on an accurate internal clock to sync the frames within a single video file.
It can be assumed that the clock speed has little variation, and thus, little drift or jitter occur in the videos during timespans of a few minutes.
Even if errors in a single clock were measurable, offsets would still be the dominant source of errors.
The processing time of each camera from the shutter button to start of first frame varies because of unknown reasons; even though a Canon wireless remote control was used for starting several cameras at once, the offset was found to be sometimes almost as much as the duration of two frames.

% what was done

Visual and audio-based tests were carried out to find variations in the recording offset.
Three cameras were triggered several times with a Canon RC-6 wireless remote control.
The remote sends a short infrared pulse to a sensor in the front of a camera when a button is pressed.
The cameras were set in video mode and configured to use the remote release.
%The exposure time was set to minimum, 1/4000 s, to maximise the rolling shutter effect.
%In this mode, the sensor rows are exposed one by one in succession.
When all cameras had started recording, a flash unit (Canon Speedlite 420EX) was aimed at the lenses and fired manually several times.

% what happens

A direct light pulse of a flash unit shows up as an over-exposed, completely white video frame, if the whole frame was exposing the image during the light pulse.
Sometimes only part of the frame would be exposed to the flash light as a rolling shutter effect.
Because the CMOS sensor is cleared and read line by line, the time of the flash can be deduced from the first bright line in the image.
The rows are zeroed from light in succession in the same way as a mechanical focal plane shutter moves and exposed until read.
Thus, the flash light's starting time in the video's internal clock is the frame's start time plus the duration that it takes for the rows before the overexposed one to show up:
\begin{align} \begin{split} \label{eq:timingcalib}
t_{Cl} &= t_{Ci} + t_{Cf} \\
&= F i_C + F f_C / R \\
&= (i_C + f_C / r c) F
\end{split} \end{align}
where $C$ is a camera identifier, $t_{Cl}$ is camera-relative time for the light pulse, $t_{Ci}$ is the starting time for the frame where the light shows up, and $t_{Cf}$ is the time inside the particular frame.
The frame index $i$ marks the number of the frame in the video file, starts from 0, and there are $F$ = $1/\text{fps}$ seconds between the frames.
$f_C$ is the first row exposed to the flash, $R = r / c$ is the time for a single row to expose, $r$ is the vertical frame resolution and $c$ is a correction coefficient describing the ratio of exposure time and frame duration due to rolling shutter ($0.5$ in this case, referring to a characteristic to the camera, as it exposes the first and last rows in half the time between frames).
Offset between two cameras $A$ and $B$ is then $t_{Al} - t_{Bl}$.
The timings are depicted in Figure \ref{fig:flashtimeline} as a timeline with matching symbols.

For perfectly synchronized videos, the frames would be identical, and time difference calculated with Equation \ref{eq:timingcalib} for each frame would be zero as $i_C$ and $f_C$ would be constants for all $C$.

\simplegfx{t}{0.95\textwidth}{flashtimeline}
{Illustration on timing calibration of two cameras using a flash light.
The darkened areas represent the exposure times and the red band represents the light pulse.
In this example, $c = 0.5$.
}

\simplefig{p}{%
\setlength\fboxsep{0pt}
\setlength\fboxrule{1pt}
\fbox{}%
\fbox{}%
\fbox{}
}{fig:flashtiming}{
	Video frames of three cameras started with the same remote controller, with the same frame index.
	The time for the flash unit to reach maximum brightness is almost instant.
	The start of the light pulse can be seen in the two last frames.
	In the first, the flash has been fired before the frame exposure started, and the frame shows the flash shutting down;
	the frame before it is without any overexposed light.
	It is impossible to deduce the exact time in this case.
}

\simplegfx{p}{\textwidth}{flashaudio}{
	Trimmed audio recordings near the same moment as in Figure \ref{fig:flashtiming}, extracted from the video files, in top-bottom order.
	First rows of the frames have been exposed at approx.\ $t = 0.03 \text{ s}$.
	The flash outputs a distinct ``pop'' sound, comparable to the start of the bright part in Figure \ref{fig:flashtiming}.
}

The method for measuring the synchronization error at a sub-frame precision can be used to calibrate the differences, which is useful in artificial sync with optical flow or other methods, where frame timing is used.
A similar method using the recorded audio (as in Figure \ref{fig:flashaudio}) is more used in video production \cite{pluraleyes,premierepromerge}, where similarities in the sound of the audio tracks recorded by the different cameras would be used for shifting the videos so that their clocks is in sync.
For a small number of cameras, the audio tracks are simple to align manually in an audio editing software, or automatically with cross-correlation to find the time lag.

In a work by Bradley et~al., a \emph{moving-object synchronization} method \cite{bradley2008markerless} was suggested for post-process video synchronization using a detection of a rotated calibration grid.
Bradley et~al.\ noted that sub-frame offset effects were not noticeable during moderately fast motion.
Optical flow was suggested for sub-frame synchronization if necessary.

Another method for triggering multiple video recordings is to use a Magic Lantern based wired remote trigger by pressing the half-shutter, or focus button when a record key has been configured in ML to start recording.
This method did not show any improvements in overcoming the offset, compared to the wireless remote.

A typical measurement result is shown in Figure \ref{fig:flashtiming}.
Audio recorded by the cameras' internal microphones at the same event is shown in Figure \ref{fig:flashaudio}, and the order of flash pulses in the three frames can be verified from the order of the sound emitted by the flash.
Both methods show that the leftmost camera has started recording last, as it has been recording the least amount of time of all three before the flash is seen.
Subsequent time lags compared to the first camera are approximately 21 and 31 milliseconds.
A relatively long exposure time was used.

From the results tested, it was deduced that the Canon EOS 700D implements exposure time in a similar way as a physical focal plane shutter with two artificial curtains, where the first curtain clears each particular sensor row, and the second curtain reads out the accumulated charge.
For a shorter exposure time, a shorter white overexposed line occurs in the video frames, but the scanning speed remains the same.
For this reason, decreasing the exposure time only helps in motion blur, but not in rolling shutter artifacts.

\subsection{Sample subjects} \label{sec:samplesubjects}

Test subjects were scanned using the system for validation and analysis.
Reconstruction was performed using two software pipelines.
Proposals for a typical scanning setup and minimum expected quality of instant results are shown in this section.
The results answer questions on what kinds of surfaces can be reconstructed well; different types of materials were selected for the datasets.
It was expected that areas with low variation in texture or high reflectivity would pose most problems.
No particular tuning of any algoritmic configuration parameters were tested, which suggests that higher quality than that presented here can be achieved with more careful work.
No makeup, light polarizers or any such improvements were tested; the subjects were photographed as-is in normal lighting.

The system is flexible to extend for complete body scanning with limited accuracy; tests for such subjects were left out due to lack of time and space in the hall where the system was used.
For a complete body, the methods are identical but as the distance to the subject is greater, less detailed geometry is expected to result.

\subsubsection{Photography setup}

The nine cameras were set up in a dark hall as a $3 \times 3$ grid and two flash units were attached to two cameras, directed up and down to a white styrofoam board and a fabric diffuser to soften the light.
The flash units were a Canon Speedlite 430EX and a Yongnuo YN565EX II, set to normal front curtain sync.
The top-facing Canon flash has only automatic mode, which was sufficient; the Yongnuo was set to manual full power, facing downwards to a piece of fabric.
The Canon EOS 700Ds have internal pop-up flash lights; they were not used, as they were found to trigger inconsistently, and they are relatively too bright and small so that shadows and highlights would pose problems.

A black background matte was used to isolate out unnecessary items in the background;
the textureless out-of-focus fabric has no particular features that would be detected, and its color is not particularly important, although chroma-keying with a green cloth is commonly used to isolate the subject already in the source images.
White styrofoam boards were left to the sides of the rig to help with lighting.
The general setup is shown in Figure \ref{fig:totalsetuptwo}, and a closer depiction of the poses of the cameras and the flash unit bounced from downwards are shown in Figure \ref{fig:frontview}.

\simplefig{p}{%

}{fig:totalsetuptwo}{
	Complete setup with cameras mounted on the stands, surrounded by 800 watt spot lights (red) for video recording tests.
	For photos, the cameras were closer to each other as shown in Figure \ref{fig:frontview}.
}

\simplefig{p}{%

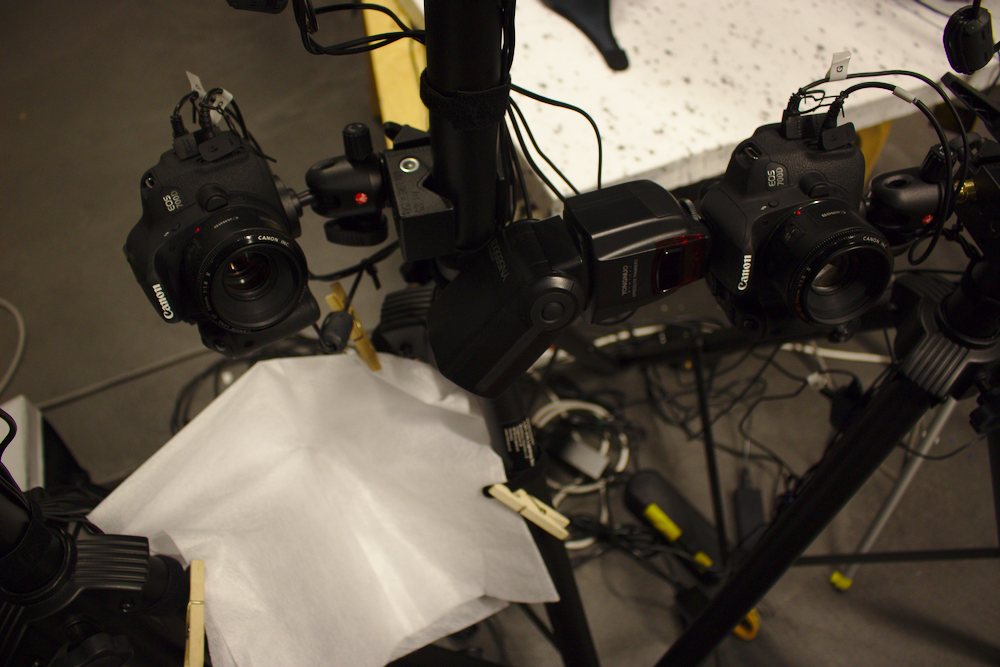
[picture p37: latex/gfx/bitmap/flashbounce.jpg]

}{fig:frontview}{
	Left: Poses of the cameras from the subject's viewpoint.
	Right: Flash gun bounced from a white cloth is used to evenly illuminate the bottom side of the subject.
}

The Bundler SfM system recommends to take photos at least every $\alpha = 15$ degrees around a subject \cite{bundlerfaq}.
Similar rough guidelines are usually suggested, such as a camera baseline of 10-20 \% of the distance to the subject.
% visualsize photomodel3d recommends 12 degrees http://www.visualsize.com/FAQ/3Dmodel.php
With a distance $s$ of one metre from lens to the subject, the Bundler guideline yields a baseline $b$ of approximately 26 cm by trigonometry: % Equation \ref{eq:baselinedegrees}:
\begin{align} \begin{split} \label{eq:baselinedegrees}
	\sin \alpha/2 &= \frac{b/2}{s}\\
	b &= 2 s \sin \alpha/2
\end{split} \end{align}

The key camera parameters used for photographing most samples are listed in Table \ref{tab:sampleshotparams}.
In a dark environment with flash lights, the exposure time is not particularly important for a static subject; the short flash pulse dominates all light in the scene.
The baseline was chosen by the guidelines proposed and by the difficulty in using the cameras in close proximity to each other.
Initially, a slightly longer baseline of approximately 50 cm was used; it was subsequently reduced to 30 cm.

\begin{table}[t]
	\centering
	\begin{tabular}{l l}
		Camera baseline & 30 +/- 5 cm\\
		Aperture size & f/14\\
		Exposure time & 1/20 s\\
		ISO sensitivity & 200\\
		Subject distance & 90 +/- 10 cm\\
		Lighting & Two flash heads bounced indirectly\\
		Focusing & Automatic\\
	\end{tabular}
	\caption{
		Key parameters in the sample photographs.
		Baseline refers to the distance to the nearest camera in the grid, horizontally and vertically.
	}
	\label{tab:sampleshotparams}
\end{table}

\paragraph{Reconstruction software}
The programs suggested in the previous section were used for evaluation due to their popularity and availability: PhotoScan \cite{photoscan} and VisualSFM \cite{wu2013towards}.
Both were run on a typical modern Linux installation.
A free demo version of PhotoScan was used, which does not support exporting the generated meshes; screenshots were taken in the user interface for illustration of results.
VisualSFM and the related software were built from source.

All photographs were captured using the developed software presented in the previous Section \ref{sec:implementation}.
Identical settings were configured on all cameras; JPEG mode was used and no post-processing was done on the PC.
Downloading the images in JPEG format from all cameras is done within seconds or less, depending on the USB hardware.
The developed software downloads data naively from each camera concurrently, leaving the USB data scheduling to the operating system.
% XXX (CMVS always resulted in only a single cluster due to the small number of views)
\subsubsection{Static subjects}

With the 18 million pixel count of the cameras, a human face is scanned with pore-level detail, and no markers are necessary.
Markerless capture has been suggested to be important for human subjects, as both the geometry and the texture can be scanned simultaneously, and variations of the texture over time are also seen when capturing video \cite{bradley2010high}.

The native resolution of each photograph obtained was $5124 \times 3456$ pixels; the subjects never filled the frame completely, but free space was left around them on purpose to make rotating and placing the subject easier.
Moreover, human subjects would typically not stay completely still.
The free space provides robustness that can be altered by bringing the subject closer to the cameras.
Approximately 25-30 \% of the pixel count was used for the subject.
For the final resolution of the color texture that was combined from all views, 4096 x 4096 pixels was used in the images that follow in this section.
The resulting accuracy of the color textures is easily determined by the physical size of the subject.
Assuming approx.\ 30 cm coverage (by Equation \ref{eq:areasize}) for the shorter image axis and a planar subject, image coverage would be $3456 / 300 \approx 11$ pixels per millimeter, or $\approx 0.09$ mm per pixel.
For the subjects tested, the accuracy was of the same order of magnitude.

\paragraph{PhotoScan results}
Using the source data shown partly in Figure \ref{fig:sample-arto-photoscan-source}, a point cloud and a textured mesh were generated in PhotoScan, using a quality setting of ``High''.
The workflow in PhotoScan is similar to that of VisualSFM and other tools based on separate programs:
initially, the scene structure is computed, resulting in a sparse point set of the subject and camera parameters.
A dense point set computation follows, and finally a textured triangle mesh is computed based on the dense points and the source images.
Spatially uniform quality in the point cloud suggests that PhotoScan's algorithm uses all cameras in a combined way, instead of, e.g., computing disparity maps in pairs and naively combining the pairwise built point clouds, which would be recognizable by visible boundaries on the surface.

\simplefig{t}{%
%
%

}{fig:sample-arto-photoscan-source}{
	Three of the nine source pictures for a typical scan;
	for a more optimized scan, the subject should be closer to the rig to use the full frame.
	Note the shadows under the chin, the nose, and near the eyes; only the top flash was used for this dataset for demonstration.
}

\simplefig{t}{%
%

}{fig:sample-arto-photoscan}{
	A dense point set (left) and a textured mesh in PhotoScan, matching the pictures in Figure \ref{fig:sample-arto-photoscan-source}.
	The underlying triangle mesh contains as much noise as the point set, which is hidden by the noiseless texture.
}

Figure \ref{fig:sample-arto-photoscan} depicts the results from a dense point cloud and a textured mesh based on the point cloud.
A typical face scan, with surrounding geometry removed, results in a high-density point cloud of 2-3 million points, which the software reduces into a textured mesh with exactly five times fewer triangles than the original points.
The meshing process was found to consume temporarily 4-5 GB of RAM on a typical human subject.

PhotoScan was found to be relatively robust to baseline length, reconstructing the scene geometry well with a baseline almost twice as much as the 15 degree rule suggested in Bundler with no apparent increase in accuracy or matching performance when the baseline is halved.
The tested reconstructions in PhotoScan have distinct spatial noise on all point sets and surfaces for unknown reasons, though.
By the console output of the mesh generation process, the meshing algorithm is probably based on Poisson surface reconstruction or similar octree based algorithm.

The resulting point set is dense enough to include medium wrinkles in the reconstructed mesh geometry, but with a well noticeable level of noise, larger than the smallest pore-level details seen in the photographs.
Medium-scale wrinkle detail tests can be seen in Figure \ref{fig:sample-arto-forehead}; the point cloud and the mesh have enough detail to encode forehead wrinkles in the geometry, in addition to the texture color which is actually unwanted and a cause of less than optimal lighting.

In Figure \ref{fig:sample-arto-photoscan-textures}, two of the texture mapping modes provided by PhotoScan are depicted.
A ``generic'' mapping mode with no distortion in the pictures produces piecewise texture islands with original photo content.
A ``spherical'' mode where the subject is assumed to be a sphere and the texture is made continuous but the original photos are warped shows as more intuitive and easier to modify manually if necessary.

%As seen in Figure \ref{fig:sample-arto-forehead}, the triangle mesh is more detailed than what would typically be used by an end-user; the small skin wrinkles that show as color variations would be rendered as variation in the texture color.
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

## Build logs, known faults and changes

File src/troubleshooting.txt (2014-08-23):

- no widget found exception?
	- verify that the camera mode selection wheel is on manual, otherwise e.g.
	  shutter speed cannot be changed
- camera ui (buttons, remote shutter) stuck after changing things?
	- run release-uilock.sh or replug usb or reboot cams
	- leave the focus button pressed when exiting paraphotos, then the cameras
	  won't lock the ui when quitting
- paraphotos not reacting to camera shutters?
	- do not start paraphotos when the focus button is down
- ui unlocked and still black screen?
	- push info button twice to cycle it back to the normal mode
- camera not saving pics on the memory card?
	- the capture target was internal ram, set back to memory card
	- forallp.sh --set-config capturetarget=1

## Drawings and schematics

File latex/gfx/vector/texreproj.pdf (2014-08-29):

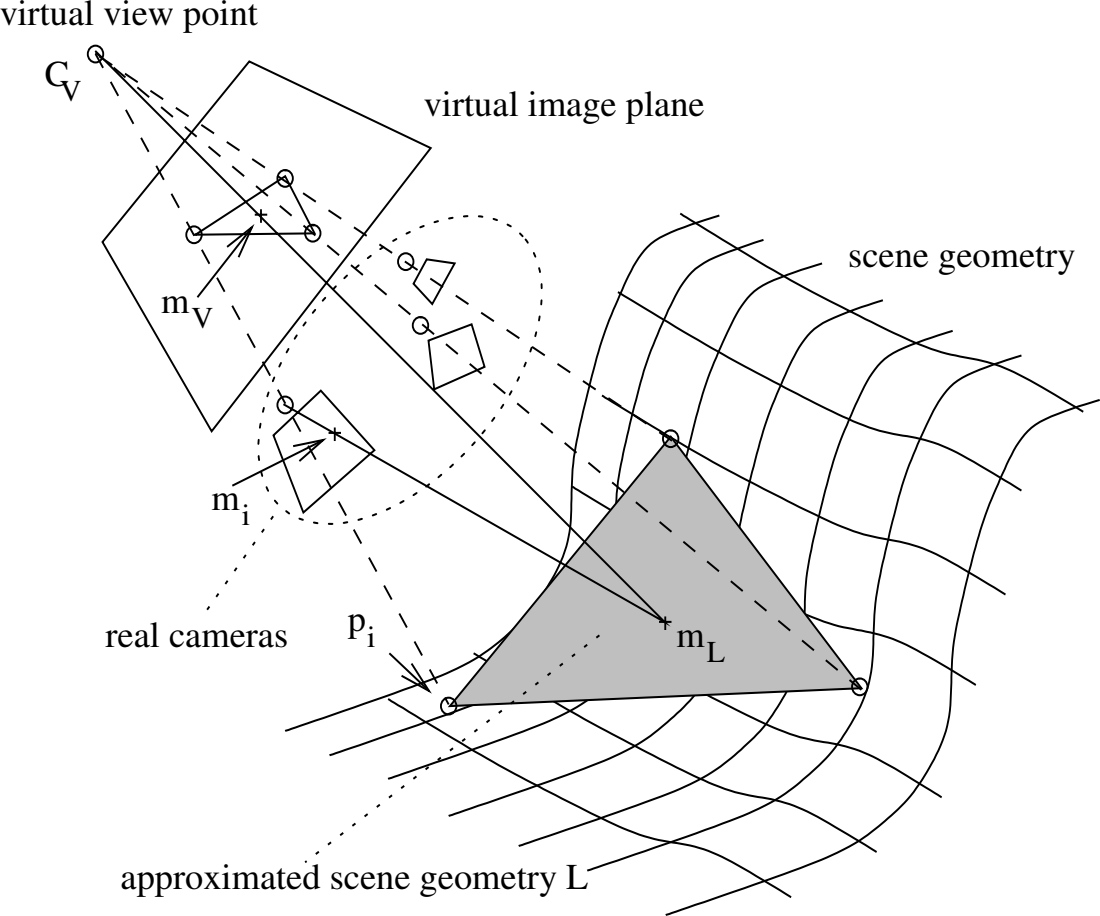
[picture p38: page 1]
virtual view point; scene geometry; real cameras

virtual image plane

approximated scene geometry L

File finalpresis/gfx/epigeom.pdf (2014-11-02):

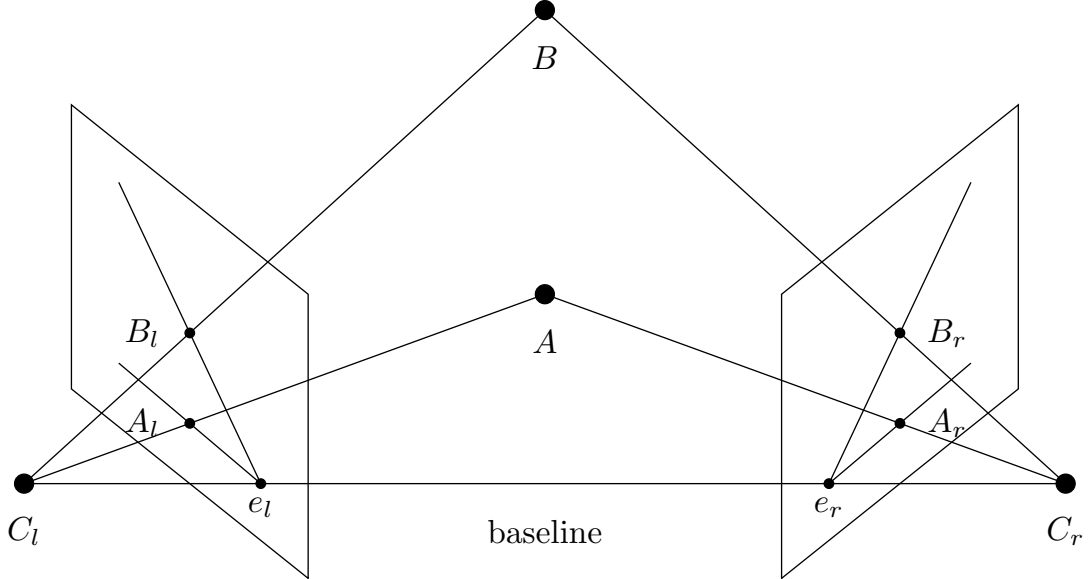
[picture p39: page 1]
baseline

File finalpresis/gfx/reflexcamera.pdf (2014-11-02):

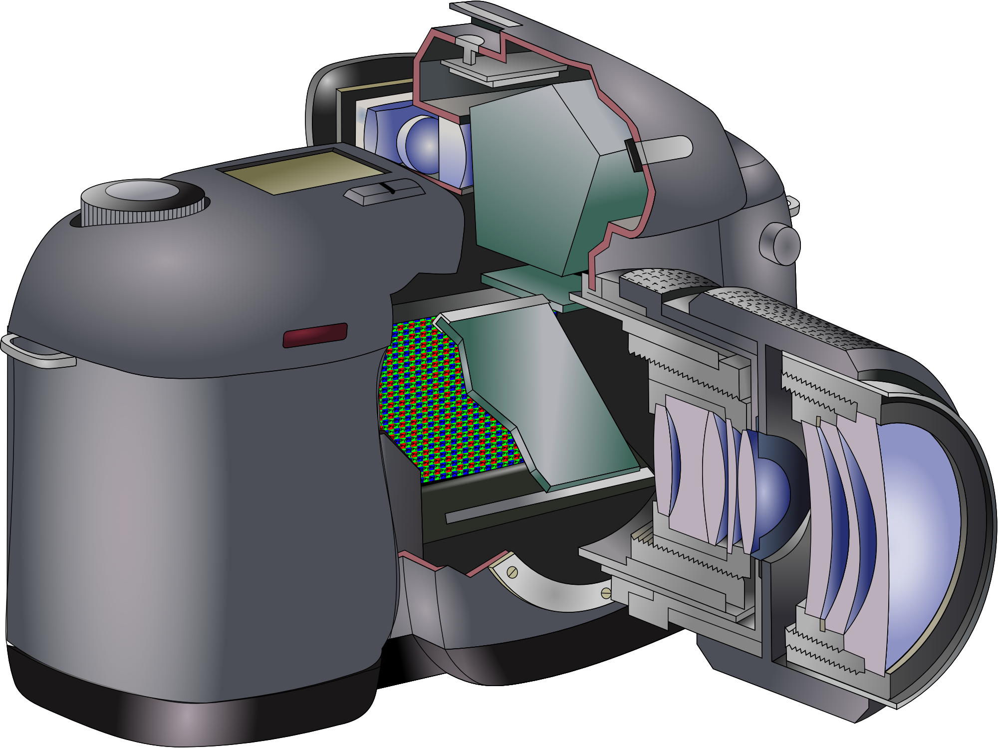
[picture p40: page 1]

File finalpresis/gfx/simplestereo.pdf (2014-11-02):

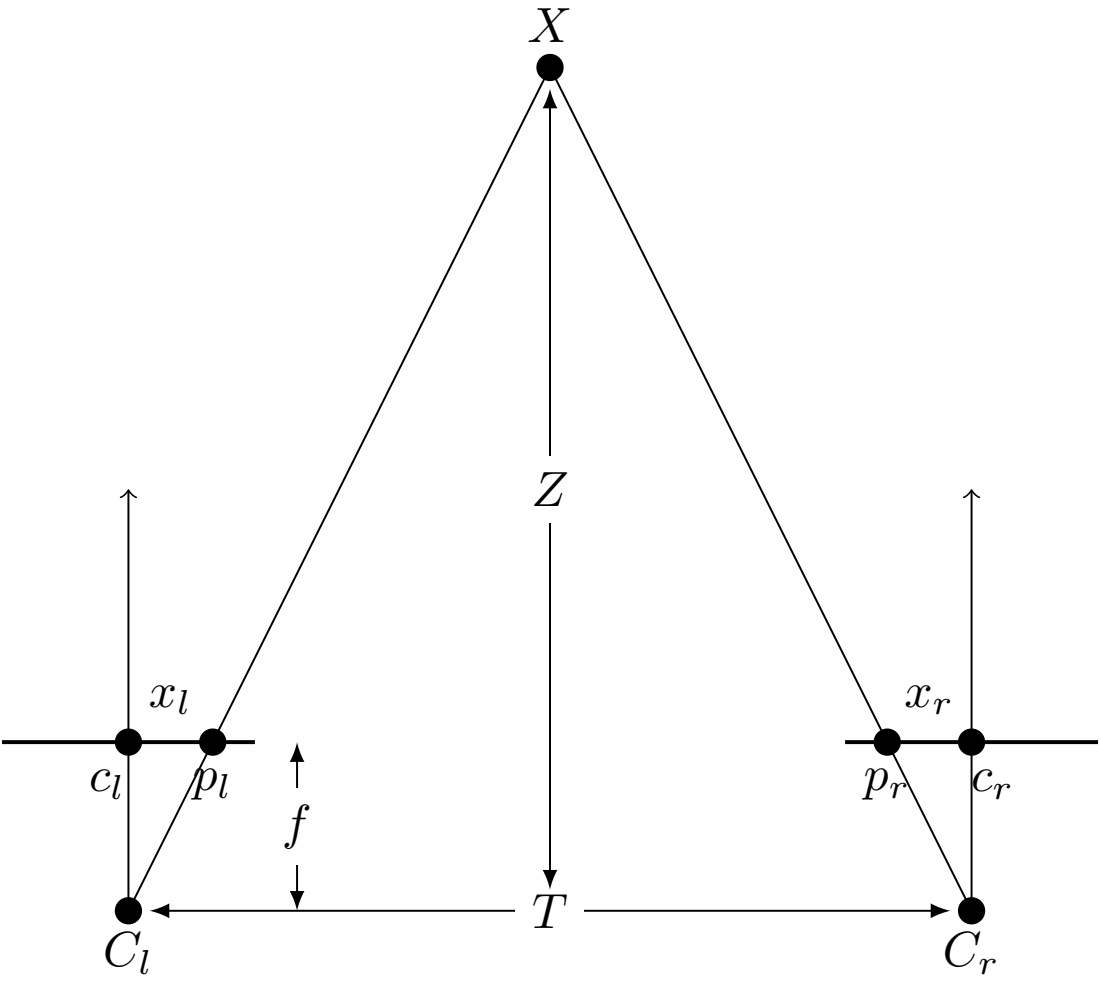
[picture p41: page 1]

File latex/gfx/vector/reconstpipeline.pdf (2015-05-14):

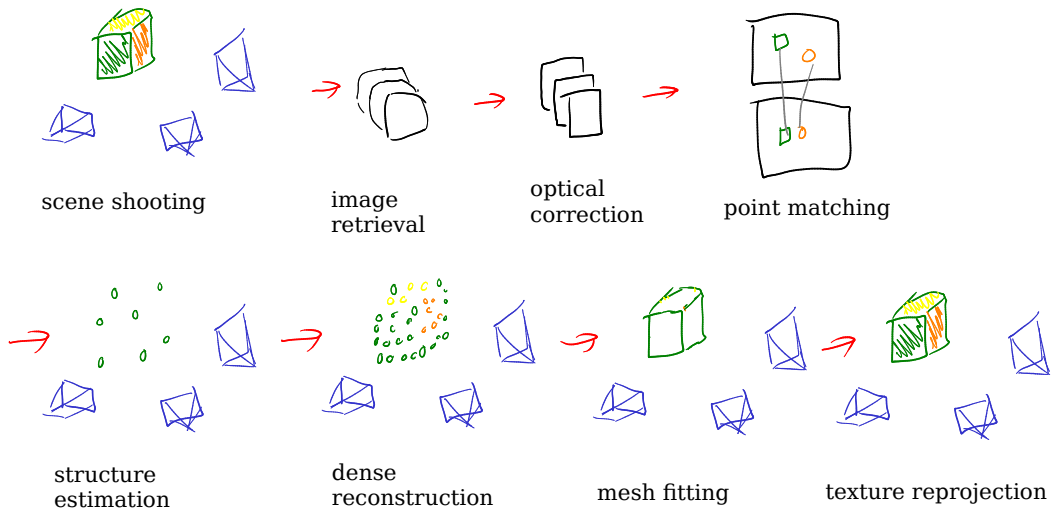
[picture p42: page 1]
scene shooting; image; retrieval; optical; correction; point matching; mesh fitting; texture reprojection; dense reconstruction; structure estimation

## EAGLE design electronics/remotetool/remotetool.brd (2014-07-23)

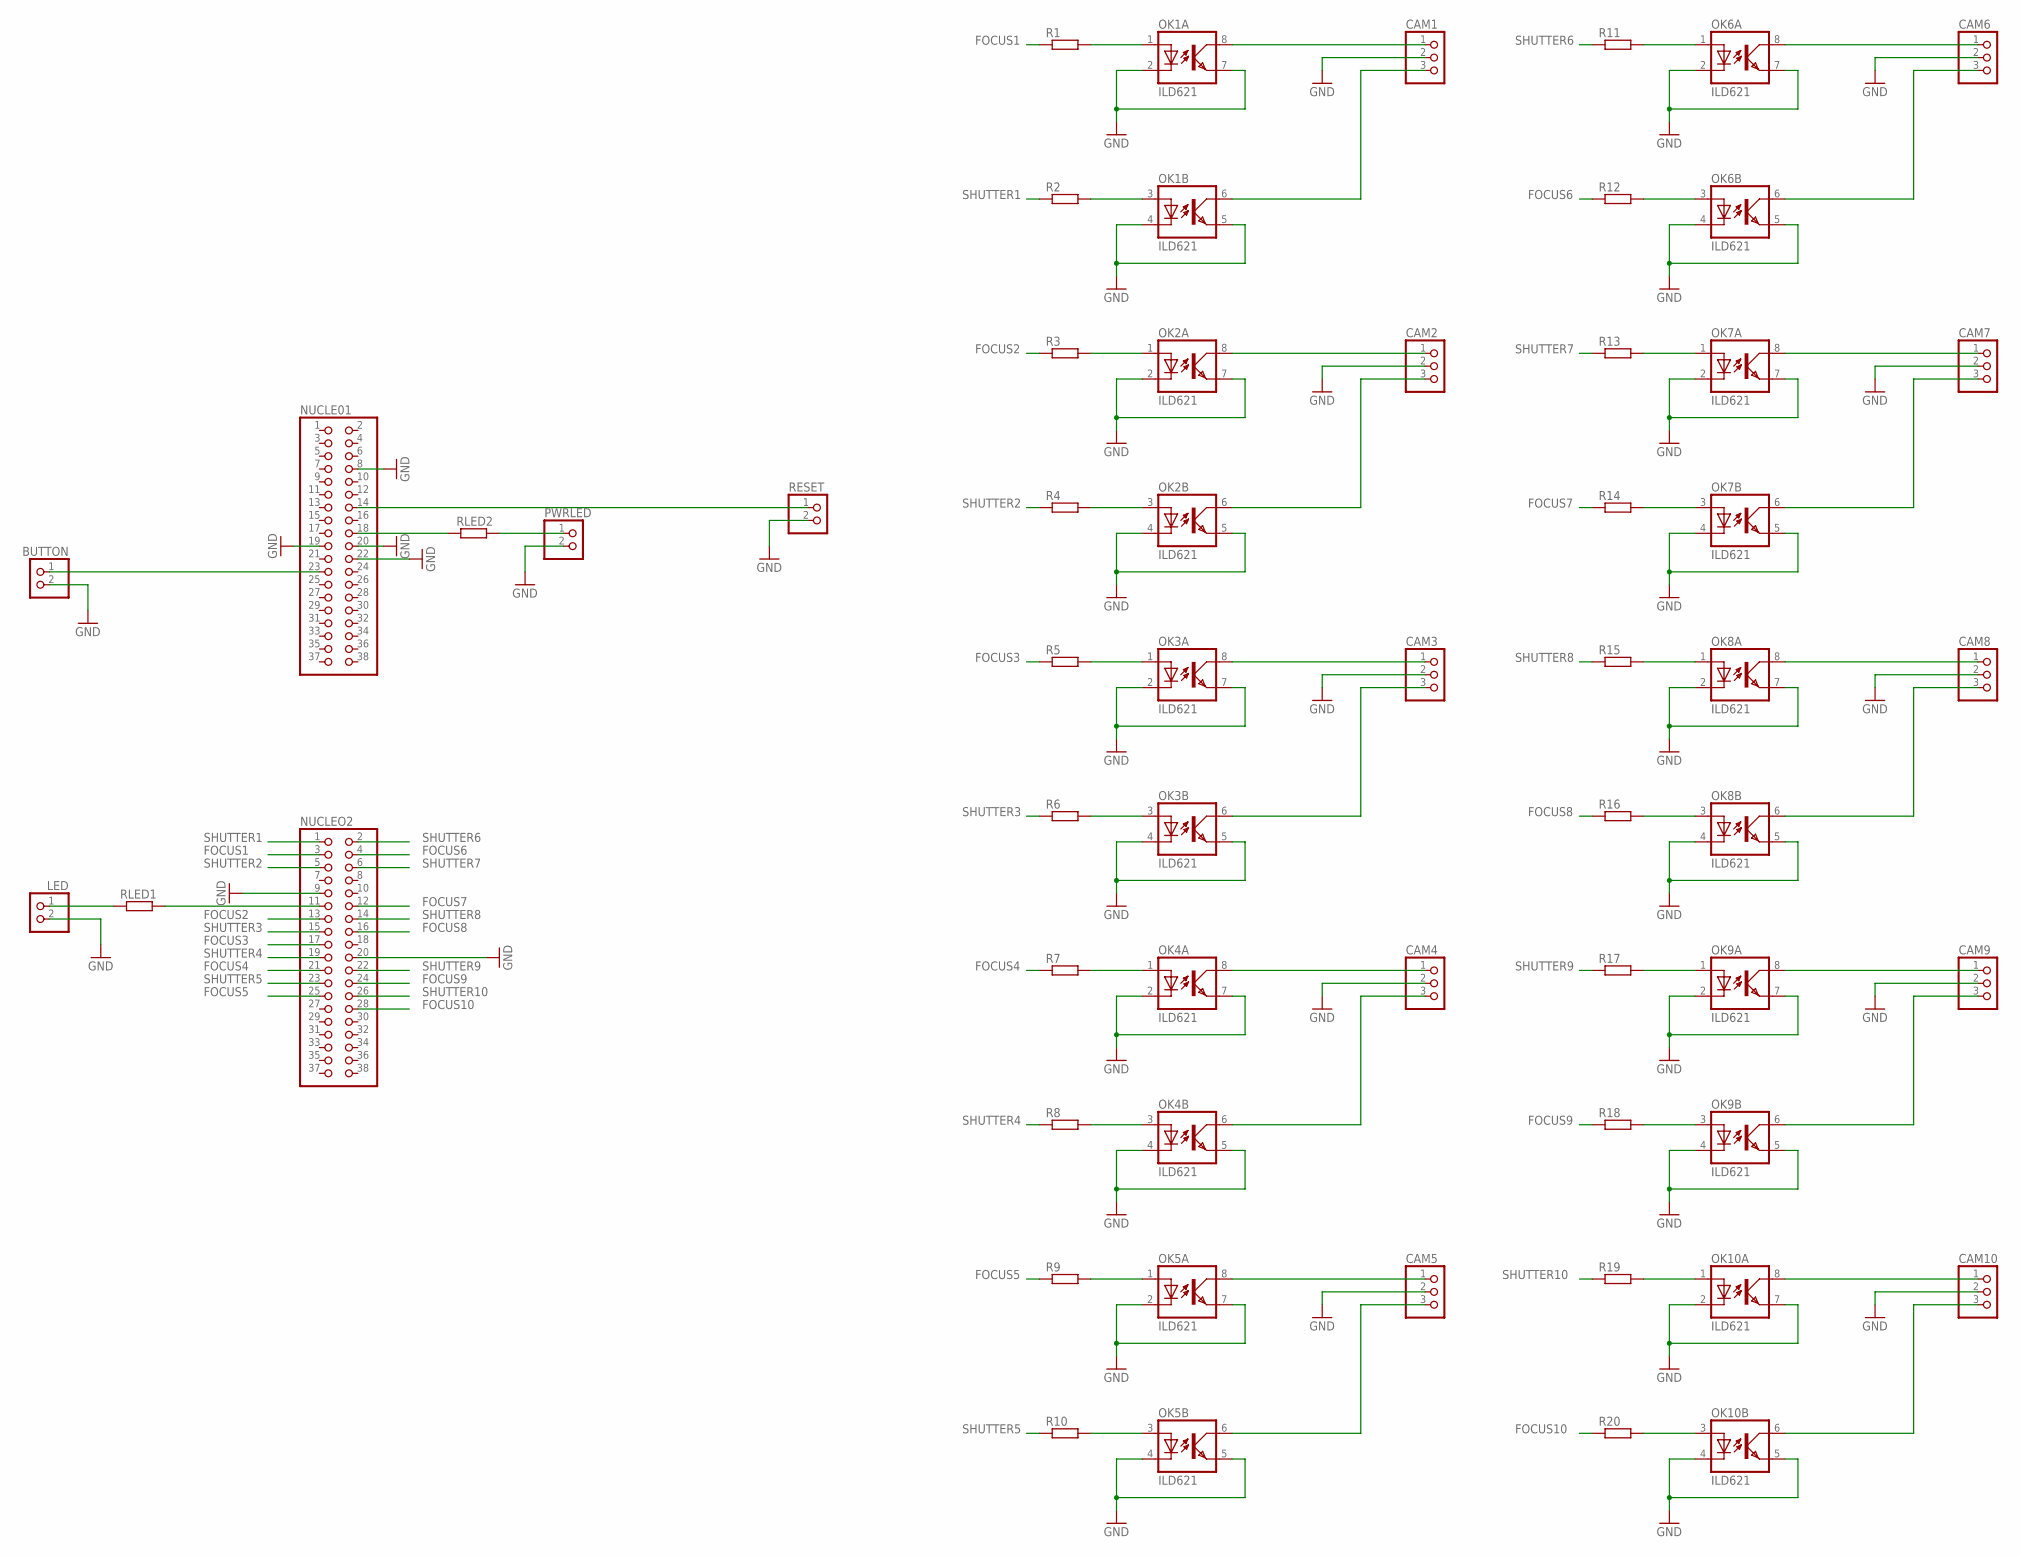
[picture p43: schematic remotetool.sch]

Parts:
BUTTON: PINHD-1X2; 1X02
CAM1, CAM2, CAM3, CAM4, CAM5, CAM6, CAM7, CAM8, CAM9, CAM10: PINHD-1X3; 1X03
LED: PINHD-1X2; 1X02
NUCLE01: PINHD-2X19; 2X19
NUCLEO2: PINHD-2X19; 2X19
OK1, OK2, OK3, OK4, OK5, OK6, OK7, OK8, OK9, OK10: ILD621; DIL08
PWRLED: PINHD-1X2; 1X02
R1, R2, R3, R4, R5, R6, R7, R8, R9, R10, R11, R12, R13, R14, R15, R16, R17, R18, R19, R20: R-EU_0207/2V; 0207/2V
RESET: PINHD-1X2; 1X02
RLED1, RLED2: R-EU_0207/2V; 0207/2V

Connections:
FOCUS1: NUCLEO2.3, R1.1
FOCUS2: NUCLEO2.13, R3.1
FOCUS3: NUCLEO2.17, R5.1
FOCUS4: NUCLEO2.21, R7.1
FOCUS5: NUCLEO2.25, R9.1
FOCUS6: NUCLEO2.4, R12.1
FOCUS7: NUCLEO2.12, R14.1
FOCUS8: NUCLEO2.16, R16.1
FOCUS9: NUCLEO2.24, R18.1
FOCUS10: NUCLEO2.28, R20.1
GND: BUTTON.2, CAM1.2, CAM2.2, CAM3.2, CAM4.2, CAM5.2, CAM6.2, CAM7.2, CAM8.2, CAM9.2, CAM10.2, LED.2, NUCLE01.8, NUCLE01.19, NUCLE01.20, NUCLE01.22, NUCLEO2.9, NUCLEO2.20, OK1.2 (C), OK1.4 (C), OK1.5 (EMIT), OK1.7 (EMIT), OK2.2 (C), OK2.4 (C), OK2.5 (EMIT), OK2.7 (EMIT), OK3.2 (C), OK3.4 (C), OK3.5 (EMIT), OK3.7 (EMIT), OK4.2 (C), OK4.4 (C), OK4.5 (EMIT), OK4.7 (EMIT), OK5.2 (C), OK5.4 (C), OK5.5 (EMIT), OK5.7 (EMIT), OK6.2 (C), OK6.4 (C), OK6.5 (EMIT), OK6.7 (EMIT), OK7.2 (C), OK7.4 (C), OK7.5 (EMIT), OK7.7 (EMIT), OK8.2 (C), OK8.4 (C), OK8.5 (EMIT), OK8.7 (EMIT), OK9.2 (C), OK9.4 (C), OK9.5 (EMIT), OK9.7 (EMIT), OK10.2 (C), OK10.4 (C), OK10.5 (EMIT), OK10.7 (EMIT), PWRLED.2, RESET.2
unnamed: OK1.1 (A), R1.2
unnamed: OK1.3 (A), R2.2
unnamed: CAM1.1, OK1.8 (COL)
unnamed: CAM1.3, OK1.6 (COL)
unnamed: OK2.1 (A), R3.2
unnamed: OK2.3 (A), R4.2
unnamed: CAM2.1, OK2.8 (COL)
unnamed: CAM2.3, OK2.6 (COL)
unnamed: OK3.1 (A), R5.2
unnamed: OK3.3 (A), R6.2
unnamed: CAM3.1, OK3.8 (COL)
unnamed: CAM3.3, OK3.6 (COL)
unnamed: OK4.1 (A), R7.2
unnamed: OK4.3 (A), R8.2
unnamed: CAM4.1, OK4.8 (COL)
unnamed: CAM4.3, OK4.6 (COL)
unnamed: OK5.1 (A), R9.2
unnamed: OK5.3 (A), R10.2
unnamed: CAM5.1, OK5.8 (COL)
unnamed: CAM5.3, OK5.6 (COL)
unnamed: OK6.1 (A), R11.2
unnamed: OK6.3 (A), R12.2
unnamed: CAM6.1, OK6.8 (COL)
unnamed: CAM6.3, OK6.6 (COL)
unnamed: OK7.1 (A), R13.2
unnamed: OK7.3 (A), R14.2
unnamed: CAM7.1, OK7.8 (COL)
unnamed: CAM7.3, OK7.6 (COL)
unnamed: OK8.1 (A), R15.2
unnamed: OK8.3 (A), R16.2
unnamed: CAM8.1, OK8.8 (COL)
unnamed: CAM8.3, OK8.6 (COL)
unnamed: OK9.1 (A), R17.2
unnamed: OK9.3 (A), R18.2
unnamed: CAM9.1, OK9.8 (COL)
unnamed: CAM9.3, OK9.6 (COL)
unnamed: OK10.1 (A), R19.2
unnamed: OK10.3 (A), R20.2
unnamed: CAM10.1, OK10.8 (COL)
unnamed: CAM10.3, OK10.6 (COL)
unnamed: NUCLEO2.11, RLED1.2
unnamed: BUTTON.1, NUCLE01.23
unnamed: NUCLE01.14, RESET.1
unnamed: LED.1, RLED1.1
unnamed: NUCLE01.18, RLED2.2
unnamed: PWRLED.1, RLED2.1
SHUTTER1: NUCLEO2.1, R2.1
SHUTTER2: NUCLEO2.5, R4.1
SHUTTER3: NUCLEO2.15, R6.1
SHUTTER4: NUCLEO2.19, R8.1
SHUTTER5: NUCLEO2.23, R10.1
SHUTTER6: NUCLEO2.2, R11.1
SHUTTER7: NUCLEO2.6, R13.1
SHUTTER8: NUCLEO2.14, R15.1
SHUTTER9: NUCLEO2.22, R17.1
SHUTTER10: NUCLEO2.26, R19.1

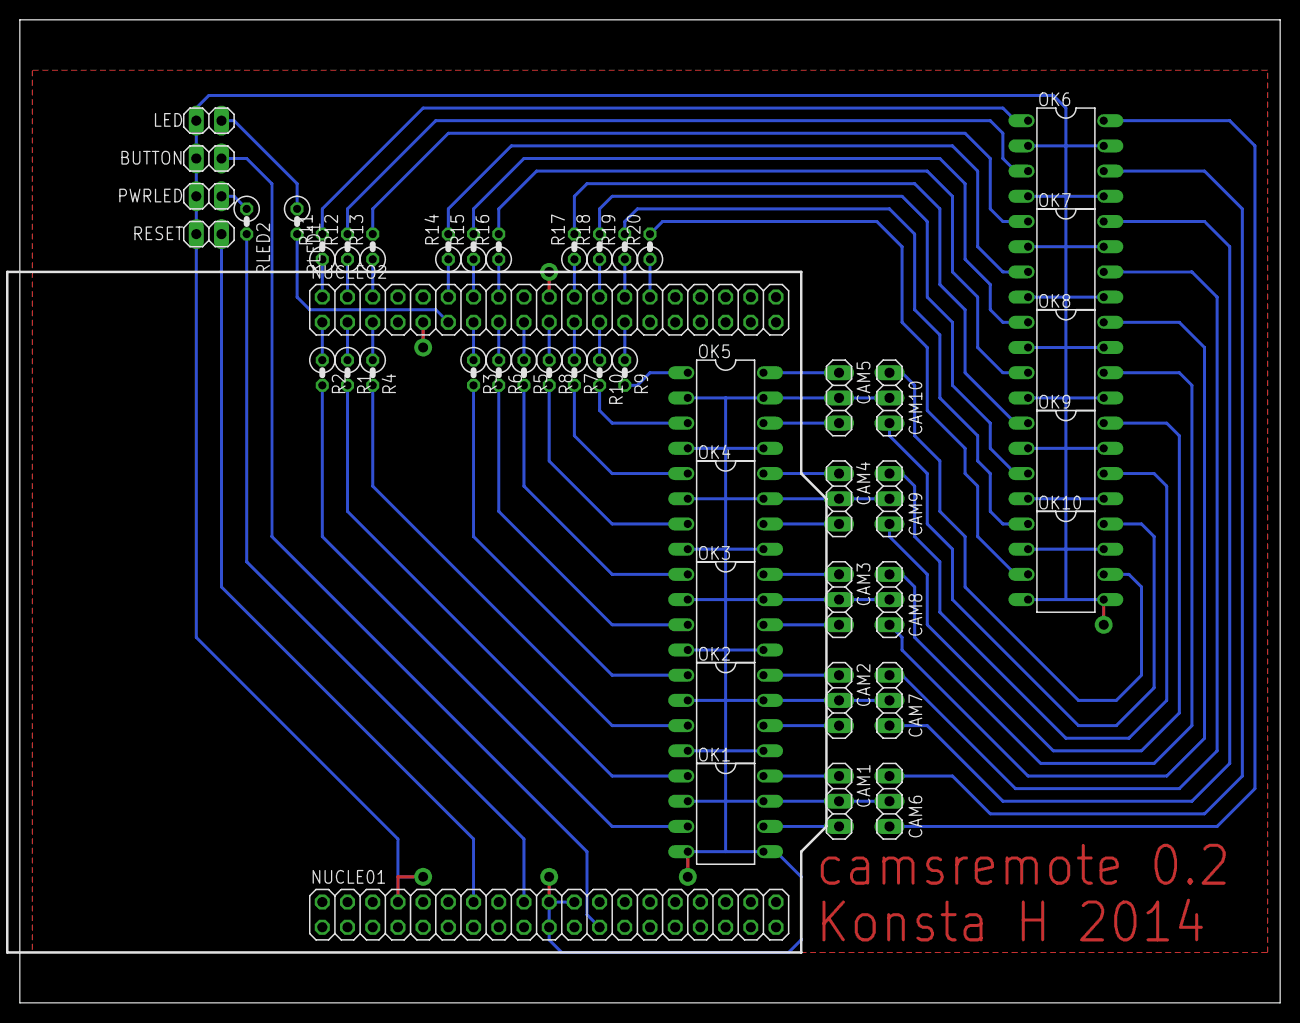
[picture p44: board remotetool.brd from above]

Board: 2 copper layers, 127.0 x 99.1 mm, 48 parts (0 on the bottom side), 67 nets.

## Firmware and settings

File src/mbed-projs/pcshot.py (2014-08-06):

"""Control all cameras separately; mbed needs pcshot.cpp"""
import serial
import argparse
import sys
import time

NCAMS = 9

class CameraControl:
    def __init__(self, port):
        self.ser = serial.Serial(port, 9600)

    def focus(self, cams):
        self._write("F", cams)

    def shoot(self, cams):
        self._write("S", cams)

    def shootstop(self):
        self._write("S", [False] * 9)

    def reset(self):
        self.ser.write("R\r\n")

    def _write(self, flag, cams):
        if len(cams) != NCAMS:
            raise IndexError("need %s cams" % NCAMS)
        bitmask = "".join("1" if x else "0" for x in cams)
        print flag + bitmask
        self.ser.write(flag + bitmask + "\r\n")
        self.ser.setTimeout(0.0)
        back = self.ser.read(1000) # flush needed?
        #print "<" + back
        # TODO b"lol"

def nonecams():
    return [False] * NCAMS

def allcams():
    return [True] * NCAMS

def onlycam(i):
    if i < 0 or i > NCAMS:
        raise ValueError("bad camera index")
    c = nonecams()
    c[i] = True
    return c

def parseargs():
    parser = argparse.ArgumentParser(description="control eos cameras remotely",
            formatter_class=argparse.ArgumentDefaultsHelpFormatter)
    parser.add_argument("-d", "--device",
            help="serial device to use", default="/dev/ttynucleo0")
    parser.add_argument("-r", "--repeat",
            help="repeat count (1=only once)", type=int, default=1)
    parser.add_argument("-w", "--wait",
            help="wait delay between repeats", type=float, default=1.0)
    parser.add_argument("-m", "--mask",
            help="bitmask of 0s and 1s, 1 to enable cam", default="111111111")
    parser.add_argument("-f", "--focuswait",
            help="delay between focus button and first shutter press", type=float, default=1.0)
    parser.add_argument("-i", "--interwait",
            help="inter-camera delay to shoot in succession", type=float, default=0.0)
    return parser.parse_args()

def normalrepeat(ctl, args, mask):
    for r in range(args.repeat):
        if r != 0:
            time.sleep(args.wait / 2)
        ctl.shoot(mask)
        time.sleep(args.wait / 2)
        ctl.shootstop()

def cyclerepeat(ctl, args, mask):
    # reversed because from lsb to msb
    indices = list(reversed([i for i, enabled in enumerate(mask) if enabled]))
    for r in range(args.repeat):
        if r != 0:
            time.sleep(args.wait)
        for i, camid in enumerate(indices):
            if i != 0:
                time.sleep(args.interwait)
            ctl.shoot(onlycam(camid))

def run(args):
    if len(args.mask) > NCAMS:
        print "too many cameras in mask"
        return 1

    mask = [x == "1" for x in args.mask]
    # control uses lsb mask as 0, but for the user, using first as 0 is more intuitive
    mask = list(reversed(mask))
    mask = [False] * (NCAMS - len(mask)) + mask

    ctl = CameraControl(args.device)

    try:
        ctl.focus(mask)
        time.sleep(args.focuswait)

        if args.interwait == 0.0:
            normalrepeat(ctl, args, mask)
        else:
            cyclerepeat(ctl, args, mask)
    finally:
        ctl.reset()

def main():
    sys.exit(run(parseargs()))

if __name__ == "__main__":
    main()

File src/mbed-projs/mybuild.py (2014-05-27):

#!/usr/bin/python2
import sys
import os

wd = os.path.dirname(os.path.realpath(__file__))

# this should be a symlink to git-mbed that contains at least
# build/mbed and workspace_tools
mbeddir = wd + "/mbed-lib"
sys.path.append(mbeddir)

import workspace_tools.targets
import workspace_tools.build_api

projdir = sys.argv[1]

libdir = mbeddir + "/build/mbed"
srcdir = wd + "/src/" + projdir
#builddir = wd + "/builds/" + projdir
builddir = wd + "/builds"
target = workspace_tools.targets.TARGET_MAP["NUCLEO_F401RE"]
toolname = "GCC_ARM"
v = False

workspace_tools.build_api.build_project(srcdir, builddir, target,
        toolname, [libdir], clean=True, verbose=v)

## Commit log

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2014-05-02 src: aperture widget, actually save the widgets
    own class for aperture radio widget setting
    widgets are stupid independent data structures, need to save them
    explicitly to camera with gp_camera_set_config()
2014-05-02 gpwrap: radio name string to class obj
    gphoto/camera string of radio choices for generic awesomeness
    (it's probably different on different cameras; if, then traits)
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2014-05-05 gpgrid: fps counter
    obviously the update speed reduces when camera count increases; need to
    parallelize preview reading (if gphoto2 is threadsafe enough)
2014-05-06 gpgrid: move grabbing to separate threads for fps
    also checkbox for synchronizing threads; doesn't seem to make a
    difference with two cameras as gphoto/usb/cameras are so undeterministic
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2014-05-08 gpgrid: init atomics, use size member
    construct atomics to initialized values (their default ctors do not).
    also use local size member instead of camera array size for clarity.
2014-05-08 gpgrid: threadsafe gp::camera with mutex locking
    configs and preview loading at the same time from different threads
    makes all go -110 (I/O in progress)
2014-05-09 gpgrid: set new camera configs in parallel
    nine cameras is kind of slow to update
2014-05-09 gpwrap: do not fill the rest of cams with last
    serious business now, have to easily see how many cameras we have
2014-05-09 gpwrap: remember timeline follow when reseting it
    slight bugfix for when new cameras resets the timeline
2014-05-16 gpwrap: events, debuglog envvar, test cleanup
    listen to gphoto camera events from ptp. note that the event data must
    be freed by the caller.
    many events have the unknown id and would need patching to be really
    useful, e.g. property changes are often simple settings with same ptp
    codes as in camlibs/ptp2/config.c's menu, such as aperture (d101) or iso
    (d11b). d17c seems to be a unix timestamp, it's different every time.
    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
2014-05-27 src: multi-snapshot tool for mbed
    just send focus and shutter signals to multiple pins at the same time,
    or sequentially to fool around and blink flashes.
    the pins are connected via 220 ohm resistors to TLP621 optocouplers.
2014-05-27 src: shutter lag measurement
    hot shoe connects the middle pin to ground. use pull-up resistor and
    wait for falling edge, timing the delay between shutter release button
    and flash.
    eos 700D: ~76 ms for full f/1.8 aperture, same for f/10, ~79 ms for f/22
2014-05-27 gpgrid: timeline bugfix, make point list ordered
    previewfeed's camera queues are not ordered in any way; would need to
    sort their points or just assume in timeline.insert() that the given
    point is bad.
2014-05-27 tex: image sensors sync
    nothing new about image sensors. comparison and benefits?
2014-05-27 tex: shutter text sync
    syncing with flashes, compare to continuous light; light sensor for film
    cameras, ISO speed, lag not so important if consistent among cameras,
    video goes elsewhere
2014-05-27 tex: video text sync
    this section needs refactoring to be more concise. divide original text
    into orthogonal problems and effects - frame rate, humans and motion
    perception, syncing and video formats and their compression.
2014-05-27 tex: camera selection sync
    TODO some story and references to measurements; meaning and importance
    of measurements vs. ease of use and practicality; less general story and more
    facts and tables; conclusion section?
2014-05-28 tex: cam calibration sync
    this needs a picture too and minor refactoring, see matlab cam calib
    toolbox for picture ideas
2014-05-28 tex: normalization sync
    this section is quite disconnected, maybe merge to another somewhere? or
    write a more general section about common background on calibration?
2014-05-28 tex: rectification sync
    not much here, need illustrative pics and samples of actual rectified images
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2014-06-23 tex: fix bayer special case corners
    tikz scale something else than 1 fuxors cycles or something
2014-06-26 mbed: more controllable pcshot; cycle repeater
    make both focus and shutter buttons fully controllable from pc, like:
    Fabcdefghijk
    Sabcdefghijk
    where a-j are per-camera button bits, 0 or 1.
    R resets everything.
    Python stuff repeats same set for several cameras or cycles all cameras
    interleaved together.
    [pcshot.py]
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2014-06-26 tether: add 700d config lists
    manual mode does not have recording destination (it's disabled); in
    video mode it has choices for card and none.
    video mode lacks evfmode, focus mode, metering mode, and auto exposure
    bracketing.
    [700d-all-config-moviemode.txt]
2014-06-26 mbed: whoops, shorten button wait time
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2014-07-02 tether: add 700d moviemode liveview configs
    differs from normal mode at least in available shutter speeds
    [700d-all-config-moviemode-liveview.txt]
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2014-07-03 gpwrap: free camera list in all_cameras()
    memory leak
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2014-07-03 gpwrap: wrap gphoto object creation for unique_ptr
    wrap gphoto's construction functions to get both syntactic sugar and
    unique pointer safety.
    gphoto creates stuff with
    Foo* obj;
    if (gp_foo_new(&foo) < GP_OK)
    handle_error();
    wow, so many lines of code. wrap it all and return a unique pointer so
    that we're safe to forget deletion - the objects have a consistent
    gp_foo_new and gp_foo_unref functions.
    The GP_NEW_UNIQUE macro provides function names for exceptions in case
    of allocation errors (as if it'd ever happen) and both creation and
    deletion.
2014-07-04 gpwrap: use plain _Type structs for gp's own types
    prevent accidental Camera usage instead of gp::Camera etc. because the
    raw names start with underscores.
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2014-07-16 gpgrid: app: sort cams by camera_order.txt
    read camera order from a text configuration file instead of using an
    arbitrary order from the autodetection. easier to find the correct
    camera when they are set up as a grid IRL too.
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2014-07-22 prototype for canon remote tool schema and board
    no more hazard dangling wires and breadboard: implement schematics and
    pcb for the wired multi-camera remote shutter controller as an eagle
    project. fits snugly in a used aluminium case found randomly in AS
    electronics lab.
    [remotetool.brd, remotetool.sch]
2014-07-23 remotetool: simplify ground signals
    - rearrange ground signals a bit, remove most top layer traces
    - make it possible to route in a single layer, add ground polygon to
    bottom layer too
    - leave some vias for top ground plane
    [remotetool.brd, remotetool.sch]
2014-07-23 remotetool: rename second half as it should be
    The second half of connectors is kind of mirrored from the optocoupler
    point of view; rename signals so that all connectors are facing the same
    way when installing. Also make the borrom row labels readable.
    [remotetool.brd, remotetool.sch]
2014-07-23 remotetool: rearrange schematic by board
    move the optos around so that their order matches with the physical
    connectors, reducing confusion.
    [remotetool.sch]
2014-07-23 remotetool: add nucleo dimensions to board
    approximate dimensions of the nucleo board on the grid, +/- 0.5mm or so
    [remotetool.brd]
2014-07-23 camsremote: version bump
    increase the version number printed on the board
    [remotetool.brd]
2014-07-23 mbed: pcshot: update pinouts for new board
    swap focus and shutter because this layout worked better on the pcb
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2014-07-24 tether: ignore aeb because not working with flash
    - with pop-up flash up, the camera refuses to touch the aeb config
    - also implement error checking for readconfig.sh when getting some
    configs fails
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2014-10-28 gpgrid: fix main frame title
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2015-05-10 tex: tidy up references
    cleanup mistakes in the generated bibtex and cut urls at a hyphen
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
